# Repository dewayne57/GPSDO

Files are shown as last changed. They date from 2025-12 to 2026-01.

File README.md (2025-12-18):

# GPSDO (GPS Disciplined Oscillator)

This repository contains a hardware and firmware design for a GPS-disciplined oscillator (GPSDO). The system uses
a local oven-controlled crystal oscillator (OCXO) disciplined by a GPS reference (1PPS and time) via a digital control
loop implemented on a PIC microcontroller.

Purpose: provide a compact, buildable GPSDO that combines the short-term stability of an OCXO with the long-term
accuracy of GPS. The design favors through-hole assembly and flexible OCXO support so hobbyists and technicians can
adapt the board to available oscillators.

**Repository layout**
- `Hardware/`: KiCad schematics and PCB files, and OCXO compatibility notes.
- `Software/`: PIC firmware source (`main.c`, `isr.c`, config and peripheral drivers).

**Key features**
- Uses a PIC18F series microcontroller for the digital control loop and measurement counters.
- Supports 5 V and 12 V OCXO modules with jumper-selectable scaling.
- External DAC (12-bit) for fine VCO control; optional use of OCXO internal reference.
- Sine-to-square conversion option for sine-output OCXOs.
- Outputs: 10 MHz (square), 1PPS, and serial time/status (where supported).

Hardware notes
- OCXO compatibility: designed for OCXO modules that expose a VCO (frequency adjust) input. Modules without a VCO
	pin are not supported.
- Recommended OCXO families (examples): Bliley N47/NV47, IsoTemp 141 A/N, Vectron C4550, Oscilloquartz 8663.
- VCO adjustment: typical adjustment ranges are on the order of ±0.4 to ±1.0 ppm. For a 10 MHz OCXO, ±0.4 ppm
	corresponds to about ±4 Hz of pull range.
- Voltage reference: jumpers allow either the OCXO's onboard reference or the microcontroller-supplied reference to be
	used for VCO control circuitry.
- Power: supports 5 V and 12 V OCXO modules. The design omits 3.3 V OCXO variants to keep voltage-scaling circuitry
	simpler.

Firmware and control
- The PIC microcontroller implements the digital disciplining loop: it measures phase/frequency against GPS 1PPS and
	computes corrections applied through the DAC to the OCXO VCO input.
- Communication: firmware includes basic status reporting via serial (see `Software/` source files).

## Theory of Operation

Overview
- The system uses the PIC18F's high-speed signal acquisition timer/counter to measure the OCXO frequency against the GPS
	1PPS reference. The 10 MHz output from the OCXO (after conditioning through comparator or buffering as needed) is fed
	into the controller's counter. Each rising edge of the 1PPS signal triggers a capture of the counter value.

Measurement and error calculation
- The counter measurement produces the number of 10 MHz cycles counted during one 1-second interval. For an ideal
	10 MHz oscillator the measured count is 10,000,000. The firmware computes the frequency error as:

	`error = measured_count - 10,000,000`

- Control action sign: when `measured_count > 10,000,000` (oscillator fast) the firmware decreases the DAC output
	(reducing VCO control voltage) to lower the oscillator frequency. Conversely, when `measured_count < 10,000,000`
	(oscillator slow) the firmware increases the DAC output to raise the frequency.

Resolution and averaging
- A single 1-second count has 1 Hz quantization (one extra or missing cycle = ±1 Hz). Because the OCXO VCO pull range
	is often a few Hz, and long-term stability targets are well below 1 Hz, the firmware uses averaging and filtering
	across multiple 1‑second samples to resolve sub-Hz frequency offsets. Averaging N seconds reduces quantization noise by
	roughly `1/sqrt(N)` for uncorrelated noise and linearly for simple accumulation.

Digital control loop
- The control loop is implemented in firmware and is PID-like: it applies a proportional term (responds to the
	instantaneous frequency error), an integral term (eliminates steady-state offset over time) and optional damping
	(derivative-like or filtered difference) to stabilize transient responses.
- To avoid overshoot and instability, the loop includes:
	- limited update rate and maximum DAC-step per update,
	- anti-windup on the integrator when the DAC saturates,
	- configurable loop bandwidth (slow for best long-term stability, faster during initial acquisition).

Noise and spurious rejection
- Input conditioning: if the OCXO provides a sine output, it is converted to a clean logic edge via the comparator and
	Schmitt trigger chain (comparator `U401`, logic buffers), which reduces timing jitter and false counts.
- Outlier rejection: the firmware detects and ignores single-sample glitches (spikes) using median filters, clamp
	thresholds, or by discarding samples with implausible changes.
- Low-pass filtering: measurement samples are filtered (moving average or IIR) before being fed into the control law to
	reject short-term noise and spurious phase jitter from the GPS receiver or RF pickup.

DAC mapping and VCO sensitivity
- The external DAC (12-bit) produces the control voltage applied to the OCXO VCO pin (optionally scaled by jumper
	networks for 5/12 V OCXOs). The frequency change per DAC LSB depends on the OCXO sensitivity (Hz per volt). The
	firmware maps desired frequency correction to DAC steps and can be configured for the measured sensitivity of a
	particular OCXO.
- Because frequency pull is small (few Hz), the DAC mapping and loop gains are tuned to provide fine, stable control
	without hunting.

Holdover and failure modes
- If GPS is lost, the firmware stops updating the DAC with GPS-derived corrections and enters a holdover mode. During
	holdover the DAC will be left at its last value.
- GPS lock is indicated by a front-panel LED.  If the GPS lock is lost, the operator should take the appropriate 
    actions to reposition or repair the GPS antenna.

Practical notes
- One-count resolution at 10 MHz corresponds to 1 Hz. To achieve sub-Hz apparent resolution the firmware averages and
	filters multiple 1PPS-captured counts before making DAC adjustments.
- Avoid using OCXO modules without an external VCO adjust pin — they cannot be disciplined by this design.
- Proper grounding, shielding, and clean supply rails reduce spurious counts and improve loop stability.

Build and usage
- Hardware: assemble the board following the silkscreen and BOM in `Hardware/`. Populate only the sections required for
	your chosen OCXO (jumper options allow omitting comparator/driver or scaling components).
- Antenna: mount the GPS antenna with a clear sky view; use a low-loss cable and proper grounding/lightning protection.
- Initial setup:
	1. Install firmware from `Software/` using a PIC programmer supporting the PIC18F family.
	2. Connect GPS antenna and power the board.
	3. Wait for GPS lock and allow the disciplining loop to converge (can take minutes to hours depending on configuration).
- Holdover: if GPS signal is lost, the OCXO runs free; holdover performance depends on the OCXO quality.

Testing and calibration
- Verify 1PPS and 10 MHz outputs with a frequency counter or scope.
- Observe DAC control voltage and confirm it stays within expected range while disciplining.
- Perform a holdover test by disconnecting GPS and measuring drift over a chosen interval.

Design considerations and limitations
- GPS vulnerability: system depends on GPS; consider anti-spoofing/jamming mitigation for critical deployments.
- Environmental sensitivity: OCXO performance varies with temperature — good thermal control improves holdover.

Contributing
If you improve the firmware, PCB, or documentation, please open an issue or a pull request. Include a short description
of your changes and validation steps.

License and credits
- This entire repository (software and hardware design files) is licensed under the Apache License, Version 2.0. See
  `LICENSE` at the repository root for the full text.
- If you incorporate third-party components with separate license requirements, include their required notices and
  follow the terms of those licenses.

Files of interest
- `Hardware/GPSDO.kicad_sch`, `Hardware/GPSDO.kicad_pcb`: primary schematic and PCB.
- `Software/main.c`, `Software/isr.c`, `Software/config.h`: firmware entry points and configuration.

Contact
Open issues in this repository or contact the author via the repository metadata for questions and contribution guidance.

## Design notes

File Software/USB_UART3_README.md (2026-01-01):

# UART3 USB Interface Configuration

## Overview
UART3 has been configured for USB serial communication on the PIC18F27Q43.

## Pin Assignments
- **RB2**: USB_TX (UART3 transmit output)
- **RB3**: USB_RX (UART3 receive input)

## Configuration Details
- **Baud Rate**: 115200 (configurable via `usb_reconfigure()`)
- **Data Format**: 8-bit, no parity, 1 stop bit
- **Buffer Size**: 256 bytes circular receive buffer
- **Clock Source**: System Fosc (64 MHz)
- **BRG Value**: 139 (for 115200 baud at 64 MHz)

## PPS (Peripheral Pin Select) Routing
```c
U3RXPPS = 0x0B;  // RB3 (pin 11) -> UART3 RX input
RB2PPS = 0x33;   // UART3 TX -> RB2 output
```

## API Functions (usb.h)
### Initialization
- `void usb_init(void)` - Initialize UART3 at 115200 baud
- `void usb_reconfigure(uint32_t baudrate)` - Change baud rate

### Transmit
- `void usb_send_char(char c)` - Send single character
- `void usb_send_string(const char *str)` - Send null-terminated string

### Receive
- `void usb_buffer_put_char(char c)` - Store received character (called from ISR)
- `char usb_buffer_get_char(void)` - Get character from buffer
- `bool usb_buffer_has_data(void)` - Check if data available
- `uint8_t usb_buffer_count(void)` - Get number of buffered characters

## Interrupt Service Routine
UART3 RX interrupt handler is defined in [isr.c](isr.c):
```c
void __interrupt(irq(U3RX), high_priority) uart3_rx_isr(void)
```

The ISR handles:
- Receive buffer overflow recovery
- Character buffering via circular buffer
- Interrupt flag clearing

## Files Modified/Created
1. **usb.h** - USB/UART3 interface header
2. **usb.c** - USB/UART3 implementation
3. **isr.c** - Added UART3 RX ISR
4. **config.c** - Added `usb_init()` call
5. **nbproject/Makefile-default.mk** - Added usb.c to build

## Current UART Usage Summary
- **UART1**: External serial/bootloader (RB3 TX, RB4 RX) - 115200 baud
- **UART2**: GPS communication (RB5 TX, RB4 RX) - 9600 baud
- **UART3**: USB interface (RB2 TX, RB3 RX) - 115200 baud

## Example Usage
```c
#include "usb.h"

// Send string to USB
usb_send_string("Hello USB!\r\n");

// Check for received data
if (usb_buffer_has_data()) {
    char c = usb_buffer_get_char();
    // Process received character
}

// Change baud rate
usb_reconfigure(9600);
```

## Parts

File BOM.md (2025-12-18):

Bill of Materials (BOM) — GPSDO Project

This file is a human-friendly summary of the key parts used in this GPSDO project. The full, board-level parts list and footprints are available as a CSV exported from the KiCad project:

- Full parts list: `Hardware/GPSDO.csv`

Key components (recommended starting points)

- Microcontroller:
  - Reference: `U311` — PIC18F27Q43 (PIC18F family microcontroller used for the digital control loop)

- DAC / VCO control:
  - Reference: `U301` — DAC8571 (12-bit external DAC recommended)

- GPS receiver:
  - Reference: `U302` — u-blox NEO-M8M (or compatible module); requires SMA antenna connector `J302`

- OCXO (examples supported):
  - `X401` — IsoTemp 131
  - `X402` — Bliley N47 / NV47
  - `X403` — IsoTemp 143N and 143A
  - `X404` — Vectron C4550A
  - `X406` — Oscilloquartz 8663
  - Note: board supports 5 V and 12 V OCXO variants; OCXOs must expose a VCO adjustment pin.

- Analog / amplifier:
  - `U306` — GALI-52 (RF amplifier for 10 MHz / output driver)
  - `U303`, `U304` — OP07 (precision op amps used in analog sections)
  - `U401` — ADCMP600 (comparator for sine-to-square conversion)

- Level translators / logic:
  - `U305` — TXS0108E (8-bit level translator)
  - `U307`, `U308`, `U402` — 74LVC1G17 (single buffer/driver)
  - `U309` — MCP23017 (I/O expander)
  - `U310` — 24AA02 (I2C EEPROM)

- Power / regulators:
  - `U201` — LM7912 (negative regulator)
  - `U202` — LM2574N-3.3 (switching regulator for 3.3 V)
  - `U203`, `U204` — LM2596 (5 V and 12 V switching regulators)

- RF / connectors and passive items:
  - GPS SMA connector: `J302`
  - RF SMA output: `J308` (50 Ω)
  - 1PPS and TTL outputs: `J310` etc.
  - Battery: `BT301` — CR2032 (backup battery for RTC or similar)

- Other notable items:
  - `U307`, `U308` — logic buffers
  - `Q301` — 2N3904 (general transistor)
  - Various axial/toroidal inductors and power transformers listed in `Hardware/GPSDO.csv`

How the CSV maps to the BOM

- `Hardware/GPSDO.csv` contains the full reference designators, quantities, values, footprints, datasheets, and (where available) manufacturer / Mouser part numbers and links. Use that CSV for procurement and PCB assembly.

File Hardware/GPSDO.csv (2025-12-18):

Reference | Qty | Value | DNP | Exclude from BOM | Exclude from Board | Footprint | Datasheet | Manufacturer_Name | Mouser Part Number | Mouser Price/Stock
BT301 | 1 | CR2302 |  |  |  | Battery:Battery_Panasonic_CR2032-HFN_Horizontal_CircularHoles | ~
C201,C202,C203,C204,C205,C206 | 6 | 2200 |  |  |  | SamacSys_Parts:C731U222MSVDBAWL35 | https://search.kemet.com/component-documentation/download/datasheet/C731U222MSVDBAWL35.pdf | KEMET | 80-C731U222MSVDBWL35 | https://www.mouser.co.uk/ProductDetail/KEMET/C731U222MSVDBAWL35?qs=IPgv5n7u5Qbcfu31hG8%252BLA%3D%3D
C207,C208,C209,C210 | 4 | 2000 |  |  |  | Capacitor_THT:CP_Radial_D22.0mm_P10.00mm_SnapIn | ~
C211,C213,C214 | 3 | 330 |  |  |  | Capacitor_THT:CP_Radial_D10.0mm_P5.00mm | ~
C212,C215 | 2 | 220 |  |  |  | Capacitor_THT:CP_Radial_D8.0mm_P5.00mm | ~
C216,C217 | 2 | 180 |  |  |  | Capacitor_THT:CP_Radial_D8.0mm_P5.00mm | ~
C301 | 1 | .5F |  |  |  | Capacitor_THT:DX_5R5VxxxxU_D11.5mm_P5.00mm | ~
C302,C304 | 2 | 100n |  |  |  | Capacitor_THT:C_Axial_L3.8mm_D2.6mm_P15.00mm_Horizontal
C303 | 1 | 47 |  |  |  | Capacitor_THT:CP_Radial_D8.0mm_P5.00mm | ~
C305 | 1 | 0.1 |  |  |  | Capacitor_THT:C_Axial_L3.8mm_D2.6mm_P15.00mm_Horizontal
C306 | 1 | 47 |  |  |  |  | ~
C307 | 1 | 0.1
C401 | 1 | 220p |  |  |  | Capacitor_THT:C_Axial_L3.8mm_D2.6mm_P10.00mm_Horizontal
D201 | 1 | GBU6A |  |  |  | Diode_THT:Diode_Bridge_Vishay_GBU | http://www.vishay.com/docs/88656/gbu6a.pdf
D202,D301,D313,D314 | 4 | 1N5819 |  |  |  | Diode_THT:D_DO-41_SOD81_P10.16mm_Horizontal | http://www.vishay.com/docs/88525/1n5817.pdf
D203,D204 | 2 | 1N5822 |  |  |  | Diode_THT:D_DO-201AD_P15.24mm_Horizontal | http://www.vishay.com/docs/88526/1n5820.pdf
D302,D303,D304,D305 | 4 | SS38 |  |  |  | Diode_SMD:D_SMA | https://www.microdiode.com/uploadfiles//PDF/SS32-THRU-SS3200-SMA.pdf
D306,D307,D308,D309,D310,D311,D312 | 7 | LED |  |  |  | LED_THT:LED_D3.0mm_Horizontal_O3.81mm_Z2.0mm | ~
D401,D402,D403,D404 | 4 | 1N4148W |  |  |  | Diode_THT:D_DO-15_P10.16mm_Horizontal | https://www.vishay.com/docs/85748/1n4148w.pdf
F301,F302 | 2 | 0805L010 |  |  |  | Resistor_SMD:R_0805_2012Metric_Pad1.20x1.40mm_HandSolder | ~
FB301,FB302 | 2 | Bead |  |  |  | Ferrite_THT:LairdTech_28C0236-0JW-10 | ~
J201 | 1 | Line |  |  |  | DH_Hardware:Amp Faston 250 THT | ~
J202 | 1 | Earth |  |  |  | DH_Hardware:Amp Faston 250 THT | ~
J203 | 1 | Neutral |  |  |  | DH_Hardware:Amp Faston 250 THT | ~
J204 | 1 | 44472-0453 |  |  |  | SamacSys_Parts:44472-04YY | https://componentsearchengine.com/Datasheets/1/44472-0453.pdf | Molex | 538-44472-0453 | https://www.mouser.com/Search/Refine.aspx?Keyword=538-44472-0453
J301 | 1 | Ref Divider |  |  |  | Connector_PinSocket_2.54mm:PinSocket_2x02_P2.54mm_Vertical | ~
J302 | 1 | GPS ANT |  |  |  | Connector_Coaxial:SMA_Amphenol_901-144_Vertical | ~
J303 | 1 | Encoder |  |  |  | Connector_PinSocket_2.54mm:PinSocket_1x06_P2.54mm_Vertical | ~
J304 | 1 | Ref Select |  |  |  | Connector_PinSocket_2.54mm:PinSocket_1x03_P2.54mm_Vertical | ~
J305 | 1 | Ref Range |  |  |  | Connector_PinSocket_2.54mm:PinSocket_1x03_P2.54mm_Vertical | ~
J306 | 1 | GPS Module |  |  |  | Connector_PinSocket_2.54mm:PinSocket_1x05_P2.54mm_Vertical | ~
J307 | 1 | LCD |  |  |  | Connector_PinSocket_2.54mm:PinSocket_1x15_P2.54mm_Vertical | ~
J308 | 1 | RF 50 Ohm |  |  |  | Connector_Coaxial:SMA_Amphenol_901-144_Vertical | ~
J309 | 1 | RF TTL |  |  |  | Connector_Coaxial:SMA_Amphenol_901-144_Vertical | ~
J310 | 1 | 1PPS TTL |  |  |  | Connector_Coaxial:SMA_Amphenol_901-144_Vertical | ~
J311 | 1 | ICSP |  |  |  | Connector_PinSocket_2.54mm:PinSocket_1x05_P2.54mm_Vertical | ~
J401,J402,J405 | 3 | OCXO |  |  |  | Connector_PinHeader_2.54mm:PinHeader_1x06_P2.54mm_Vertical | ~
J403 | 1 | OCXO Signal |  |  |  | Connector_PinHeader_2.54mm:PinHeader_1x03_P2.54mm_Vertical | ~
J404 | 1 | OCXO Voltage |  |  |  | Connector_PinHeader_2.54mm:PinHeader_1x03_P2.54mm_Vertical | ~
JP201 | 1 | Tie |  |  |  |  | ~
L201 | 1 | 330uH |  |  |  | DH_Inductors:Bourns PM5022 | https://www.mouser.com/datasheet/3/40/1/pm5022_series.pdf
L202 | 1 | 47uH |  |  |  | DH_Inductors:Bourns PM5022 | ~
L203 | 1 | 68uH |  |  |  | DH_Inductors:Bourns PM5022 | ~
L204,L205,L206 | 3 | 3.3uH |  |  |  | DH_Inductors:Bourns SDE04030 | https://www.mouser.com/catalog/specsheets/Bourns_9-3-2025_SDE0403AT_Datasheet.pdf,~
L301 | 1 | 1 uH |  |  |  | Inductor_THT:L_Axial_L7.0mm_D3.3mm_P10.16mm_Horizontal_Fastron_MICC | ~
Q301 | 1 | 2N3904 |  |  |  | Package_TO_SOT_THT:TO-92L_HandSolder | https://www.onsemi.com/pub/Collateral/2N3903-D.PDF
R201,R202 | 2 | 4.7K |  |  |  | Resistor_THT:R_Axial_DIN0204_L3.6mm_D1.6mm_P7.62mm_Horizontal | ~
R203,R309 | 2 | 2.2K |  |  |  | Resistor_THT:R_Axial_DIN0204_L3.6mm_D1.6mm_P7.62mm_Horizontal | ~
R204,R205,R206 | 3 | 1 |  |  |  | Resistor_THT:R_Axial_DIN0204_L3.6mm_D1.6mm_P7.62mm_Horizontal | ~
R207 | 1 | 10K |  |  |  | Resistor_THT:R_Axial_DIN0204_L3.6mm_D1.6mm_P7.62mm_Horizontal | ~
R208 | 1 | 22K |  |  |  | Resistor_THT:R_Axial_DIN0204_L3.6mm_D1.6mm_P7.62mm_Horizontal | ~
R209 | 1 | 47K |  |  |  | Resistor_THT:R_Axial_DIN0204_L3.6mm_D1.6mm_P7.62mm_Horizontal | ~
R301 | 1 | 3.3 |  |  |  | Resistor_THT:R_Axial_DIN0204_L3.6mm_D1.6mm_P7.62mm_Horizontal | ~
R302,R303,R304,R305 | 4 | 51.1K |  |  |  | Resistor_THT:R_Axial_DIN0204_L3.6mm_D1.6mm_P7.62mm_Horizontal | ~
R306 | 1 | 4.7K |  |  |  | Resistor_THT:R_Axial_DIN0207_L6.3mm_D2.5mm_P10.16mm_Horizontal | ~
R307,R315,R316,R317,R318,R319,R320,R321 | 8 | 330 |  |  |  | Resistor_THT:R_Axial_DIN0204_L3.6mm_D1.6mm_P7.62mm_Horizontal | ~
R308,R312,R313 | 3 | 150 |  |  |  | Resistor_THT:R_Axial_DIN0204_L3.6mm_D1.6mm_P7.62mm_Horizontal | ~
R310,R314 | 2 | 8.55 |  |  |  | Resistor_THT:R_Axial_DIN0204_L3.6mm_D1.6mm_P7.62mm_Horizontal | ~
R311 | 1 | 142 |  |  |  | Resistor_THT:R_Axial_DIN0204_L3.6mm_D1.6mm_P7.62mm_Horizontal | ~
R401 | 1 | 470 |  |  |  |  | ~
R402,R403,R404,R405 | 4 | 100K |  |  |  | Resistor_THT:R_Axial_DIN0207_L6.3mm_D2.5mm_P10.16mm_Horizontal | ~
R406 | 1 | 470 |  |  |  | Resistor_THT:R_Axial_DIN0207_L6.3mm_D2.5mm_P10.16mm_Horizontal | ~
RT201,RT202 | 2 | N10SP005M |  |  |  | SamacSys_Parts:N10SP005M | https://www.yageo.com/upload/media/product/productsearch/datasheet/cpc/ntc/SP_1.pdf | YAGEO | 603-N10SP005M | https://www.mouser.co.uk/ProductDetail/YAGEO/N10SP005M?qs=DRkmTr78QARsu2IwnsFFfg%3D%3D
RV201,RV202,RV203 | 3 | 150V |  |  |  | SamacSys_Parts:MOV20D241KKTR | https://www.bourns.com/docs/product-datasheets/mov20d.pdf | Bourns | 652-MOV-20D241KKTR | https://www.mouser.com/ProductDetail/Bourns/MOV-20D241KKTR?qs=ST9lo4GX8V1zjVcH%2FsSYdQ%3D%3D
RV301 | 1 | 1K |  |  |  | Potentiometer_THT:Potentiometer_Bourns_3266W_Vertical | ~
SW201 | 1 | SW_DPST |  |  |  |  | ~
T201 | 1 | B82732R2142 |  |  |  | SamacSys_Parts:B82732R2142B030 | https://product.tdk.com/system/files/dam/doc/product/emc/emc/line-filter/data_sheet/30/db/ind_2008/b82732r_w.pdf
T202 | 1 | 14A-56-28 |  |  |  | Transformers_Signal:14A-56
TP201 | 1 | Gnd |  |  |  | TestPoint:TestPoint_Bridge_Pitch2.54mm_Drill1.0mm | ~
TP202 | 1 | +19.8 |  |  |  | TestPoint:TestPoint_Bridge_Pitch2.54mm_Drill1.0mm | ~
TP203 | 1 | -19.8 |  |  |  | TestPoint:TestPoint_Bridge_Pitch2.54mm_Drill1.0mm | ~
TP204 | 1 | -12 |  |  |  | TestPoint:TestPoint_Bridge_Pitch2.54mm_Drill1.0mm | ~
TP205 | 1 | +3.3 |  |  |  | TestPoint:TestPoint_Bridge_Pitch2.54mm_Drill1.0mm | ~
TP206 | 1 | +5 |  |  |  | TestPoint:TestPoint_Bridge_Pitch2.54mm_Drill1.0mm | ~
TP207 | 1 | +12 |  |  |  | TestPoint:TestPoint_Bridge_Pitch2.54mm_Drill1.0mm | ~
TP301 | 1 | Clock |  |  |  | TestPoint:TestPoint_Bridge_Pitch2.54mm_Drill1.0mm | ~
TP302 | 1 | VRef |  |  |  | TestPoint:TestPoint_Bridge_Pitch2.54mm_Drill1.0mm | ~
TP303 | 1 | VCO |  |  |  | TestPoint:TestPoint_Bridge_Pitch2.54mm_Drill1.0mm | ~
TP304 | 1 | 1PPS |  |  |  | TestPoint:TestPoint_Bridge_Pitch2.54mm_Drill1.0mm | ~
TP305 | 1 | RF |  |  |  | TestPoint:TestPoint_Bridge_Pitch2.54mm_Drill1.0mm | ~
U201 | 1 | LM7912 |  |  |  | Package_TO_SOT_THT:TO-220-3_Vertical | hhttps://www.onsemi.com/pub/Collateral/MC7900-D.PDF
U202 | 1 | LM2574N-3.3 |  |  |  | Package_DIP:DIP-8_W7.62mm | http://www.national.com/ds/LM/LM2574.pdf
U203 | 1 | LM2596T-5 |  |  |  | Package_TO_SOT_THT:TO-220-5_P3.4x3.7mm_StaggerOdd_Lead3.8mm_Vertical | http://www.ti.com/lit/ds/symlink/lm2596.pdf
U204 | 1 | LM2596T-12 |  |  |  | Package_TO_SOT_THT:TO-220-5_P3.4x3.7mm_StaggerOdd_Lead3.8mm_Vertical | http://www.ti.com/lit/ds/symlink/lm2596.pdf
U301 | 1 | DAC8571IDGK |  |  |  | Package_SO:MSOP-8_3x3mm_P0.65mm | https://www.ti.com/lit/ds/symlink/dac8571.pdf
U302 | 1 | NEO-M8M |  |  |  | RF_GPS:ublox_NEO | https://content.u-blox.com/sites/default/files/NEO-M8-FW3_DataSheet_UBX-15031086.pdf
U303,U304 | 2 | OP07 |  |  |  | Package_SO:SOIC-8_3.9x4.9mm_P1.27mm | https://www.analog.com/media/en/technical-documentation/data-sheets/OP07.pdf
U305 | 1 | TXS0108EPW |  |  |  | Package_SO:TSSOP-20_4.4x6.5mm_P0.65mm | www.ti.com/lit/ds/symlink/txs0108e.pdf
U306 | 1 | GALI-52 |  |  |  | Package_TO_SOT_SMD:SOT-89-3 | https://www.minicircuits.com/pdfs/GALI-52+.pdf
U307,U308,U402 | 3 | 74LVC1G17 |  |  |  | Package_TO_SOT_SMD:SOT-353_SC-70-5 | https://www.ti.com/lit/ds/symlink/sn74lvc1g17.pdf
U309 | 1 | MCP23017_SO |  |  |  | Package_SO:SOIC-28W_7.5x17.9mm_P1.27mm | https://ww1.microchip.com/downloads/aemDocuments/documents/APID/ProductDocuments/DataSheets/MCP23017-Data-Sheet-DS20001952.pdf
U310 | 1 | 24AA02-OT |  |  |  | Package_TO_SOT_SMD:SOT-23-5 | http://ww1.microchip.com/downloads/en/DeviceDoc/21709J.pdf
U311 | 1 | PIC18F27Q43 |  |  |  | Package_SO:SOIC-28W_7.5x18.7mm_P1.27mm
U401 | 1 | ADCMP600 |  |  |  | Package_TO_SOT_SMD:SOT-23-5
X401 | 1 | IsoTemp 131 |  |  |  | DH_OCXO:ISOTEMP 131
X402 | 1 | Bliley N47/NV47 |  |  |  | DH_OCXO:Bliley N47
X403 | 1 | IsoTemp 143N |  |  |  | DH_OCXO:ISOTEMP 143N
X404 | 1 | VECTRON C4550A |  |  |  | DH_OCXO:C4550-OCXO
X405 | 1 | IsoTemp 143A |  |  |  | DH_OCXO:ISOTEMP 143A
X406 | 1 | Oscilloquartz 8663 |  |  |  | DH_OCXO:OQ8663

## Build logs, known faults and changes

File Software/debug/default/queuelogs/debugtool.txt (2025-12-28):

330 1766956881826 GEN4_TO_CONTROLLER_LOG:GEN4_CONNECT_INT_LOG_PIC18F27Q43 FirmwareInfo: Values:
330 1766956881826 GEN4_TO_CONTROLLER_LOG:GEN4_CONNECT_INT_LOG_PIC18F27Q43 FirmwareInfo: boot = false, bootVer = 00.00.68, apVer = 02.05.47, fpgaVer = ff.ff.ff, scriptVer = 00.10.08, macAddress = 0504883548174844851484953485250, devID = a1020e01, devID1 = 2, devSN0 = ffffffff, devSN1 = ffffffff, serialNumber = 020026702RYN005992, appCommitID = null, scriptCommitID = f91823efd7, PCB_ID = 2
330 1766956881826 GEN4_TO_CONTROLLER_LOG:GEN4_CONNECT_INT_LOG_PIC18F27Q43 Return End
330 1766956881830 XXXX 1766956881830, Thread 330: XXXX 1766956881830, Entering Thread 330: Commands::runScriptWithUpload with script contents. contents[0] = 0x5e, ...  
330 1766956881832 XXXX 1766956881832, Thread 330: XXXX 1766956881832, Entering Thread 330: ToolCommUsb::readTransfer, sideData is 0xd bytes long, transferDataLength is 0x4 bytes long  
330 1766956881836 XXXX 1766956881836, Thread 330: XXXX 1766956881836, Exiting Thread 330: ToolCommUsb::readTransfer,  cr.status = 0x0  
330 1766956881836 XXXX 1766956881836, Thread 330: XXXX 1766956881836, Exiting Thread 330: Commands::runScriptWithUpload  
330 1766956881836 GEN4_CONNECT_DIAGNOSTICS:ENTERING: com.microchip.mplab.mdbcore.RI4Tool.ConnectionHandler.CheckForFWUpdates()
330 1766956881840 GEN4_CONNECT_DIAGNOSTICS:Created FirmwareUpdateHandler com.microchip.mplab.mdbcore.PK5Tool.PK5FirmwareUpdateHandler@35e3b0c7
330 1766956881840 GEN4_CONNECT_DIAGNOSTICS:ENTERING: com.microchip.mplab.mdbcore.RI4Tool.FirmwareUpdateHandler.GetUpdateInfo()
330 1766956881841 GEN4_CONNECT_DIAGNOSTICS:Parsing file  for firmware updates
330 1766956881841 GEN4_CONNECT_DIAGNOSTICS:ENTERING: com.microchip.mplab.mdbcore.RI4Tool.FirmwareUpdateHandler.ri4ParseSelectedVersionsFromJamFile()
330 1766956881842 GEN4_CONNECT_DIAGNOSTICS:Jame file line = app.hex,020547
330 1766956881842 GEN4_CONNECT_DIAGNOSTICS:Jame file line = boot.hex,000068
330 1766956881842 GEN4_CONNECT_DIAGNOSTICS:Jame file line = scripts.xml,001008
330 1766956881842 GEN4_CONNECT_DIAGNOSTICS:Selected firmware version for Boot = 00.00.68
330 1766956881842 GEN4_CONNECT_DIAGNOSTICS:Selected firmware version for ap = 02.05.47
330 1766956881842 GEN4_CONNECT_DIAGNOSTICS:EXITING: com.microchip.mplab.mdbcore.RI4Tool.FirmwareUpdateHandler.ri4ParseSelectedVersionsFromJamFile()
330 1766956881842 GEN4_CONNECT_DIAGNOSTICS:EXITING: com.microchip.mplab.mdbcore.RI4Tool.FirmwareUpdateHandler.GetUpdateInfo()
330 1766956881842 GEN4_CONNECT_DIAGNOSTICS:ENTERING: com.microchip.mplab.mdbcore.RI4Tool.FirmwareUpdateHandler.updateRI4ToolsFirmware(FirmwareInfo, UpdateMessage)
330 1766956881851 GEN4_CONNECT_DIAGNOSTICS:appNeedsUpdate returned false
330 1766956881851 GEN4_CONNECT_DIAGNOSTICS:EXITING: com.microchip.mplab.mdbcore.RI4Tool.FirmwareUpdateHandler.updateRI4ToolsFirmware(FirmwareInfo, UpdateMessage)
330 1766956881851 GEN4_CONNECT_DIAGNOSTICS:EXITING: com.microchip.mplab.mdbcore.RI4Tool.ConnectionHandler.CheckForFWUpdates()

330 1766956881853 GEN4_TO_CONTROLLER_LOG:GEN4_CONNECT_INT_LOG_PIC18F27Q43 Pre:SetPowerInfo
330 1766956881853 GEN4_TO_CONTROLLER_LOG:GEN4_CONNECT_INT_LOG_PIC18F27Q43 Payload
330 1766956881853 GEN4_TO_CONTROLLER_LOG:GEN4_CONNECT_INT_LOG_PIC18F27Q43 PowerInfo: Values:
330 1766956881853 GEN4_TO_CONTROLLER_LOG:GEN4_CONNECT_INT_LOG_PIC18F27Q43 PowerInfo: shotDownSystem = false, isToolPower = false, voltage = 5.000000, useVppFirst = false, useLowVoltageProgramming = false, useMaintainActivePower = false
330 1766956881853 GEN4_TO_CONTROLLER_LOG:GEN4_CONNECT_INT_LOG_PIC18F27Q43 Payload End
330 1766956881853 XXXX 1766956881853, Thread 330: XXXX 1766956881853, Entering Thread 330: Commands::runScriptBasic with script contents. contents[0] = 0x39, ...  
330 1766956881855 XXXX 1766956881855, Thread 330: XXXX 1766956881855, Exiting Thread 330: Commands::runScriptBasic  
330 1766956881855 XXXX 1766956881855, Thread 330: XXXX 1766956881855, Entering Thread 330: Commands::runScriptBasic with script contents. contents[0] = 0x46, ...  
330 1766956881856 XXXX 1766956881856, Thread 330: XXXX 1766956881856, Exiting Thread 330: Commands::runScriptBasic  
330 1766956881856 XXXX 1766956881856, Thread 330: XXXX 1766956881856, Entering Thread 330: Commands::runScriptBasic with script contents. contents[0] = 0x44, ...  
330 1766956881868 XXXX 1766956881868, Thread 330: XXXX 1766956881868, Exiting Thread 330: Commands::runScriptBasic  
330 1766956881868 XXXX 1766956881868, Thread 330: XXXX 1766956881868, Entering Thread 330: Commands::runScriptBasic with script contents. contents[0] = 0xef, ...  
330 1766956881880 XXXX 1766956881880, Thread 330: XXXX 1766956881880, Exiting Thread 330: Commands::runScriptBasic  
330 1766956881880 XXXX 1766956881880, Thread 330: XXXX 1766956881880, Entering Thread 330: Commands::runScriptBasic with script contents. contents[0] = 0x40, ...  
330 1766956882281 XXXX 1766956882281, Thread 330: XXXX 1766956882281, Exiting Thread 330: Commands::runScriptBasic  
330 1766956882281 XXXX 1766956882281, Thread 330: XXXX 1766956882281, Entering Thread 330: Commands::runScriptBasic with script contents. contents[0] = 0x47, ...  
330 1766956882286 XXXX 1766956882286, Thread 330: XXXX 1766956882286, Exiting Thread 330: Commands::runScriptBasic  
330 1766956882286 GEN4_TO_CONTROLLER_LOG:GEN4_CONNECT_INT_LOG_PIC18F27Q43 Post:SetPowerInfo
330 1766956882286 GEN4_TO_CONTROLLER_LOG:GEN4_CONNECT_INT_LOG_PIC18F27Q43 Return Value
330 1766956882286 GEN4_TO_CONTROLLER_LOG:GEN4_CONNECT_INT_LOG_PIC18F27Q43 none
330 1766956882286 GEN4_TO_CONTROLLER_LOG:GEN4_CONNECT_INT_LOG_PIC18F27Q43 Return End

330 1766956882286 GEN4_TO_CONTROLLER_LOG:GEN4_CONNECT_INT_LOG_PIC18F27Q43 Pre:SetLEDBrightness
330 1766956882286 GEN4_TO_CONTROLLER_LOG:GEN4_CONNECT_INT_LOG_PIC18F27Q43 Payload
330 1766956882286 GEN4_TO_CONTROLLER_LOG:GEN4_CONNECT_INT_LOG_PIC18F27Q43 5
330 1766956882286 GEN4_TO_CONTROLLER_LOG:GEN4_CONNECT_INT_LOG_PIC18F27Q43 Payload End
330 1766956882286 XXXX 1766956882286, Thread 330: XXXX 1766956882286, Entering Thread 330: Commands::runScriptBasic with script contents. contents[0] = 0xcf, ...  
330 1766956882288 XXXX 1766956882288, Thread 330: XXXX 1766956882288, Exiting Thread 330: Commands::runScriptBasic  
330 1766956882288 GEN4_TO_CONTROLLER_LOG:GEN4_CONNECT_INT_LOG_PIC18F27Q43 Post:SetLEDBrightness
330 1766956882288 GEN4_TO_CONTROLLER_LOG:GEN4_CONNECT_INT_LOG_PIC18F27Q43 Return Value
330 1766956882288 GEN4_TO_CONTROLLER_LOG:GEN4_CONNECT_INT_LOG_PIC18F27Q43 none
330 1766956882288 GEN4_TO_CONTROLLER_LOG:GEN4_CONNECT_INT_LOG_PIC18F27Q43 Return End

330 1766956882288 GEN4_TO_CONTROLLER_LOG:GEN4_CONNECT_INT_LOG_PIC18F27Q43 Pre:SetToolInfo
330 1766956882288 GEN4_TO_CONTROLLER_LOG:GEN4_CONNECT_INT_LOG_PIC18F27Q43 Payload
330 1766956882288 GEN4_TO_CONTROLLER_LOG:GEN4_CONNECT_INT_LOG_PIC18F27Q43 ToolInfo: Values:
330 1766956882288 GEN4_TO_CONTROLLER_LOG:GEN4_CONNECT_INT_LOG_PIC18F27Q43 ToolInfo: speedLevel = 1, PGCResistance = 4700, PGDResistance = 4700, PGCPullDir = PullDown, PGDPullDir = PullDown, ICSPSelected = Wire2
330 1766956882288 GEN4_TO_CONTROLLER_LOG:GEN4_CONNECT_INT_LOG_PIC18F27Q43 Payload End
330 1766956882289 XXXX 1766956882289, Thread 330: XXXX 1766956882289, Entering Thread 330: Commands::runScriptBasic with script contents. contents[0] = 0x27, ...  
330 1766956882290 XXXX 1766956882290, Thread 330: XXXX 1766956882290, Exiting Thread 330: Commands::runScriptBasic  
330 1766956882290 XXXX 1766956882290, Thread 330: XXXX 1766956882290, Entering Thread 330: Commands::runScriptBasic, script name = SetSpeedFromDevice, timeOut = -1 ms  
330 1766956882291 XXXX 1766956882291, Thread 330: XXXX 1766956882291, Exiting Thread 330: Commands::runScriptBasic  
330 1766956882291 XXXX 1766956882291, Thread 330: XXXX 1766956882291, Entering Thread 330: Commands::runScriptBasic with script contents. contents[0] = 0xed, ...  
330 1766956882292 XXXX 1766956882292, Thread 330: XXXX 1766956882292, Exiting Thread 330: Commands::runScriptBasic  
330 1766956882292 XXXX 1766956882292, Thread 330: XXXX 1766956882292, Entering Thread 330: Commands::runScriptBasic with script contents. contents[0] = 0xec, ...  
330 1766956882293 XXXX 1766956882293, Thread 330: XXXX 1766956882293, Exiting Thread 330: Commands::runScriptBasic  
330 1766956882293 XXXX 1766956882293, Thread 330: XXXX 1766956882293, Entering Thread 330: Commands::runScriptBasic with script contents. contents[0] = 0xd4, ...  
330 1766956882294 XXXX 1766956882294, Thread 330: XXXX 1766956882294, Exiting Thread 330: Commands::runScriptBasic  
330 1766956882294 XXXX 1766956882294, Thread 330: XXXX 1766956882294, Entering Thread 330: Commands::runScriptBasic with script contents. contents[0] = 0xcd, ...  
330 1766956882295 XXXX 1766956882295, Thread 330: XXXX 1766956882295, Exiting Thread 330: Commands::runScriptBasic  
330 1766956882295 XXXX 1766956882295, Thread 330: XXXX 1766956882295, Entering Thread 330: Commands::runScriptBasic with script contents. contents[0] = 0xce, ...  
330 1766956882296 XXXX 1766956882296, Thread 330: XXXX 1766956882296, Exiting Thread 330: Commands::runScriptBasic  
330 1766956882296 XXXX 1766956882296, Thread 330: XXXX 1766956882296, Entering Thread 330: Commands::runScriptBasic with script contents. contents[0] = 0xcd, ...  
330 1766956882297 XXXX 1766956882297, Thread 330: XXXX 1766956882297, Exiting Thread 330: Commands::runScriptBasic  
330 1766956882297 XXXX 1766956882297, Thread 330: XXXX 1766956882297, Entering Thread 330: Commands::runScriptBasic with script contents. contents[0] = 0xce, ...  
330 1766956882298 XXXX 1766956882298, Thread 330: XXXX 1766956882298, Exiting Thread 330: Commands::runScriptBasic  
330 1766956882298 GEN4_TO_CONTROLLER_LOG:GEN4_CONNECT_INT_LOG_PIC18F27Q43 Post:SetToolInfo
330 1766956882298 GEN4_TO_CONTROLLER_LOG:GEN4_CONNECT_INT_LOG_PIC18F27Q43 Return Value
330 1766956882298 GEN4_TO_CONTROLLER_LOG:GEN4_CONNECT_INT_LOG_PIC18F27Q43 none
330 1766956882298 GEN4_TO_CONTROLLER_LOG:GEN4_CONNECT_INT_LOG_PIC18F27Q43 Return End

330 1766956882302 GEN4_TO_CONTROLLER_LOG:GEN4_PROGRAM_INT_LOG_PIC18F27Q43 Pre:SendOperation
330 1766956882302 GEN4_TO_CONTROLLER_LOG:GEN4_PROGRAM_INT_LOG_PIC18F27Q43 Payload
330 1766956882302 GEN4_TO_CONTROLLER_LOG:GEN4_PROGRAM_INT_LOG_PIC18F27Q43 OperationInfo: Values:
330 1766956882302 GEN4_TO_CONTROLLER_LOG:GEN4_PROGRAM_INT_LOG_PIC18F27Q43 OperationInfo: Type = read, Mask = 00000000, Erase = false, Production Mode = true
330 1766956882302 GEN4_TO_CONTROLLER_LOG:GEN4_PROGRAM_INT_LOG_PIC18F27Q43 TransferInfo: Start = 300003, End = 300003, Buffer Length = 1, Type = Cfg, Mask = 00000000
330 1766956882302 GEN4_TO_CONTROLLER_LOG:GEN4_PROGRAM_INT_LOG_PIC18F27Q43 Payload End
330 1766956882302 XXXX 1766956882302, Thread 330: XXXX 1766956882302, Entering Thread 330: Commands::runScriptBasic, script name = SetSpeedFromDevice, timeOut = -1 ms  
330 1766956882303 XXXX 1766956882303, Thread 330: XXXX 1766956882303, Exiting Thread 330: Commands::runScriptBasic  
330 1766956882303 XXXX 1766956882303, Thread 330: XXXX 1766956882303, Entering Thread 330: Commands::runScriptBasic with script contents. contents[0] = 0xed, ...  
330 1766956882304 XXXX 1766956882304, Thread 330: XXXX 1766956882304, Exiting Thread 330: Commands::runScriptBasic  
330 1766956882304 XXXX 1766956882304, Thread 330: XXXX 1766956882304, Entering Thread 330: Commands::runScriptBasic with script contents. contents[0] = 0xec, ...  
330 1766956882305 XXXX 1766956882305, Thread 330: XXXX 1766956882305, Exiting Thread 330: Commands::runScriptBasic  
330 1766956882305 XXXX 1766956882305, Thread 330: XXXX 1766956882305, Entering Thread 330: Commands::runScriptBasic, script name = EnterTMOD_HV, timeOut = -1 ms  
330 1766956882336 XXXX 1766956882336, Thread 330: XXXX 1766956882336, Exiting Thread 330: Commands::runScriptBasic  
330 1766956882337 XXXX 1766956882337, Thread 330: XXXX 1766956882337, Entering Thread 330: Commands::runScriptBasic, script name = SetSpeedFromDevice, timeOut = -1 ms  
330 1766956882338 XXXX 1766956882338, Thread 330: XXXX 1766956882338, Exiting Thread 330: Commands::runScriptBasic  
330 1766956882338 XXXX 1766956882338, Thread 330: XXXX 1766956882338, Entering Thread 330: Commands::runScriptBasic with script contents. contents[0] = 0xed, ...  
330 1766956882339 XXXX 1766956882339, Thread 330: XXXX 1766956882339, Exiting Thread 330: Commands::runScriptBasic  
330 1766956882339 XXXX 1766956882339, Thread 330: XXXX 1766956882339, Entering Thread 330: Commands::runScriptBasic with script contents. contents[0] = 0xec, ...  
330 1766956882340 XXXX 1766956882340, Thread 330: XXXX 1766956882340, Exiting Thread 330: Commands::runScriptBasic  
330 1766956882340 XXXX 1766956882340, Thread 330: XXXX 1766956882340, Entering Thread 330: Commands::runScriptBasic, script name = EnterTMOD_HV, timeOut = -1 ms  
330 1766956882369 XXXX 1766956882369, Thread 330: XXXX 1766956882369, Exiting Thread 330: Commands::runScriptBasic  
330 1766956882369 XXXX 1766956882369, Thread 330: XXXX 1766956882369, Entering Thread 330: Commands::runScriptWithUpload, script name = ReadConfigmem  
330 1766956882369 XXXX 1766956882369, Thread 330: XXXX 1766956882369, Entering Thread 330: ToolCommUsb::readTransfer, sideData is 0x37 bytes long, transferDataLength is 0x2 bytes long  
330 1766956882419 XXXX 1766956882419, Thread 330: XXXX 1766956882419, Exiting Thread 330: ToolCommUsb::readTransfer,  cr.status = 0x0  
330 1766956882419 XXXX 1766956882419, Thread 330: XXXX 1766956882419, Exiting Thread 330: Commands::runScriptWithUpload  
330 1766956882419 XXXX 1766956882419, Thread 330: XXXX 1766956882419, Entering Thread 330: Commands::runScriptBasic, script name = ExitTMOD, timeOut = -1 ms  
330 1766956882421 XXXX 1766956882421, Thread 330: XXXX 1766956882421, Exiting Thread 330: Commands::runScriptBasic  
330 1766956882421 GEN4_TO_CONTROLLER_LOG:GEN4_PROGRAM_INT_LOG_PIC18F27Q43 Post:SendOperation
330 1766956882421 GEN4_TO_CONTROLLER_LOG:GEN4_PROGRAM_INT_LOG_PIC18F27Q43 Return Value
330 1766956882421 GEN4_TO_CONTROLLER_LOG:GEN4_PROGRAM_INT_LOG_PIC18F27Q43 None
330 1766956882421 GEN4_TO_CONTROLLER_LOG:GEN4_PROGRAM_INT_LOG_PIC18F27Q43 Return End

330 1766956882422 GEN4_TO_CONTROLLER_LOG:GEN4_CONNECT_INT_LOG_PIC18F27Q43 Pre:GetTargetIDInfo
330 1766956882422 GEN4_TO_CONTROLLER_LOG:GEN4_CONNECT_INT_LOG_PIC18F27Q43 Payload
330 1766956882422 GEN4_TO_CONTROLLER_LOG:GEN4_CONNECT_INT_LOG_PIC18F27Q43 null
330 1766956882422 GEN4_TO_CONTROLLER_LOG:GEN4_CONNECT_INT_LOG_PIC18F27Q43 Payload End
330 1766956882424 XXXX 1766956882424, Thread 330: XXXX 1766956882424, Entering Thread 330: Commands::runScriptBasic, script name = SetSpeedFromDevice, timeOut = -1 ms  
330 1766956882425 XXXX 1766956882425, Thread 330: XXXX 1766956882425, Exiting Thread 330: Commands::runScriptBasic  
330 1766956882425 XXXX 1766956882425, Thread 330: XXXX 1766956882425, Entering Thread 330: Commands::runScriptBasic with script contents. contents[0] = 0xed, ...  
330 1766956882426 XXXX 1766956882426, Thread 330: XXXX 1766956882426, Exiting Thread 330: Commands::runScriptBasic  
330 1766956882426 XXXX 1766956882426, Thread 330: XXXX 1766956882426, Entering Thread 330: Commands::runScriptBasic with script contents. contents[0] = 0xec, ...  
330 1766956882427 XXXX 1766956882427, Thread 330: XXXX 1766956882427, Exiting Thread 330: Commands::runScriptBasic  
330 1766956882427 XXXX 1766956882427, Thread 330: XXXX 1766956882427, Entering Thread 330: Commands::runScriptBasic, script name = EnterTMOD_HV, timeOut = -1 ms  
330 1766956882458 XXXX 1766956882458, Thread 330: XXXX 1766956882458, Exiting Thread 330: Commands::runScriptBasic  
330 1766956882458 XXXX 1766956882458, Thread 330: XXXX 1766956882458, Entering Thread 330: Commands::runScriptBasic, script name = GetDeviceID, timeOut = -1 ms  
330 1766956882459 XXXX 1766956882459, Thread 330: XXXX 1766956882459, Exiting Thread 330: Commands::runScriptBasic  
330 1766956882459 XXXX 1766956882459, Thread 330: XXXX 1766956882459, Entering Thread 330: Commands::runScriptBasic, script name = ExitTMOD, timeOut = -1 ms  
330 1766956882461 XXXX 1766956882461, Thread 330: XXXX 1766956882461, Exiting Thread 330: Commands::runScriptBasic  
330 1766956882461 GEN4_TO_CONTROLLER_LOG:GEN4_CONNECT_INT_LOG_PIC18F27Q43 Post:GetTargetIDInfo
330 1766956882461 GEN4_TO_CONTROLLER_LOG:GEN4_CONNECT_INT_LOG_PIC18F27Q43 Return Value
330 1766956882461 GEN4_TO_CONTROLLER_LOG:GEN4_CONNECT_INT_LOG_PIC18F27Q43 TargetIDInfo: Values:
330 1766956882461 GEN4_TO_CONTROLLER_LOG:GEN4_CONNECT_INT_LOG_PIC18F27Q43 TargetIDInfo: DeviceID = ffffffffa0437480
330 1766956882461 GEN4_TO_CONTROLLER_LOG:GEN4_CONNECT_INT_LOG_PIC18F27Q43 Return End

330 1766956882510 GEN4_TO_CONTROLLER_LOG:GEN4_PROGRAM_INT_LOG_PIC18F27Q43 Pre:SendOperation
330 1766956882510 GEN4_TO_CONTROLLER_LOG:GEN4_PROGRAM_INT_LOG_PIC18F27Q43 Payload
330 1766956882510 GEN4_TO_CONTROLLER_LOG:GEN4_PROGRAM_INT_LOG_PIC18F27Q43 OperationInfo: Values:
330 1766956882510 GEN4_TO_CONTROLLER_LOG:GEN4_PROGRAM_INT_LOG_PIC18F27Q43 OperationInfo: Type = erase, Mask = 00000000, Erase = false, Production Mode = true
330 1766956882510 GEN4_TO_CONTROLLER_LOG:GEN4_PROGRAM_INT_LOG_PIC18F27Q43 TransferInfo: Start = 0, End = 1ffff, Buffer Length = 0, Type = Pgm, Mask = 00000000
330 1766956882510 GEN4_TO_CONTROLLER_LOG:GEN4_PROGRAM_INT_LOG_PIC18F27Q43 TransferInfo: Start = 300000, End = 300011, Buffer Length = 0, Type = Cfg, Mask = 00000000
330 1766956882510 GEN4_TO_CONTROLLER_LOG:GEN4_PROGRAM_INT_LOG_PIC18F27Q43 TransferInfo: Start = 380000, End = 3803ff, Buffer Length = 0, Type = EEData, Mask = 00000000
330 1766956882510 GEN4_TO_CONTROLLER_LOG:GEN4_PROGRAM_INT_LOG_PIC18F27Q43 TransferInfo: Start = 200000, End = 20003f, Buffer Length = 0, Type = UserID, Mask = 00000000
330 1766956882510 GEN4_TO_CONTROLLER_LOG:GEN4_PROGRAM_INT_LOG_PIC18F27Q43 Payload End
330 1766956882511 XXXX 1766956882511, Thread 330: XXXX 1766956882511, Entering Thread 330: Commands::runScriptBasic, script name = SetSpeedFromDevice, timeOut = -1 ms  
330 1766956882512 XXXX 1766956882512, Thread 330: XXXX 1766956882512, Exiting Thread 330: Commands::runScriptBasic  
330 1766956882512 XXXX 1766956882512, Thread 330: XXXX 1766956882512, Entering Thread 330: Commands::runScriptBasic with script contents. contents[0] = 0xed, ...  
330 1766956882513 XXXX 1766956882513, Thread 330: XXXX 1766956882513, Exiting Thread 330: Commands::runScriptBasic  
330 1766956882513 XXXX 1766956882513, Thread 330: XXXX 1766956882513, Entering Thread 330: Commands::runScriptBasic with script contents. contents[0] = 0xec, ...  
330 1766956882514 XXXX 1766956882514, Thread 330: XXXX 1766956882514, Exiting Thread 330: Commands::runScriptBasic  
330 1766956882514 XXXX 1766956882514, Thread 330: XXXX 1766956882514, Entering Thread 330: Commands::runScriptBasic, script name = EnterTMOD_HV, timeOut = -1 ms  
330 1766956882543 XXXX 1766956882543, Thread 330: XXXX 1766956882543, Exiting Thread 330: Commands::runScriptBasic  
330 1766956882543 XXXX 1766956882543, Thread 330: XXXX 1766956882543, Entering Thread 330: Commands::runScriptBasic, script name = SetSpeedFromDevice, timeOut = -1 ms  
330 1766956882545 XXXX 1766956882545, Thread 330: XXXX 1766956882545, Exiting Thread 330: Commands::runScriptBasic  
330 1766956882545 XXXX 1766956882545, Thread 330: XXXX 1766956882545, Entering Thread 330: Commands::runScriptBasic with script contents. contents[0] = 0xed, ...  
330 1766956882546 XXXX 1766956882546, Thread 330: XXXX 1766956882546, Exiting Thread 330: Commands::runScriptBasic  
330 1766956882546 XXXX 1766956882546, Thread 330: XXXX 1766956882546, Entering Thread 330: Commands::runScriptBasic with script contents. contents[0] = 0xec, ...  
330 1766956882547 XXXX 1766956882547, Thread 330: XXXX 1766956882547, Exiting Thread 330: Commands::runScriptBasic  
330 1766956882547 XXXX 1766956882547, Thread 330: XXXX 1766956882547, Entering Thread 330: Commands::runScriptBasic, script name = EnterTMOD_HV, timeOut = -1 ms  
330 1766956882578 XXXX 1766956882578, Thread 330: XXXX 1766956882578, Exiting Thread 330: Commands::runScriptBasic  
330 1766956882578 XXXX 1766956882578, Thread 330: XXXX 1766956882578, Entering Thread 330: Commands::runScriptBasic, script name = EraseChip, timeOut = 30000 ms  
330 1766956882591 XXXX 1766956882591, Thread 330: XXXX 1766956882591, Exiting Thread 330: Commands::runScriptBasic  
330 1766956882591 XXXX 1766956882591, Thread 330: XXXX 1766956882591, Entering Thread 330: Commands::runScriptBasic, script name = ExitTMOD, timeOut = -1 ms  
330 1766956882593 XXXX 1766956882593, Thread 330: XXXX 1766956882593, Exiting Thread 330: Commands::runScriptBasic  
330 1766956882593 XXXX 1766956882593, Thread 330: XXXX 1766956882593, Entering Thread 330: Commands::runScriptBasic, script name = SetSpeedFromDevice, timeOut = -1 ms  
330 1766956882594 XXXX 1766956882594, Thread 330: XXXX 1766956882594, Exiting Thread 330: Commands::runScriptBasic  
330 1766956882594 XXXX 1766956882594, Thread 330: XXXX 1766956882594, Entering Thread 330: Commands::runScriptBasic with script contents. contents[0] = 0xed, ...  
330 1766956882595 XXXX 1766956882595, Thread 330: XXXX 1766956882595, Exiting Thread 330: Commands::runScriptBasic  
330 1766956882595 XXXX 1766956882595, Thread 330: XXXX 1766956882595, Entering Thread 330: Commands::runScriptBasic with script contents. contents[0] = 0xec, ...  
330 1766956882596 XXXX 1766956882596, Thread 330: XXXX 1766956882596, Exiting Thread 330: Commands::runScriptBasic  
330 1766956882596 XXXX 1766956882596, Thread 330: XXXX 1766956882596, Entering Thread 330: Commands::runScriptBasic, script name = EnterTMOD_HV, timeOut = -1 ms  
330 1766956882625 XXXX 1766956882625, Thread 330: XXXX 1766956882625, Exiting Thread 330: Commands::runScriptBasic  
330 1766956882625 XXXX 1766956882625, Thread 330: XXXX 1766956882625, Entering Thread 330: Commands::runScriptBasic, script name = EraseDataEEmem, timeOut = 30000 ms  
330 1766956882637 XXXX 1766956882637, Thread 330: XXXX 1766956882637, Exiting Thread 330: Commands::runScriptBasic  
330 1766956882637 XXXX 1766956882637, Thread 330: XXXX 1766956882637, Entering Thread 330: Commands::runScriptBasic, script name = ExitTMOD, timeOut = -1 ms  
330 1766956882639 XXXX 1766956882639, Thread 330: XXXX 1766956882639, Exiting Thread 330: Commands::runScriptBasic  
330 1766956882639 GEN4_TO_CONTROLLER_LOG:GEN4_PROGRAM_INT_LOG_PIC18F27Q43 Post:SendOperation
330 1766956882639 GEN4_TO_CONTROLLER_LOG:GEN4_PROGRAM_INT_LOG_PIC18F27Q43 Return Value
330 1766956882639 GEN4_TO_CONTROLLER_LOG:GEN4_PROGRAM_INT_LOG_PIC18F27Q43 None
330 1766956882639 GEN4_TO_CONTROLLER_LOG:GEN4_PROGRAM_INT_LOG_PIC18F27Q43 Return End

330 1766956882651 GEN4_TO_CONTROLLER_LOG:GEN4_PROGRAM_INT_LOG_PIC18F27Q43 Pre:SendOperation
330 1766956882651 GEN4_TO_CONTROLLER_LOG:GEN4_PROGRAM_INT_LOG_PIC18F27Q43 Payload
330 1766956882651 GEN4_TO_CONTROLLER_LOG:GEN4_PROGRAM_INT_LOG_PIC18F27Q43 OperationInfo: Values:
330 1766956882651 GEN4_TO_CONTROLLER_LOG:GEN4_PROGRAM_INT_LOG_PIC18F27Q43 OperationInfo: Type = write, Mask = 00000000, Erase = false, Production Mode = true
330 1766956882651 GEN4_TO_CONTROLLER_LOG:GEN4_PROGRAM_INT_LOG_PIC18F27Q43 TransferInfo: Start = 0, End = 17f, Buffer Length = 384, Type = Pgm, Mask = 00000000
330 1766956882651 GEN4_TO_CONTROLLER_LOG:GEN4_PROGRAM_INT_LOG_PIC18F27Q43 TransferInfo: Start = fb00, End = 1dcff, Buffer Length = 57856, Type = Pgm, Mask = 00000000
330 1766956882651 GEN4_TO_CONTROLLER_LOG:GEN4_PROGRAM_INT_LOG_PIC18F27Q43 TransferInfo: Start = 300000, End = 300011, Buffer Length = 18, Type = Cfg, Mask = 00000000
330 1766956882651 GEN4_TO_CONTROLLER_LOG:GEN4_PROGRAM_INT_LOG_PIC18F27Q43 TransferInfo: Start = 200000, End = 20003f, Buffer Length = 64, Type = UserID, Mask = 00000000
330 1766956882651 GEN4_TO_CONTROLLER_LOG:GEN4_PROGRAM_INT_LOG_PIC18F27Q43 Payload End
330 1766956882651 XXXX 1766956882651, Thread 330: XXXX 1766956882651, Entering Thread 330: Commands::runScriptBasic, script name = SetSpeedFromDevice, timeOut = -1 ms  
330 1766956882653 XXXX 1766956882653, Thread 330: XXXX 1766956882653, Exiting Thread 330: Commands::runScriptBasic  
330 1766956882653 XXXX 1766956882653, Thread 330: XXXX 1766956882653, Entering Thread 330: Commands::runScriptBasic with script contents. contents[0] = 0xed, ...  
330 1766956882654 XXXX 1766956882654, Thread 330: XXXX 1766956882654, Exiting Thread 330: Commands::runScriptBasic  
330 1766956882654 XXXX 1766956882654, Thread 330: XXXX 1766956882654, Entering Thread 330: Commands::runScriptBasic with script contents. contents[0] = 0xec, ...  
330 1766956882655 XXXX 1766956882655, Thread 330: XXXX 1766956882655, Exiting Thread 330: Commands::runScriptBasic  
330 1766956882655 XXXX 1766956882655, Thread 330: XXXX 1766956882655, Entering Thread 330: Commands::runScriptBasic, script name = EnterTMOD_HV, timeOut = -1 ms  
330 1766956882686 XXXX 1766956882686, Thread 330: XXXX 1766956882686, Exiting Thread 330: Commands::runScriptBasic  
330 1766956882687 XXXX 1766956882687, Thread 330: XXXX 1766956882687, Entering Thread 330: Commands::runScriptBasic, script name = SetSpeedFromDevice, timeOut = -1 ms  
330 1766956882688 XXXX 1766956882688, Thread 330: XXXX 1766956882688, Exiting Thread 330: Commands::runScriptBasic  
330 1766956882688 XXXX 1766956882688, Thread 330: XXXX 1766956882688, Entering Thread 330: Commands::runScriptBasic with script contents. contents[0] = 0xed, ...  
330 1766956882689 XXXX 1766956882689, Thread 330: XXXX 1766956882689, Exiting Thread 330: Commands::runScriptBasic  
330 1766956882689 XXXX 1766956882689, Thread 330: XXXX 1766956882689, Entering Thread 330: Commands::runScriptBasic with script contents. contents[0] = 0xec, ...  
330 1766956882690 XXXX 1766956882690, Thread 330: XXXX 1766956882690, Exiting Thread 330: Commands::runScriptBasic  
330 1766956882690 XXXX 1766956882690, Thread 330: XXXX 1766956882690, Entering Thread 330: Commands::runScriptBasic, script name = EnterTMOD_HV, timeOut = -1 ms  
330 1766956882719 XXXX 1766956882719, Thread 330: XXXX 1766956882719, Exiting Thread 330: Commands::runScriptBasic  
330 1766956882719 XXXX 1766956882719, Thread 330: XXXX 1766956882719, Entering Thread 330: Commands::runScriptWithDownload, script name = WriteProgmem  
330 1766956882745 XXXX 1766956882745, Thread 330: XXXX 1766956882745, Exiting Thread 330: Commands::runScriptWithDownload(WriteProgmem)  
330 1766956882745 XXXX 1766956882745, Thread 330: XXXX 1766956882745, Entering Thread 330: Commands::runScriptBasic, script name = ExitTMOD, timeOut = -1 ms  
330 1766956882747 XXXX 1766956882747, Thread 330: XXXX 1766956882747, Exiting Thread 330: Commands::runScriptBasic  
330 1766956882747 XXXX 1766956882747, Thread 330: XXXX 1766956882747, Entering Thread 330: Commands::runScriptBasic, script name = SetSpeedFromDevice, timeOut = -1 ms  
330 1766956882749 XXXX 1766956882749, Thread 330: XXXX 1766956882749, Exiting Thread 330: Commands::runScriptBasic  
330 1766956882749 XXXX 1766956882749, Thread 330: XXXX 1766956882749, Entering Thread 330: Commands::runScriptBasic with script contents. contents[0] = 0xed, ...  
330 1766956882750 XXXX 1766956882750, Thread 330: XXXX 1766956882750, Exiting Thread 330: Commands::runScriptBasic  
330 1766956882750 XXXX 1766956882750, Thread 330: XXXX 1766956882750, Entering Thread 330: Commands::runScriptBasic with script contents. contents[0] = 0xec, ...  
330 1766956882751 XXXX 1766956882751, Thread 330: XXXX 1766956882751, Exiting Thread 330: Commands::runScriptBasic  
330 1766956882751 XXXX 1766956882751, Thread 330: XXXX 1766956882751, Entering Thread 330: Commands::runScriptBasic, script name = EnterTMOD_HV, timeOut = -1 ms  
330 1766956882782 XXXX 1766956882782, Thread 330: XXXX 1766956882782, Exiting Thread 330: Commands::runScriptBasic  
330 1766956882783 XXXX 1766956882783, Thread 330: XXXX 1766956882782, Entering Thread 330: Commands::runScriptWithUpload, script name = ReadProgmem  
330 1766956882783 XXXX 1766956882783, Thread 330: XXXX 1766956882783, Entering Thread 330: ToolCommUsb::readTransfer, sideData is 0x3b bytes long, transferDataLength is 0x180 bytes long  
330 1766956882793 XXXX 1766956882793, Thread 330: XXXX 1766956882793, Exiting Thread 330: ToolCommUsb::readTransfer,  cr.status = 0x0  
330 1766956882793 XXXX 1766956882793, Thread 330: XXXX 1766956882793, Exiting Thread 330: Commands::runScriptWithUpload  
330 1766956882793 XXXX 1766956882793, Thread 330: XXXX 1766956882793, Entering Thread 330: Commands::runScriptBasic, script name = ExitTMOD, timeOut = -1 ms  
330 1766956882795 XXXX 1766956882795, Thread 330: XXXX 1766956882795, Exiting Thread 330: Commands::runScriptBasic  
330 1766956882795 XXXX 1766956882795, Thread 330: XXXX 1766956882795, Entering Thread 330: Commands::runScriptBasic, script name = SetSpeedFromDevice, timeOut = -1 ms  
330 1766956882797 XXXX 1766956882797, Thread 330: XXXX 1766956882797, Exiting Thread 330: Commands::runScriptBasic  
330 1766956882797 XXXX 1766956882797, Thread 330: XXXX 1766956882797, Entering Thread 330: Commands::runScriptBasic with script contents. contents[0] = 0xed, ...  
330 1766956882798 XXXX 1766956882798, Thread 330: XXXX 1766956882798, Exiting Thread 330: Commands::runScriptBasic  
330 1766956882798 XXXX 1766956882798, Thread 330: XXXX 1766956882798, Entering Thread 330: Commands::runScriptBasic with script contents. contents[0] = 0xec, ...  
330 1766956882799 XXXX 1766956882799, Thread 330: XXXX 1766956882799, Exiting Thread 330: Commands::runScriptBasic  
330 1766956882799 XXXX 1766956882799, Thread 330: XXXX 1766956882799, Entering Thread 330: Commands::runScriptBasic, script name = EnterTMOD_HV, timeOut = -1 ms  
330 1766956882828 XXXX 1766956882828, Thread 330: XXXX 1766956882828, Exiting Thread 330: Commands::runScriptBasic  
330 1766956882828 XXXX 1766956882828, Thread 330: XXXX 1766956882828, Entering Thread 330: Commands::runScriptWithDownload, script name = WriteProgmem  
330 1766956886093 XXXX 1766956886093, Thread 330: XXXX 1766956886093, Exiting Thread 330: Commands::runScriptWithDownload(WriteProgmem)  
330 1766956886093 XXXX 1766956886093, Thread 330: XXXX 1766956886093, Entering Thread 330: Commands::runScriptBasic, script name = ExitTMOD, timeOut = -1 ms  
330 1766956886095 XXXX 1766956886095, Thread 330: XXXX 1766956886095, Exiting Thread 330: Commands::runScriptBasic  
330 1766956886095 XXXX 1766956886095, Thread 330: XXXX 1766956886095, Entering Thread 330: Commands::runScriptBasic, script name = SetSpeedFromDevice, timeOut = -1 ms  
330 1766956886096 XXXX 1766956886096, Thread 330: XXXX 1766956886096, Exiting Thread 330: Commands::runScriptBasic  
330 1766956886096 XXXX 1766956886096, Thread 330: XXXX 1766956886096, Entering Thread 330: Commands::runScriptBasic with script contents. contents[0] = 0xed, ...  
330 1766956886097 XXXX 1766956886097, Thread 330: XXXX 1766956886097, Exiting Thread 330: Commands::runScriptBasic  
330 1766956886097 XXXX 1766956886097, Thread 330: XXXX 1766956886097, Entering Thread 330: Commands::runScriptBasic with script contents. contents[0] = 0xec, ...  
330 1766956886098 XXXX 1766956886098, Thread 330: XXXX 1766956886098, Exiting Thread 330: Commands::runScriptBasic  
330 1766956886098 XXXX 1766956886098, Thread 330: XXXX 1766956886098, Entering Thread 330: Commands::runScriptBasic, script name = EnterTMOD_HV, timeOut = -1 ms  
330 1766956886129 XXXX 1766956886129, Thread 330: XXXX 1766956886129, Exiting Thread 330: Commands::runScriptBasic  
330 1766956886130 XXXX 1766956886130, Thread 330: XXXX 1766956886130, Entering Thread 330: Commands::runScriptWithUpload, script name = ReadProgmem  
330 1766956886130 XXXX 1766956886130, Thread 330: XXXX 1766956886130, Entering Thread 330: ToolCommUsb::readTransfer, sideData is 0x3b bytes long, transferDataLength is 0xe200 bytes long  
330 1766956887244 XXXX 1766956887244, Thread 330: XXXX 1766956887244, Exiting Thread 330: ToolCommUsb::readTransfer,  cr.status = 0x0  
330 1766956887244 XXXX 1766956887244, Thread 330: XXXX 1766956887244, Exiting Thread 330: Commands::runScriptWithUpload  
330 1766956887244 XXXX 1766956887244, Thread 330: XXXX 1766956887244, Entering Thread 330: Commands::runScriptBasic, script name = ExitTMOD, timeOut = -1 ms  
330 1766956887246 XXXX 1766956887246, Thread 330: XXXX 1766956887246, Exiting Thread 330: Commands::runScriptBasic  
330 1766956887246 XXXX 1766956887246, Thread 330: XXXX 1766956887246, Entering Thread 330: Commands::runScriptBasic, script name = SetSpeedFromDevice, timeOut = -1 ms  
330 1766956887247 XXXX 1766956887247, Thread 330: XXXX 1766956887247, Exiting Thread 330: Commands::runScriptBasic  
330 1766956887247 XXXX 1766956887247, Thread 330: XXXX 1766956887247, Entering Thread 330: Commands::runScriptBasic with script contents. contents[0] = 0xed, ...  
330 1766956887248 XXXX 1766956887248, Thread 330: XXXX 1766956887248, Exiting Thread 330: Commands::runScriptBasic  
330 1766956887248 XXXX 1766956887248, Thread 330: XXXX 1766956887248, Entering Thread 330: Commands::runScriptBasic with script contents. contents[0] = 0xec, ...  
330 1766956887249 XXXX 1766956887249, Thread 330: XXXX 1766956887249, Exiting Thread 330: Commands::runScriptBasic  
330 1766956887249 XXXX 1766956887249, Thread 330: XXXX 1766956887249, Entering Thread 330: Commands::runScriptBasic, script name = EnterTMOD_HV, timeOut = -1 ms  
330 1766956887278 XXXX 1766956887278, Thread 330: XXXX 1766956887278, Exiting Thread 330: Commands::runScriptBasic  
330 1766956887278 XXXX 1766956887278, Thread 330: XXXX 1766956887278, Entering Thread 330: Commands::runScriptWithDownload, script name = WriteIDmem  
330 1766956887284 XXXX 1766956887284, Thread 330: XXXX 1766956887284, Exiting Thread 330: Commands::runScriptWithDownload(WriteIDmem)  
330 1766956887284 XXXX 1766956887284, Thread 330: XXXX 1766956887284, Entering Thread 330: Commands::runScriptBasic, script name = ExitTMOD, timeOut = -1 ms  
330 1766956887286 XXXX 1766956887286, Thread 330: XXXX 1766956887286, Exiting Thread 330: Commands::runScriptBasic  
330 1766956887286 XXXX 1766956887286, Thread 330: XXXX 1766956887286, Entering Thread 330: Commands::runScriptBasic, script name = SetSpeedFromDevice, timeOut = -1 ms  
330 1766956887287 XXXX 1766956887287, Thread 330: XXXX 1766956887287, Exiting Thread 330: Commands::runScriptBasic  
330 1766956887287 XXXX 1766956887287, Thread 330: XXXX 1766956887287, Entering Thread 330: Commands::runScriptBasic with script contents. contents[0] = 0xed, ...  
330 1766956887288 XXXX 1766956887288, Thread 330: XXXX 1766956887288, Exiting Thread 330: Commands::runScriptBasic  
330 1766956887288 XXXX 1766956887288, Thread 330: XXXX 1766956887288, Entering Thread 330: Commands::runScriptBasic with script contents. contents[0] = 0xec, ...  
330 1766956887289 XXXX 1766956887289, Thread 330: XXXX 1766956887289, Exiting Thread 330: Commands::runScriptBasic  
330 1766956887289 XXXX 1766956887289, Thread 330: XXXX 1766956887289, Entering Thread 330: Commands::runScriptBasic, script name = EnterTMOD_HV, timeOut = -1 ms  
330 1766956887321 XXXX 1766956887321, Thread 330: XXXX 1766956887321, Exiting Thread 330: Commands::runScriptBasic  
330 1766956887321 XXXX 1766956887321, Thread 330: XXXX 1766956887321, Entering Thread 330: Commands::runScriptWithUpload, script name = ReadIDmem  
330 1766956887321 XXXX 1766956887321, Thread 330: XXXX 1766956887321, Entering Thread 330: ToolCommUsb::readTransfer, sideData is 0x3b bytes long, transferDataLength is 0x40 bytes long  
330 1766956887323 XXXX 1766956887323, Thread 330: XXXX 1766956887323, Exiting Thread 330: ToolCommUsb::readTransfer,  cr.status = 0x0  
330 1766956887323 XXXX 1766956887323, Thread 330: XXXX 1766956887323, Exiting Thread 330: Commands::runScriptWithUpload  
330 1766956887323 XXXX 1766956887323, Thread 330: XXXX 1766956887323, Entering Thread 330: Commands::runScriptBasic, script name = ExitTMOD, timeOut = -1 ms  
330 1766956887325 XXXX 1766956887325, Thread 330: XXXX 1766956887325, Exiting Thread 330: Commands::runScriptBasic  
330 1766956887325 XXXX 1766956887325, Thread 330: XXXX 1766956887325, Entering Thread 330: Commands::runScriptBasic, script name = SetSpeedFromDevice, timeOut = -1 ms  
330 1766956887326 XXXX 1766956887326, Thread 330: XXXX 1766956887326, Exiting Thread 330: Commands::runScriptBasic  
330 1766956887326 XXXX 1766956887326, Thread 330: XXXX 1766956887326, Entering Thread 330: Commands::runScriptBasic with script contents. contents[0] = 0xed, ...  
330 1766956887327 XXXX 1766956887327, Thread 330: XXXX 1766956887327, Exiting Thread 330: Commands::runScriptBasic  
330 1766956887327 XXXX 1766956887327, Thread 330: XXXX 1766956887327, Entering Thread 330: Commands::runScriptBasic with script contents. contents[0] = 0xec, ...  
330 1766956887328 XXXX 1766956887328, Thread 330: XXXX 1766956887328, Exiting Thread 330: Commands::runScriptBasic  
330 1766956887328 XXXX 1766956887328, Thread 330: XXXX 1766956887328, Entering Thread 330: Commands::runScriptBasic, script name = EnterTMOD_HV, timeOut = -1 ms  
330 1766956887357 XXXX 1766956887357, Thread 330: XXXX 1766956887357, Exiting Thread 330: Commands::runScriptBasic  
330 1766956887357 XXXX 1766956887357, Thread 330: XXXX 1766956887357, Entering Thread 330: Commands::runScriptWithDownload, script name = WriteConfigmem  
330 1766956887558 XXXX 1766956887558, Thread 330: XXXX 1766956887558, Exiting Thread 330: Commands::runScriptWithDownload(WriteConfigmem)  
330 1766956887558 XXXX 1766956887558, Thread 330: XXXX 1766956887558, Entering Thread 330: Commands::runScriptBasic, script name = ExitTMOD, timeOut = -1 ms  
330 1766956887560 XXXX 1766956887560, Thread 330: XXXX 1766956887560, Exiting Thread 330: Commands::runScriptBasic  
330 1766956887560 XXXX 1766956887560, Thread 330: XXXX 1766956887560, Entering Thread 330: Commands::runScriptBasic, script name = SetSpeedFromDevice, timeOut = -1 ms  
330 1766956887561 XXXX 1766956887561, Thread 330: XXXX 1766956887561, Exiting Thread 330: Commands::runScriptBasic  
330 1766956887561 XXXX 1766956887561, Thread 330: XXXX 1766956887561, Entering Thread 330: Commands::runScriptBasic with script contents. contents[0] = 0xed, ...  
330 1766956887562 XXXX 1766956887562, Thread 330: XXXX 1766956887562, Exiting Thread 330: Commands::runScriptBasic  
330 1766956887562 XXXX 1766956887562, Thread 330: XXXX 1766956887562, Entering Thread 330: Commands::runScriptBasic with script contents. contents[0] = 0xec, ...  
330 1766956887563 XXXX 1766956887563, Thread 330: XXXX 1766956887563, Exiting Thread 330: Commands::runScriptBasic  
330 1766956887563 XXXX 1766956887563, Thread 330: XXXX 1766956887563, Entering Thread 330: Commands::runScriptBasic, script name = EnterTMOD_HV, timeOut = -1 ms  
330 1766956887595 XXXX 1766956887595, Thread 330: XXXX 1766956887595, Exiting Thread 330: Commands::runScriptBasic  
330 1766956887595 XXXX 1766956887595, Thread 330: XXXX 1766956887595, Entering Thread 330: Commands::runScriptWithUpload, script name = ReadConfigmem  
330 1766956887595 XXXX 1766956887595, Thread 330: XXXX 1766956887595, Entering Thread 330: ToolCommUsb::readTransfer, sideData is 0x37 bytes long, transferDataLength is 0x12 bytes long  
330 1766956887597 XXXX 1766956887597, Thread 330: XXXX 1766956887597, Exiting Thread 330: ToolCommUsb::readTransfer,  cr.status = 0x0  
330 1766956887597 XXXX 1766956887597, Thread 330: XXXX 1766956887597, Exiting Thread 330: Commands::runScriptWithUpload  
330 1766956887597 XXXX 1766956887597, Thread 330: XXXX 1766956887597, Entering Thread 330: Commands::runScriptBasic, script name = ExitTMOD, timeOut = -1 ms  
330 1766956887599 XXXX 1766956887599, Thread 330: XXXX 1766956887599, Exiting Thread 330: Commands::runScriptBasic  
330 1766956887599 GEN4_TO_CONTROLLER_LOG:GEN4_PROGRAM_INT_LOG_PIC18F27Q43 Post:SendOperation
330 1766956887599 GEN4_TO_CONTROLLER_LOG:GEN4_PROGRAM_INT_LOG_PIC18F27Q43 Return Value
330 1766956887599 GEN4_TO_CONTROLLER_LOG:GEN4_PROGRAM_INT_LOG_PIC18F27Q43 None
330 1766956887599 GEN4_TO_CONTROLLER_LOG:GEN4_PROGRAM_INT_LOG_PIC18F27Q43 Return End

330 1766956887599 GEN4_TO_CONTROLLER_LOG:GEN4_PROGRAM_INT_LOG_PIC18F27Q43 Pre:endOfOperations
330 1766956887599 GEN4_TO_CONTROLLER_LOG:GEN4_PROGRAM_INT_LOG_PIC18F27Q43 Payload
330 1766956887599 GEN4_TO_CONTROLLER_LOG:GEN4_PROGRAM_INT_LOG_PIC18F27Q43 null
330 1766956887599 GEN4_TO_CONTROLLER_LOG:GEN4_PROGRAM_INT_LOG_PIC18F27Q43 Payload End
330 1766956887600 XXXX 1766956887599, Thread 330: XXXX 1766956887599, Entering Thread 330: Commands::runScriptBasic, script name = ExitTMOD, timeOut = -1 ms  
330 1766956887601 XXXX 1766956887601, Thread 330: XXXX 1766956887601, Exiting Thread 330: Commands::runScriptBasic  
330 1766956887601 GEN4_TO_CONTROLLER_LOG:GEN4_PROGRAM_INT_LOG_PIC18F27Q43 Post:endOfOperations
330 1766956887601 GEN4_TO_CONTROLLER_LOG:GEN4_PROGRAM_INT_LOG_PIC18F27Q43 Return Value
330 1766956887601 GEN4_TO_CONTROLLER_LOG:GEN4_PROGRAM_INT_LOG_PIC18F27Q43 None
330 1766956887601 GEN4_TO_CONTROLLER_LOG:GEN4_PROGRAM_INT_LOG_PIC18F27Q43 Return End

330 1766956887607 GEN4_TO_CONTROLLER_LOG:GEN4_PROGRAM_INT_LOG_PIC18F27Q43 Pre:SendOperation
330 1766956887607 GEN4_TO_CONTROLLER_LOG:GEN4_PROGRAM_INT_LOG_PIC18F27Q43 Payload
330 1766956887607 GEN4_TO_CONTROLLER_LOG:GEN4_PROGRAM_INT_LOG_PIC18F27Q43 OperationInfo: Values:
330 1766956887607 GEN4_TO_CONTROLLER_LOG:GEN4_PROGRAM_INT_LOG_PIC18F27Q43 OperationInfo: Type = releasefromreset, Mask = 00000000, Erase = false, Production Mode = true
330 1766956887607 GEN4_TO_CONTROLLER_LOG:GEN4_PROGRAM_INT_LOG_PIC18F27Q43 Payload End
330 1766956887607 XXXX 1766956887607, Thread 330: XXXX 1766956887607, Entering Thread 330: Commands::runScriptBasic, script name = ExitTMOD, timeOut = -1 ms  
330 1766956887609 XXXX 1766956887609, Thread 330: XXXX 1766956887609, Exiting Thread 330: Commands::runScriptBasic  
330 1766956887609 XXXX 1766956887609, Thread 330: XXXX 1766956887609, Entering Thread 330: Commands::runScriptBasic with script contents. contents[0] = 0x42, ...  
330 1766956887610 XXXX 1766956887610, Thread 330: XXXX 1766956887610, Exiting Thread 330: Commands::runScriptBasic  
330 1766956887610 XXXX 1766956887610, Thread 330: XXXX 1766956887610, Entering Thread 330: Commands::runScriptBasic with script contents. contents[0] = 0xef, ...  
330 1766956887621 XXXX 1766956887621, Thread 330: XXXX 1766956887621, Exiting Thread 330: Commands::runScriptBasic  
330 1766956887621 GEN4_TO_CONTROLLER_LOG:GEN4_PROGRAM_INT_LOG_PIC18F27Q43 Post:SendOperation
330 1766956887621 GEN4_TO_CONTROLLER_LOG:GEN4_PROGRAM_INT_LOG_PIC18F27Q43 Return Value
330 1766956887621 GEN4_TO_CONTROLLER_LOG:GEN4_PROGRAM_INT_LOG_PIC18F27Q43 None
330 1766956887621 GEN4_TO_CONTROLLER_LOG:GEN4_PROGRAM_INT_LOG_PIC18F27Q43 Return End
330 1766956887623 GEN4_CONNECT_DIAGNOSTICS:MPLABCommTool is null

330 1766956887623 GEN4_TO_CONTROLLER_LOG:GEN4_CONNECT_INT_LOG_PIC18F27Q43 Pre:GetFirmwareInfo
330 1766956887623 GEN4_TO_CONTROLLER_LOG:GEN4_CONNECT_INT_LOG_PIC18F27Q43 Payload
330 1766956887623 GEN4_TO_CONTROLLER_LOG:GEN4_CONNECT_INT_LOG_PIC18F27Q43 null
330 1766956887623 GEN4_TO_CONTROLLER_LOG:GEN4_CONNECT_INT_LOG_PIC18F27Q43 Payload End
330 1766956887631 GEN4_TO_CONTROLLER_LOG:GEN4_CONNECT_INT_LOG_PIC18F27Q43 Post:GetFirmwareInfo
330 1766956887631 GEN4_TO_CONTROLLER_LOG:GEN4_CONNECT_INT_LOG_PIC18F27Q43 Return Value
330 1766956887631 GEN4_TO_CONTROLLER_LOG:GEN4_CONNECT_INT_LOG_PIC18F27Q43 FirmwareInfo: Values:
330 1766956887631 GEN4_TO_CONTROLLER_LOG:GEN4_CONNECT_INT_LOG_PIC18F27Q43 FirmwareInfo: boot = false, bootVer = 00.00.68, apVer = 02.05.47, fpgaVer = ff.ff.ff, scriptVer = 00.10.08, macAddress = 0504883548174844851484953485250, devID = a1020e01, devID1 = 2, devSN0 = ffffffff, devSN1 = ffffffff, serialNumber = 020026702RYN005992, appCommitID = null, scriptCommitID = f91823efd7, PCB_ID = 2
330 1766956887631 GEN4_TO_CONTROLLER_LOG:GEN4_CONNECT_INT_LOG_PIC18F27Q43 Return End

330 1766956887631 GEN4_TO_CONTROLLER_LOG:GEN4_CONNECT_INT_LOG_PIC18F27Q43 Pre:SetPowerInfo
330 1766956887631 GEN4_TO_CONTROLLER_LOG:GEN4_CONNECT_INT_LOG_PIC18F27Q43 Payload
330 1766956887631 GEN4_TO_CONTROLLER_LOG:GEN4_CONNECT_INT_LOG_PIC18F27Q43 PowerInfo: Values:
330 1766956887631 GEN4_TO_CONTROLLER_LOG:GEN4_CONNECT_INT_LOG_PIC18F27Q43 PowerInfo: shotDownSystem = true, isToolPower = false, voltage = 0.000000, useVppFirst = false, useLowVoltageProgramming = false, useMaintainActivePower = false
330 1766956887631 GEN4_TO_CONTROLLER_LOG:GEN4_CONNECT_INT_LOG_PIC18F27Q43 Payload End
330 1766956887632 XXXX 1766956887632, Thread 330: XXXX 1766956887632, Entering Thread 330: Commands::runScriptBasic with script contents. contents[0] = 0x39, ...  
330 1766956887632 XXXX 1766956887632, Thread 330: XXXX 1766956887632, Exiting Thread 330: Commands::runScriptBasic  
330 1766956887632 XXXX 1766956887632, Thread 330: XXXX 1766956887632, Entering Thread 330: Commands::runScriptBasic with script contents. contents[0] = 0x44, ...  
330 1766956887645 XXXX 1766956887645, Thread 330: XXXX 1766956887645, Exiting Thread 330: Commands::runScriptBasic  
330 1766956887645 GEN4_TO_CONTROLLER_LOG:GEN4_CONNECT_INT_LOG_PIC18F27Q43 Post:SetPowerInfo
330 1766956887645 GEN4_TO_CONTROLLER_LOG:GEN4_CONNECT_INT_LOG_PIC18F27Q43 Return Value
330 1766956887645 GEN4_TO_CONTROLLER_LOG:GEN4_CONNECT_INT_LOG_PIC18F27Q43 none
330 1766956887645 GEN4_TO_CONTROLLER_LOG:GEN4_CONNECT_INT_LOG_PIC18F27Q43 Return End
330 1766956887645 GEN4_CONNECT_DIAGNOSTICS:Removing plug and play observer com.microchip.mplab.mdbcore.RI4Tool.RI4ToolBase$RI4PlugNPlayObserver@5a1d6d03
330 1766956887645 GEN4_CONNECT_DIAGNOSTICS:Begin PlugNPlayObservers list dump:
330 1766956887645 GEN4_CONNECT_DIAGNOSTICS:End PlugNPlayObservers list dump:
330 1766956887696 GEN4_CONNECT_DIAGNOSTICS:Calling RIDbgToolCom.Disconnect
330 1766956887696 GEN4_CONNECT_DIAGNOSTICS:Calling MPLABCommTool.Detach to remove tool from plug and play list
330 1766956887697 GEN4_CONNECT_DIAGNOSTICS:Calling RIDbgToolCom.DisconnectFromMPlabComm
330 1766956887697 GEN4_CONNECT_DIAGNOSTICS:Calling MPLABCommTool.Disconnect
354 1766956978459 GEN4_CONNECT_DIAGNOSTICS:MPLABCommTool is NOT null
354 1766956978459 GEN4_CONNECT_DIAGNOSTICS:AttachedToolPID = 9036, AttachedToolVID = 4d8
354 1766956978459 GEN4_CONNECT_DIAGNOSTICS:transport type = USB
354 1766956978459 GEN4_CONNECT_DIAGNOSTICS:AttachedToolPID = 9036, AttachedToolVID = 4d8
354 1766956978464 com.microchip.mplab.mdbcore.RealICETool.RIDbgToolCom
354 1766956978464 GEN4_CONNECT_DIAGNOSTICS:Before MPLABCommTool.Connect()
354 1766956978464 GEN4_CONNECT_DIAGNOSTICS:After MPLABCommTool.Connect()
354 1766956978464 GEN4_CONNECT_DIAGNOSTICS:MPLABCommTool.Connect() returned MPLABCOMM_NO_ERROR
354 1766956978464 GEN4_CONNECT_DIAGNOSTICS:Attaching to MPLABCommTool plugnplay
354 1766956978465 GEN4_CONNECT_DIAGNOSTICS:Adding new plug and play observer com.microchip.mplab.mdbcore.RI4Tool.RI4ToolBase$RI4PlugNPlayObserver@4134ee1
354 1766956978465 GEN4_CONNECT_DIAGNOSTICS:Begin PlugNPlayObservers list dump:
354 1766956978465 GEN4_CONNECT_DIAGNOSTICS:com.microchip.mplab.mdbcore.RI4Tool.RI4ToolBase$RI4PlugNPlayObserver@4134ee1
354 1766956978465 GEN4_CONNECT_DIAGNOSTICS:End PlugNPlayObservers list dump:
354 1766956978465 GEN4_CONNECT_DIAGNOSTICS:Registering for alternate PNP notifications. CommPnPCriteria.cPIDList = [9035], CommPnPCriteria.cSerialNumber = 020026702ryn005992

354 1766956978641 GEN4_TO_CONTROLLER_LOG:GEN4_INIT_INT_LOG_PIC18F27Q43 Pre:init
354 1766956978641 GEN4_TO_CONTROLLER_LOG:GEN4_INIT_INT_LOG_PIC18F27Q43 Payload
354 1766956978641 GEN4_TO_CONTROLLER_LOG:GEN4_INIT_INT_LOG_PIC18F27Q43 DeviceInfo: Values:
354 1766956978642 GEN4_TO_CONTROLLER_LOG:GEN4_INIT_INT_LOG_PIC18F27Q43 DeviceInfo: pcAddress = 000004f9, Vpp = 9.00, useRowEraseIfVoltageIsLow = true, voltageBelowWhichUseRowErase = 2.10, deviceName = PIC18F27Q43, programmerType = PIC18ENH_V2
354 1766956978642 GEN4_TO_CONTROLLER_LOG:GEN4_INIT_INT_LOG_PIC18F27Q43 DeviceInfo: MemInfo values:
354 1766956978642 GEN4_TO_CONTROLLER_LOG:GEN4_INIT_INT_LOG_PIC18F27Q43 DeviceInfo: mask = ffff, exists = true, startAddr = 00000000, endAddr = 0001ffff, rowSize = 0080, rowEraseSize = 0080, addrInc = 0002, widthProgram = 0002
354 1766956978642 GEN4_TO_CONTROLLER_LOG:GEN4_INIT_INT_LOG_PIC18F27Q43 DeviceInfo: mask = 00ff, exists = true, startAddr = 00300000, endAddr = 00300011, rowSize = 0001, rowEraseSize = 0000, addrInc = 0001, widthProgram = 0001
354 1766956978642 GEN4_TO_CONTROLLER_LOG:GEN4_INIT_INT_LOG_PIC18F27Q43 DeviceInfo: mask = 0000, exists = false, startAddr = 00000000, endAddr = 00000000, rowSize = 0000, rowEraseSize = 0080, addrInc = 0000, widthProgram = 0000
354 1766956978642 GEN4_TO_CONTROLLER_LOG:GEN4_INIT_INT_LOG_PIC18F27Q43 DeviceInfo: mask = 00ff, exists = true, startAddr = 00380000, endAddr = 003803ff, rowSize = 0001, rowEraseSize = 0000, addrInc = 0001, widthProgram = 0001
354 1766956978642 GEN4_TO_CONTROLLER_LOG:GEN4_INIT_INT_LOG_PIC18F27Q43 DeviceInfo: mask = ffff, exists = true, startAddr = 00200000, endAddr = 0020003f, rowSize = 0001, rowEraseSize = 0000, addrInc = 0002, widthProgram = 0002
354 1766956978642 GEN4_TO_CONTROLLER_LOG:GEN4_INIT_INT_LOG_PIC18F27Q43 DeviceInfo: mask = ffff, exists = true, startAddr = 00200000, endAddr = 002403ff, rowSize = 0080, rowEraseSize = 0080, addrInc = 0002, widthProgram = 0002
354 1766956978642 GEN4_TO_CONTROLLER_LOG:GEN4_INIT_INT_LOG_PIC18F27Q43 DeviceInfo: mask = 0000, exists = false, startAddr = 00000000, endAddr = 00000000, rowSize = 0000, rowEraseSize = 0000, addrInc = 0001, widthProgram = 0001
354 1766956978642 GEN4_TO_CONTROLLER_LOG:GEN4_INIT_INT_LOG_PIC18F27Q43 DeviceInfo: mask = 0000, exists = false, startAddr = 00000000, endAddr = 00000000, rowSize = 0000, rowEraseSize = 0000, addrInc = 0000, widthProgram = 0000
354 1766956978642 GEN4_TO_CONTROLLER_LOG:GEN4_INIT_INT_LOG_PIC18F27Q43 DeviceInfo: mask = 0000, exists = false, startAddr = 00000000, endAddr = 00000000, rowSize = 0000, rowEraseSize = 0000, addrInc = 0000, widthProgram = 0000
354 1766956978642 GEN4_TO_CONTROLLER_LOG:GEN4_INIT_INT_LOG_PIC18F27Q43 DeviceInfo: mask = 0000, exists = false, startAddr = 00000000, endAddr = 00000000, rowSize = 0000, rowEraseSize = 0000, addrInc = 0000, widthProgram = 0000
354 1766956978642 GEN4_TO_CONTROLLER_LOG:GEN4_INIT_INT_LOG_PIC18F27Q43 DeviceInfo: mask = 0000, exists = false, startAddr = 00000000, endAddr = 00000000, rowSize = 0000, rowEraseSize = 0000, addrInc = 0001, widthProgram = 0001
354 1766956978642 GEN4_TO_CONTROLLER_LOG:GEN4_INIT_INT_LOG_PIC18F27Q43 DeviceInfo: mask = 0000, exists = false, startAddr = 00000000, endAddr = 00000000, rowSize = 0000, rowEraseSize = 0000, addrInc = 0001, widthProgram = 0001
354 1766956978642 GEN4_TO_CONTROLLER_LOG:GEN4_INIT_INT_LOG_PIC18F27Q43 DeviceInfo: mask = 0000, exists = false, startAddr = 00000000, endAddr = 00000000, rowSize = 0000, rowEraseSize = 0000, addrInc = 0000, widthProgram = 0000
354 1766956978642 GEN4_TO_CONTROLLER_LOG:GEN4_INIT_INT_LOG_PIC18F27Q43 DeviceInfo: mask = 0000, exists = false, startAddr = 00000000, endAddr = 00000000, rowSize = 0000, rowEraseSize = 0000, addrInc = 0000, widthProgram = 0000
354 1766956978642 GEN4_TO_CONTROLLER_LOG:GEN4_INIT_INT_LOG_PIC18F27Q43 DeviceInfo: mask = 0000, exists = false, startAddr = 00000000, endAddr = 00000000, rowSize = 0000, rowEraseSize = 0000, addrInc = 0000, widthProgram = 0000
354 1766956978642 GEN4_TO_CONTROLLER_LOG:GEN4_INIT_INT_LOG_PIC18F27Q43 DeviceInfo: mask = 0000, exists = false, startAddr = 00000000, endAddr = 00000000, rowSize = 0000, rowEraseSize = 0000, addrInc = 0000, widthProgram = 0000
354 1766956978642 GEN4_TO_CONTROLLER_LOG:GEN4_INIT_INT_LOG_PIC18F27Q43 DeviceInfo: mask = 7fffffff, exists = true, startAddr = 003ffffe, endAddr = 003fffff, rowSize = 0001, rowEraseSize = 0000, addrInc = 0001, widthProgram = 0001
354 1766956978642 GEN4_TO_CONTROLLER_LOG:GEN4_INIT_INT_LOG_PIC18F27Q43 DeviceInfo: mask = 0000, exists = false, startAddr = 00000000, endAddr = 00000000, rowSize = 0000, rowEraseSize = 0000, addrInc = 0000, widthProgram = 0000
354 1766956978642 GEN4_TO_CONTROLLER_LOG:GEN4_INIT_INT_LOG_PIC18F27Q43 DeviceInfo: mask = ffff, exists = true, startAddr = 003c0000, endAddr = 003c00ff, rowSize = 0080, rowEraseSize = 0000, addrInc = 0002, widthProgram = 0002
354 1766956978642 GEN4_TO_CONTROLLER_LOG:GEN4_INIT_INT_LOG_PIC18F27Q43 DeviceInfo: mask = ffff, exists = true, startAddr = 002c0000, endAddr = 002c00ff, rowSize = 0080, rowEraseSize = 0000, addrInc = 0002, widthProgram = 0002
354 1766956978642 GEN4_TO_CONTROLLER_LOG:GEN4_INIT_INT_LOG_PIC18F27Q43 DeviceInfo: mask = 0000, exists = false, startAddr = 00000000, endAddr = 00000000, rowSize = 0000, rowEraseSize = 0000, addrInc = 0000, widthProgram = 0000
354 1766956978642 GEN4_TO_CONTROLLER_LOG:GEN4_INIT_INT_LOG_PIC18F27Q43 DeviceInfo: mask = 0000, exists = false, startAddr = 00000000, endAddr = 00000000, rowSize = 0000, rowEraseSize = 0000, addrInc = 0000, widthProgram = 0000
354 1766956978642 GEN4_TO_CONTROLLER_LOG:GEN4_INIT_INT_LOG_PIC18F27Q43 DeviceInfo: mask = 0000, exists = false, startAddr = 00000000, endAddr = 00000000, rowSize = 0000, rowEraseSize = 0000, addrInc = 0000, widthProgram = 0000
354 1766956978642 GEN4_TO_CONTROLLER_LOG:GEN4_INIT_INT_LOG_PIC18F27Q43 DeviceInfo: CfgRequiredBitsMask Values:
354 1766956978642 GEN4_TO_CONTROLLER_LOG:GEN4_INIT_INT_LOG_PIC18F27Q43 Address = 00300000, Mask = 00000077
354 1766956978642 GEN4_TO_CONTROLLER_LOG:GEN4_INIT_INT_LOG_PIC18F27Q43 Address = 00300001, Mask = 0000002b
354 1766956978642 GEN4_TO_CONTROLLER_LOG:GEN4_INIT_INT_LOG_PIC18F27Q43 Address = 00300002, Mask = 000000ff
354 1766956978642 GEN4_TO_CONTROLLER_LOG:GEN4_INIT_INT_LOG_PIC18F27Q43 Address = 00300003, Mask = 000000bf
354 1766956978642 GEN4_TO_CONTROLLER_LOG:GEN4_INIT_INT_LOG_PIC18F27Q43 Address = 00300004, Mask = 0000007f
354 1766956978642 GEN4_TO_CONTROLLER_LOG:GEN4_INIT_INT_LOG_PIC18F27Q43 Address = 00300005, Mask = 0000003f
354 1766956978642 GEN4_TO_CONTROLLER_LOG:GEN4_INIT_INT_LOG_PIC18F27Q43 Address = 00300006, Mask = 0000001f
354 1766956978642 GEN4_TO_CONTROLLER_LOG:GEN4_INIT_INT_LOG_PIC18F27Q43 Address = 00300007, Mask = 0000008f
354 1766956978642 GEN4_TO_CONTROLLER_LOG:GEN4_INIT_INT_LOG_PIC18F27Q43 Address = 00300009, Mask = 00000001
354 1766956978642 GEN4_TO_CONTROLLER_LOG:GEN4_INIT_INT_LOG_PIC18F27Q43 BasicInfo: Values:
354 1766956978642 GEN4_TO_CONTROLLER_LOG:GEN4_INIT_INT_LOG_PIC18F27Q43 BasicInfo: InputStream = com.microchip.mplab.libs.toolpacksupport.EquatableFileInputStream@71694141, ToolFlavor = PIC32C
354 1766956978642 GEN4_TO_CONTROLLER_LOG:GEN4_INIT_INT_LOG_PIC18F27Q43 Payload End
354 1766956978644 GEN4_TO_CONTROLLER_LOG:GEN4_INIT_INT_LOG_PIC18F27Q43 Post:init
354 1766956978644 GEN4_TO_CONTROLLER_LOG:GEN4_INIT_INT_LOG_PIC18F27Q43 Return Value
354 1766956978644 GEN4_TO_CONTROLLER_LOG:GEN4_INIT_INT_LOG_PIC18F27Q43 none
354 1766956978644 GEN4_TO_CONTROLLER_LOG:GEN4_INIT_INT_LOG_PIC18F27Q43 Return End

354 1766956978644 GEN4_TO_CONTROLLER_LOG:GEN4_INIT_INT_LOG_PIC18F27Q43 Pre:GetInterfaceProvider
354 1766956978644 GEN4_TO_CONTROLLER_LOG:GEN4_INIT_INT_LOG_PIC18F27Q43 Payload
354 1766956978644 GEN4_TO_CONTROLLER_LOG:GEN4_INIT_INT_LOG_PIC18F27Q43 RI4DebugInterface
354 1766956978644 GEN4_TO_CONTROLLER_LOG:GEN4_INIT_INT_LOG_PIC18F27Q43 Payload End
354 1766956978644 GEN4_TO_CONTROLLER_LOG:GEN4_INIT_INT_LOG_PIC18F27Q43 Post:GetInterfaceProvider
354 1766956978644 GEN4_TO_CONTROLLER_LOG:GEN4_INIT_INT_LOG_PIC18F27Q43 Return Value
354 1766956978644 GEN4_TO_CONTROLLER_LOG:GEN4_INIT_INT_LOG_PIC18F27Q43 com.microchip.mplab.libs.RI4ToolsController.implementations.RI4DebugInterfaceImpl@62b498d1
354 1766956978644 GEN4_TO_CONTROLLER_LOG:GEN4_INIT_INT_LOG_PIC18F27Q43 Return End

354 1766956978645 GEN4_TO_CONTROLLER_LOG:GEN4_INIT_INT_LOG_PIC18F27Q43 Pre:GetInterfaceProvider
354 1766956978645 GEN4_TO_CONTROLLER_LOG:GEN4_INIT_INT_LOG_PIC18F27Q43 Payload
354 1766956978645 GEN4_TO_CONTROLLER_LOG:GEN4_INIT_INT_LOG_PIC18F27Q43 RI4ProgramInterface
354 1766956978645 GEN4_TO_CONTROLLER_LOG:GEN4_INIT_INT_LOG_PIC18F27Q43 Payload End
354 1766956978645 GEN4_TO_CONTROLLER_LOG:GEN4_INIT_INT_LOG_PIC18F27Q43 Post:GetInterfaceProvider
354 1766956978645 GEN4_TO_CONTROLLER_LOG:GEN4_INIT_INT_LOG_PIC18F27Q43 Return Value
354 1766956978645 GEN4_TO_CONTROLLER_LOG:GEN4_INIT_INT_LOG_PIC18F27Q43 com.microchip.mplab.libs.RI4ToolsController.implementations.RI4ProgramInterfaceImpl@4d92f7c9
354 1766956978645 GEN4_TO_CONTROLLER_LOG:GEN4_INIT_INT_LOG_PIC18F27Q43 Return End

354 1766956978646 GEN4_TO_CONTROLLER_LOG:GEN4_INIT_INT_LOG_PIC18F27Q43 Pre:GetInterfaceProvider
354 1766956978646 GEN4_TO_CONTROLLER_LOG:GEN4_INIT_INT_LOG_PIC18F27Q43 Payload
354 1766956978646 GEN4_TO_CONTROLLER_LOG:GEN4_INIT_INT_LOG_PIC18F27Q43 RI4ConnectInterface
354 1766956978646 GEN4_TO_CONTROLLER_LOG:GEN4_INIT_INT_LOG_PIC18F27Q43 Payload End
354 1766956978646 GEN4_TO_CONTROLLER_LOG:GEN4_INIT_INT_LOG_PIC18F27Q43 Post:GetInterfaceProvider
354 1766956978646 GEN4_TO_CONTROLLER_LOG:GEN4_INIT_INT_LOG_PIC18F27Q43 Return Value
354 1766956978646 GEN4_TO_CONTROLLER_LOG:GEN4_INIT_INT_LOG_PIC18F27Q43 com.microchip.mplab.libs.PK4ToolsController.PK4ConnectInterfaceImpl@5368ccdc
354 1766956978646 GEN4_TO_CONTROLLER_LOG:GEN4_INIT_INT_LOG_PIC18F27Q43 Return End

354 1766956978646 GEN4_TO_CONTROLLER_LOG:GEN4_INIT_INT_LOG_PIC18F27Q43 Pre:GetInterfaceProvider
354 1766956978646 GEN4_TO_CONTROLLER_LOG:GEN4_INIT_INT_LOG_PIC18F27Q43 Payload
354 1766956978646 GEN4_TO_CONTROLLER_LOG:GEN4_INIT_INT_LOG_PIC18F27Q43 RI4ControllerDiagnosticsInterface
354 1766956978646 GEN4_TO_CONTROLLER_LOG:GEN4_INIT_INT_LOG_PIC18F27Q43 Payload End
354 1766956978646 GEN4_TO_CONTROLLER_LOG:GEN4_INIT_INT_LOG_PIC18F27Q43 Post:GetInterfaceProvider
354 1766956978646 GEN4_TO_CONTROLLER_LOG:GEN4_INIT_INT_LOG_PIC18F27Q43 Return Value
354 1766956978646 GEN4_TO_CONTROLLER_LOG:GEN4_INIT_INT_LOG_PIC18F27Q43 com.microchip.mplab.libs.RI4ToolsController.implementations.RI4ControllerDiagnosticsInterfaceImpl@1900fbb4
354 1766956978646 GEN4_TO_CONTROLLER_LOG:GEN4_INIT_INT_LOG_PIC18F27Q43 Return End

354 1766956978646 GEN4_TO_CONTROLLER_LOG:GEN4_INIT_INT_LOG_PIC18F27Q43 Pre:GetInterfaceProvider
354 1766956978646 GEN4_TO_CONTROLLER_LOG:GEN4_INIT_INT_LOG_PIC18F27Q43 Payload
354 1766956978646 GEN4_TO_CONTROLLER_LOG:GEN4_INIT_INT_LOG_PIC18F27Q43 ProgrammerToGo
354 1766956978646 GEN4_TO_CONTROLLER_LOG:GEN4_INIT_INT_LOG_PIC18F27Q43 Payload End
354 1766956978646 GEN4_TO_CONTROLLER_LOG:GEN4_INIT_INT_LOG_PIC18F27Q43 Post:GetInterfaceProvider
354 1766956978646 GEN4_TO_CONTROLLER_LOG:GEN4_INIT_INT_LOG_PIC18F27Q43 Return Value
354 1766956978646 GEN4_TO_CONTROLLER_LOG:GEN4_INIT_INT_LOG_PIC18F27Q43 com.microchip.mplab.libs.RI4ToolsController.implementations.ProgrammerToGoImpl@5fb49a55
354 1766956978646 GEN4_TO_CONTROLLER_LOG:GEN4_INIT_INT_LOG_PIC18F27Q43 Return End

354 1766956978646 GEN4_TO_CONTROLLER_LOG:GEN4_INIT_INT_LOG_PIC18F27Q43 Pre:GetInterfaceProvider
354 1766956978646 GEN4_TO_CONTROLLER_LOG:GEN4_INIT_INT_LOG_PIC18F27Q43 Payload
354 1766956978646 GEN4_TO_CONTROLLER_LOG:GEN4_INIT_INT_LOG_PIC18F27Q43 Status
354 1766956978646 GEN4_TO_CONTROLLER_LOG:GEN4_INIT_INT_LOG_PIC18F27Q43 Payload End
354 1766956978646 GEN4_TO_CONTROLLER_LOG:GEN4_INIT_INT_LOG_PIC18F27Q43 Post:GetInterfaceProvider
354 1766956978646 GEN4_TO_CONTROLLER_LOG:GEN4_INIT_INT_LOG_PIC18F27Q43 Return Value
354 1766956978646 GEN4_TO_CONTROLLER_LOG:GEN4_INIT_INT_LOG_PIC18F27Q43 null
354 1766956978646 GEN4_TO_CONTROLLER_LOG:GEN4_INIT_INT_LOG_PIC18F27Q43 Return End

354 1766956978664 GEN4_TO_CONTROLLER_LOG:GEN4_PROGRAM_INT_LOG_PIC18F27Q43 Pre:SetDebugExec
354 1766956978664 GEN4_TO_CONTROLLER_LOG:GEN4_PROGRAM_INT_LOG_PIC18F27Q43 Payload
354 1766956978664 GEN4_TO_CONTROLLER_LOG:GEN4_PROGRAM_INT_LOG_PIC18F27Q43 Test
354 1766956978664 GEN4_TO_CONTROLLER_LOG:GEN4_PROGRAM_INT_LOG_PIC18F27Q43 240000
354 1766956978664 GEN4_TO_CONTROLLER_LOG:GEN4_PROGRAM_INT_LOG_PIC18F27Q43 Length = 870
354 1766956978664 GEN4_TO_CONTROLLER_LOG:GEN4_PROGRAM_INT_LOG_PIC18F27Q43 Payload End
354 1766956978666 GEN4_TO_CONTROLLER_LOG:GEN4_PROGRAM_INT_LOG_PIC18F27Q43 Post:SetDebugExec
354 1766956978666 GEN4_TO_CONTROLLER_LOG:GEN4_PROGRAM_INT_LOG_PIC18F27Q43 Return Value
354 1766956978666 GEN4_TO_CONTROLLER_LOG:GEN4_PROGRAM_INT_LOG_PIC18F27Q43 true
354 1766956978666 GEN4_TO_CONTROLLER_LOG:GEN4_PROGRAM_INT_LOG_PIC18F27Q43 Return End

354 1766956978667 GEN4_TO_CONTROLLER_LOG:GEN4_CONNECT_INT_LOG_PIC18F27Q43 Pre:EstablishCommunincations
354 1766956978667 GEN4_TO_CONTROLLER_LOG:GEN4_CONNECT_INT_LOG_PIC18F27Q43 Payload
354 1766956978667 GEN4_TO_CONTROLLER_LOG:GEN4_CONNECT_INT_LOG_PIC18F27Q43 com.microchip.mplab.mdbcore.PK5Tool.PK5Com@79b0f414
354 1766956978667 GEN4_TO_CONTROLLER_LOG:GEN4_CONNECT_INT_LOG_PIC18F27Q43 Payload End
354 1766956978667 GEN4_TO_CONTROLLER_LOG:GEN4_CONNECT_INT_LOG_PIC18F27Q43 Post:EstablishCommunincations
354 1766956978667 GEN4_TO_CONTROLLER_LOG:GEN4_CONNECT_INT_LOG_PIC18F27Q43 Return Value
354 1766956978667 GEN4_TO_CONTROLLER_LOG:GEN4_CONNECT_INT_LOG_PIC18F27Q43 true
354 1766956978667 GEN4_TO_CONTROLLER_LOG:GEN4_CONNECT_INT_LOG_PIC18F27Q43 Return End

354 1766956978667 GEN4_TO_CONTROLLER_LOG:GEN4_CONNECT_INT_LOG_PIC18F27Q43 Pre:GetFirmwareInfo
354 1766956978667 GEN4_TO_CONTROLLER_LOG:GEN4_CONNECT_INT_LOG_PIC18F27Q43 Payload
354 1766956978667 GEN4_TO_CONTROLLER_LOG:GEN4_CONNECT_INT_LOG_PIC18F27Q43 null
354 1766956978667 GEN4_TO_CONTROLLER_LOG:GEN4_CONNECT_INT_LOG_PIC18F27Q43 Payload End
354 1766956978675 GEN4_TO_CONTROLLER_LOG:GEN4_CONNECT_INT_LOG_PIC18F27Q43 Post:GetFirmwareInfo
354 1766956978675 GEN4_TO_CONTROLLER_LOG:GEN4_CONNECT_INT_LOG_PIC18F27Q43 Return Value
354 1766956978675 GEN4_TO_CONTROLLER_LOG:GEN4_CONNECT_INT_LOG_PIC18F27Q43 FirmwareInfo: Values:
354 1766956978675 GEN4_TO_CONTROLLER_LOG:GEN4_CONNECT_INT_LOG_PIC18F27Q43 FirmwareInfo: boot = false, bootVer = 00.00.68, apVer = 02.05.47, fpgaVer = ff.ff.ff, scriptVer = 00.10.08, macAddress = 0504883548174844851484953485250, devID = a1020e01, devID1 = 2, devSN0 = ffffffff, devSN1 = ffffffff, serialNumber = 020026702RYN005992, appCommitID = null, scriptCommitID = f91823efd7, PCB_ID = 2
354 1766956978675 GEN4_TO_CONTROLLER_LOG:GEN4_CONNECT_INT_LOG_PIC18F27Q43 Return End
354 1766956978676 XXXX 1766956978676, Thread 354: XXXX 1766956978676, Entering Thread 354: Commands::runScriptWithUpload with script contents. contents[0] = 0x5e, ...  
354 1766956978676 XXXX 1766956978676, Thread 354: XXXX 1766956978676, Entering Thread 354: ToolCommUsb::readTransfer, sideData is 0xd bytes long, transferDataLength is 0x4 bytes long  
354 1766956978679 XXXX 1766956978679, Thread 354: XXXX 1766956978679, Exiting Thread 354: ToolCommUsb::readTransfer,  cr.status = 0x0  
354 1766956978679 XXXX 1766956978679, Thread 354: XXXX 1766956978679, Exiting Thread 354: Commands::runScriptWithUpload  
354 1766956978679 GEN4_CONNECT_DIAGNOSTICS:ENTERING: com.microchip.mplab.mdbcore.RI4Tool.ConnectionHandler.CheckForFWUpdates()
354 1766956978679 GEN4_CONNECT_DIAGNOSTICS:Created FirmwareUpdateHandler com.microchip.mplab.mdbcore.PK5Tool.PK5FirmwareUpdateHandler@28e346f2
354 1766956978679 GEN4_CONNECT_DIAGNOSTICS:ENTERING: com.microchip.mplab.mdbcore.RI4Tool.FirmwareUpdateHandler.GetUpdateInfo()
354 1766956978680 GEN4_CONNECT_DIAGNOSTICS:Parsing file  for firmware updates
354 1766956978680 GEN4_CONNECT_DIAGNOSTICS:ENTERING: com.microchip.mplab.mdbcore.RI4Tool.FirmwareUpdateHandler.ri4ParseSelectedVersionsFromJamFile()
354 1766956978680 GEN4_CONNECT_DIAGNOSTICS:Jame file line = app.hex,020547
354 1766956978680 GEN4_CONNECT_DIAGNOSTICS:Jame file line = boot.hex,000068
354 1766956978680 GEN4_CONNECT_DIAGNOSTICS:Jame file line = scripts.xml,001008
354 1766956978680 GEN4_CONNECT_DIAGNOSTICS:Selected firmware version for Boot = 00.00.68
354 1766956978680 GEN4_CONNECT_DIAGNOSTICS:Selected firmware version for ap = 02.05.47
354 1766956978680 GEN4_CONNECT_DIAGNOSTICS:EXITING: com.microchip.mplab.mdbcore.RI4Tool.FirmwareUpdateHandler.ri4ParseSelectedVersionsFromJamFile()
354 1766956978680 GEN4_CONNECT_DIAGNOSTICS:EXITING: com.microchip.mplab.mdbcore.RI4Tool.FirmwareUpdateHandler.GetUpdateInfo()
354 1766956978680 GEN4_CONNECT_DIAGNOSTICS:ENTERING: com.microchip.mplab.mdbcore.RI4Tool.FirmwareUpdateHandler.updateRI4ToolsFirmware(FirmwareInfo, UpdateMessage)
354 1766956978687 GEN4_CONNECT_DIAGNOSTICS:appNeedsUpdate returned false
354 1766956978687 GEN4_CONNECT_DIAGNOSTICS:EXITING: com.microchip.mplab.mdbcore.RI4Tool.FirmwareUpdateHandler.updateRI4ToolsFirmware(FirmwareInfo, UpdateMessage)
354 1766956978687 GEN4_CONNECT_DIAGNOSTICS:EXITING: com.microchip.mplab.mdbcore.RI4Tool.ConnectionHandler.CheckForFWUpdates()

354 1766956978687 GEN4_TO_CONTROLLER_LOG:GEN4_CONNECT_INT_LOG_PIC18F27Q43 Pre:SetPowerInfo
354 1766956978687 GEN4_TO_CONTROLLER_LOG:GEN4_CONNECT_INT_LOG_PIC18F27Q43 Payload
354 1766956978687 GEN4_TO_CONTROLLER_LOG:GEN4_CONNECT_INT_LOG_PIC18F27Q43 PowerInfo: Values:
354 1766956978688 GEN4_TO_CONTROLLER_LOG:GEN4_CONNECT_INT_LOG_PIC18F27Q43 PowerInfo: shotDownSystem = false, isToolPower = false, voltage = 5.000000, useVppFirst = false, useLowVoltageProgramming = false, useMaintainActivePower = false
354 1766956978688 GEN4_TO_CONTROLLER_LOG:GEN4_CONNECT_INT_LOG_PIC18F27Q43 Payload End
354 1766956978688 XXXX 1766956978688, Thread 354: XXXX 1766956978688, Entering Thread 354: Commands::runScriptBasic with script contents. contents[0] = 0x39, ...  
354 1766956978689 XXXX 1766956978689, Thread 354: XXXX 1766956978689, Exiting Thread 354: Commands::runScriptBasic  
354 1766956978689 XXXX 1766956978689, Thread 354: XXXX 1766956978689, Entering Thread 354: Commands::runScriptBasic with script contents. contents[0] = 0x46, ...  
354 1766956978690 XXXX 1766956978690, Thread 354: XXXX 1766956978690, Exiting Thread 354: Commands::runScriptBasic  
354 1766956978690 XXXX 1766956978690, Thread 354: XXXX 1766956978690, Entering Thread 354: Commands::runScriptBasic with script contents. contents[0] = 0x44, ...  
354 1766956978702 XXXX 1766956978702, Thread 354: XXXX 1766956978702, Exiting Thread 354: Commands::runScriptBasic  
354 1766956978702 XXXX 1766956978702, Thread 354: XXXX 1766956978702, Entering Thread 354: Commands::runScriptBasic with script contents. contents[0] = 0xef, ...  
354 1766956978713 XXXX 1766956978713, Thread 354: XXXX 1766956978713, Exiting Thread 354: Commands::runScriptBasic  
354 1766956978713 XXXX 1766956978713, Thread 354: XXXX 1766956978713, Entering Thread 354: Commands::runScriptBasic with script contents. contents[0] = 0x40, ...  
354 1766956979114 XXXX 1766956979114, Thread 354: XXXX 1766956979114, Exiting Thread 354: Commands::runScriptBasic  
354 1766956979114 XXXX 1766956979114, Thread 354: XXXX 1766956979114, Entering Thread 354: Commands::runScriptBasic with script contents. contents[0] = 0x47, ...  
354 1766956979119 XXXX 1766956979119, Thread 354: XXXX 1766956979119, Exiting Thread 354: Commands::runScriptBasic  
354 1766956979119 GEN4_TO_CONTROLLER_LOG:GEN4_CONNECT_INT_LOG_PIC18F27Q43 Post:SetPowerInfo
354 1766956979119 GEN4_TO_CONTROLLER_LOG:GEN4_CONNECT_INT_LOG_PIC18F27Q43 Return Value
354 1766956979119 GEN4_TO_CONTROLLER_LOG:GEN4_CONNECT_INT_LOG_PIC18F27Q43 none
354 1766956979119 GEN4_TO_CONTROLLER_LOG:GEN4_CONNECT_INT_LOG_PIC18F27Q43 Return End

354 1766956979119 GEN4_TO_CONTROLLER_LOG:GEN4_CONNECT_INT_LOG_PIC18F27Q43 Pre:SetLEDBrightness
354 1766956979119 GEN4_TO_CONTROLLER_LOG:GEN4_CONNECT_INT_LOG_PIC18F27Q43 Payload
354 1766956979119 GEN4_TO_CONTROLLER_LOG:GEN4_CONNECT_INT_LOG_PIC18F27Q43 5
354 1766956979119 GEN4_TO_CONTROLLER_LOG:GEN4_CONNECT_INT_LOG_PIC18F27Q43 Payload End
354 1766956979119 XXXX 1766956979119, Thread 354: XXXX 1766956979119, Entering Thread 354: Commands::runScriptBasic with script contents. contents[0] = 0xcf, ...  
354 1766956979120 XXXX 1766956979120, Thread 354: XXXX 1766956979120, Exiting Thread 354: Commands::runScriptBasic  
354 1766956979120 GEN4_TO_CONTROLLER_LOG:GEN4_CONNECT_INT_LOG_PIC18F27Q43 Post:SetLEDBrightness
354 1766956979120 GEN4_TO_CONTROLLER_LOG:GEN4_CONNECT_INT_LOG_PIC18F27Q43 Return Value
354 1766956979120 GEN4_TO_CONTROLLER_LOG:GEN4_CONNECT_INT_LOG_PIC18F27Q43 none
354 1766956979120 GEN4_TO_CONTROLLER_LOG:GEN4_CONNECT_INT_LOG_PIC18F27Q43 Return End

354 1766956979120 GEN4_TO_CONTROLLER_LOG:GEN4_CONNECT_INT_LOG_PIC18F27Q43 Pre:SetToolInfo
354 1766956979120 GEN4_TO_CONTROLLER_LOG:GEN4_CONNECT_INT_LOG_PIC18F27Q43 Payload
354 1766956979120 GEN4_TO_CONTROLLER_LOG:GEN4_CONNECT_INT_LOG_PIC18F27Q43 ToolInfo: Values:
354 1766956979120 GEN4_TO_CONTROLLER_LOG:GEN4_CONNECT_INT_LOG_PIC18F27Q43 ToolInfo: speedLevel = 1, PGCResistance = 4700, PGDResistance = 4700, PGCPullDir = PullDown, PGDPullDir = PullDown, ICSPSelected = Wire2
354 1766956979120 GEN4_TO_CONTROLLER_LOG:GEN4_CONNECT_INT_LOG_PIC18F27Q43 Payload End
354 1766956979120 XXXX 1766956979120, Thread 354: XXXX 1766956979120, Entering Thread 354: Commands::runScriptBasic with script contents. contents[0] = 0x27, ...  
354 1766956979121 XXXX 1766956979121, Thread 354: XXXX 1766956979121, Exiting Thread 354: Commands::runScriptBasic  
354 1766956979121 XXXX 1766956979121, Thread 354: XXXX 1766956979121, Entering Thread 354: Commands::runScriptBasic, script name = SetSpeedFromDevice, timeOut = -1 ms  
354 1766956979122 XXXX 1766956979122, Thread 354: XXXX 1766956979122, Exiting Thread 354: Commands::runScriptBasic  
354 1766956979122 XXXX 1766956979122, Thread 354: XXXX 1766956979122, Entering Thread 354: Commands::runScriptBasic with script contents. contents[0] = 0xed, ...  
354 1766956979123 XXXX 1766956979123, Thread 354: XXXX 1766956979123, Exiting Thread 354: Commands::runScriptBasic  
354 1766956979123 XXXX 1766956979123, Thread 354: XXXX 1766956979123, Entering Thread 354: Commands::runScriptBasic with script contents. contents[0] = 0xec, ...  
354 1766956979124 XXXX 1766956979124, Thread 354: XXXX 1766956979124, Exiting Thread 354: Commands::runScriptBasic  
354 1766956979124 XXXX 1766956979124, Thread 354: XXXX 1766956979124, Entering Thread 354: Commands::runScriptBasic with script contents. contents[0] = 0xd4, ...  
354 1766956979125 XXXX 1766956979125, Thread 354: XXXX 1766956979125, Exiting Thread 354: Commands::runScriptBasic  
354 1766956979125 XXXX 1766956979125, Thread 354: XXXX 1766956979125, Entering Thread 354: Commands::runScriptBasic with script contents. contents[0] = 0xcd, ...  
354 1766956979126 XXXX 1766956979126, Thread 354: XXXX 1766956979126, Exiting Thread 354: Commands::runScriptBasic  
354 1766956979126 XXXX 1766956979126, Thread 354: XXXX 1766956979126, Entering Thread 354: Commands::runScriptBasic with script contents. contents[0] = 0xce, ...  
354 1766956979127 XXXX 1766956979127, Thread 354: XXXX 1766956979127, Exiting Thread 354: Commands::runScriptBasic  
354 1766956979127 XXXX 1766956979127, Thread 354: XXXX 1766956979127, Entering Thread 354: Commands::runScriptBasic with script contents. contents[0] = 0xcd, ...  
354 1766956979128 XXXX 1766956979128, Thread 354: XXXX 1766956979128, Exiting Thread 354: Commands::runScriptBasic  
354 1766956979128 XXXX 1766956979128, Thread 354: XXXX 1766956979128, Entering Thread 354: Commands::runScriptBasic with script contents. contents[0] = 0xce, ...  
354 1766956979129 XXXX 1766956979129, Thread 354: XXXX 1766956979129, Exiting Thread 354: Commands::runScriptBasic  
354 1766956979129 GEN4_TO_CONTROLLER_LOG:GEN4_CONNECT_INT_LOG_PIC18F27Q43 Post:SetToolInfo
354 1766956979129 GEN4_TO_CONTROLLER_LOG:GEN4_CONNECT_INT_LOG_PIC18F27Q43 Return Value
354 1766956979129 GEN4_TO_CONTROLLER_LOG:GEN4_CONNECT_INT_LOG_PIC18F27Q43 none
354 1766956979129 GEN4_TO_CONTROLLER_LOG:GEN4_CONNECT_INT_LOG_PIC18F27Q43 Return End

354 1766956979131 GEN4_TO_CONTROLLER_LOG:GEN4_PROGRAM_INT_LOG_PIC18F27Q43 Pre:SendOperation
354 1766956979131 GEN4_TO_CONTROLLER_LOG:GEN4_PROGRAM_INT_LOG_PIC18F27Q43 Payload
354 1766956979131 GEN4_TO_CONTROLLER_LOG:GEN4_PROGRAM_INT_LOG_PIC18F27Q43 OperationInfo: Values:
354 1766956979131 GEN4_TO_CONTROLLER_LOG:GEN4_PROGRAM_INT_LOG_PIC18F27Q43 OperationInfo: Type = read, Mask = 00000000, Erase = false, Production Mode = true
354 1766956979131 GEN4_TO_CONTROLLER_LOG:GEN4_PROGRAM_INT_LOG_PIC18F27Q43 TransferInfo: Start = 300003, End = 300003, Buffer Length = 1, Type = Cfg, Mask = 00000000
354 1766956979131 GEN4_TO_CONTROLLER_LOG:GEN4_PROGRAM_INT_LOG_PIC18F27Q43 Payload End
354 1766956979131 XXXX 1766956979131, Thread 354: XXXX 1766956979131, Entering Thread 354: Commands::runScriptBasic, script name = SetSpeedFromDevice, timeOut = -1 ms  
354 1766956979132 XXXX 1766956979132, Thread 354: XXXX 1766956979132, Exiting Thread 354: Commands::runScriptBasic  
354 1766956979132 XXXX 1766956979132, Thread 354: XXXX 1766956979132, Entering Thread 354: Commands::runScriptBasic with script contents. contents[0] = 0xed, ...  
354 1766956979133 XXXX 1766956979133, Thread 354: XXXX 1766956979133, Exiting Thread 354: Commands::runScriptBasic  
354 1766956979133 XXXX 1766956979133, Thread 354: XXXX 1766956979133, Entering Thread 354: Commands::runScriptBasic with script contents. contents[0] = 0xec, ...  
354 1766956979134 XXXX 1766956979134, Thread 354: XXXX 1766956979134, Exiting Thread 354: Commands::runScriptBasic  
354 1766956979134 XXXX 1766956979134, Thread 354: XXXX 1766956979134, Entering Thread 354: Commands::runScriptBasic, script name = EnterTMOD_HV, timeOut = -1 ms  
354 1766956979210 XXXX 1766956979210, Thread 354: XXXX 1766956979210, Exiting Thread 354: Commands::runScriptBasic  
354 1766956979210 XXXX 1766956979210, Thread 354: XXXX 1766956979210, Entering Thread 354: Commands::runScriptBasic, script name = SetSpeedFromDevice, timeOut = -1 ms  
354 1766956979212 XXXX 1766956979212, Thread 354: XXXX 1766956979212, Exiting Thread 354: Commands::runScriptBasic  
354 1766956979212 XXXX 1766956979212, Thread 354: XXXX 1766956979212, Entering Thread 354: Commands::runScriptBasic with script contents. contents[0] = 0xed, ...  
354 1766956979213 XXXX 1766956979213, Thread 354: XXXX 1766956979213, Exiting Thread 354: Commands::runScriptBasic  
354 1766956979213 XXXX 1766956979213, Thread 354: XXXX 1766956979213, Entering Thread 354: Commands::runScriptBasic with script contents. contents[0] = 0xec, ...  
354 1766956979214 XXXX 1766956979214, Thread 354: XXXX 1766956979214, Exiting Thread 354: Commands::runScriptBasic  
354 1766956979214 XXXX 1766956979214, Thread 354: XXXX 1766956979214, Entering Thread 354: Commands::runScriptBasic, script name = EnterTMOD_HV, timeOut = -1 ms  
354 1766956979245 XXXX 1766956979245, Thread 354: XXXX 1766956979245, Exiting Thread 354: Commands::runScriptBasic  
354 1766956979245 XXXX 1766956979245, Thread 354: XXXX 1766956979245, Entering Thread 354: Commands::runScriptWithUpload, script name = ReadConfigmem  
354 1766956979245 XXXX 1766956979245, Thread 354: XXXX 1766956979245, Entering Thread 354: ToolCommUsb::readTransfer, sideData is 0x37 bytes long, transferDataLength is 0x2 bytes long  
354 1766956979249 XXXX 1766956979249, Thread 354: XXXX 1766956979249, Exiting Thread 354: ToolCommUsb::readTransfer,  cr.status = 0x0  
354 1766956979249 XXXX 1766956979249, Thread 354: XXXX 1766956979249, Exiting Thread 354: Commands::runScriptWithUpload  
354 1766956979249 XXXX 1766956979249, Thread 354: XXXX 1766956979249, Entering Thread 354: Commands::runScriptBasic, script name = ExitTMOD, timeOut = -1 ms  
354 1766956979251 XXXX 1766956979251, Thread 354: XXXX 1766956979251, Exiting Thread 354: Commands::runScriptBasic  
354 1766956979251 GEN4_TO_CONTROLLER_LOG:GEN4_PROGRAM_INT_LOG_PIC18F27Q43 Post:SendOperation
354 1766956979251 GEN4_TO_CONTROLLER_LOG:GEN4_PROGRAM_INT_LOG_PIC18F27Q43 Return Value
354 1766956979251 GEN4_TO_CONTROLLER_LOG:GEN4_PROGRAM_INT_LOG_PIC18F27Q43 None
354 1766956979251 GEN4_TO_CONTROLLER_LOG:GEN4_PROGRAM_INT_LOG_PIC18F27Q43 Return End

354 1766956979251 GEN4_TO_CONTROLLER_LOG:GEN4_CONNECT_INT_LOG_PIC18F27Q43 Pre:GetTargetIDInfo
354 1766956979251 GEN4_TO_CONTROLLER_LOG:GEN4_CONNECT_INT_LOG_PIC18F27Q43 Payload
354 1766956979251 GEN4_TO_CONTROLLER_LOG:GEN4_CONNECT_INT_LOG_PIC18F27Q43 null
354 1766956979251 GEN4_TO_CONTROLLER_LOG:GEN4_CONNECT_INT_LOG_PIC18F27Q43 Payload End
354 1766956979253 XXXX 1766956979253, Thread 354: XXXX 1766956979253, Entering Thread 354: Commands::runScriptBasic, script name = SetSpeedFromDevice, timeOut = -1 ms  
354 1766956979254 XXXX 1766956979254, Thread 354: XXXX 1766956979254, Exiting Thread 354: Commands::runScriptBasic  
354 1766956979254 XXXX 1766956979254, Thread 354: XXXX 1766956979254, Entering Thread 354: Commands::runScriptBasic with script contents. contents[0] = 0xed, ...  
354 1766956979255 XXXX 1766956979255, Thread 354: XXXX 1766956979255, Exiting Thread 354: Commands::runScriptBasic  
354 1766956979255 XXXX 1766956979255, Thread 354: XXXX 1766956979255, Entering Thread 354: Commands::runScriptBasic with script contents. contents[0] = 0xec, ...  
354 1766956979256 XXXX 1766956979256, Thread 354: XXXX 1766956979256, Exiting Thread 354: Commands::runScriptBasic  
354 1766956979256 XXXX 1766956979256, Thread 354: XXXX 1766956979256, Entering Thread 354: Commands::runScriptBasic, script name = EnterTMOD_HV, timeOut = -1 ms  
354 1766956979285 XXXX 1766956979285, Thread 354: XXXX 1766956979285, Exiting Thread 354: Commands::runScriptBasic  
354 1766956979285 XXXX 1766956979285, Thread 354: XXXX 1766956979285, Entering Thread 354: Commands::runScriptBasic, script name = GetDeviceID, timeOut = -1 ms  
354 1766956979286 XXXX 1766956979286, Thread 354: XXXX 1766956979286, Exiting Thread 354: Commands::runScriptBasic  
354 1766956979286 XXXX 1766956979286, Thread 354: XXXX 1766956979286, Entering Thread 354: Commands::runScriptBasic, script name = ExitTMOD, timeOut = -1 ms  
354 1766956979288 XXXX 1766956979288, Thread 354: XXXX 1766956979288, Exiting Thread 354: Commands::runScriptBasic  
354 1766956979288 GEN4_TO_CONTROLLER_LOG:GEN4_CONNECT_INT_LOG_PIC18F27Q43 Post:GetTargetIDInfo
354 1766956979288 GEN4_TO_CONTROLLER_LOG:GEN4_CONNECT_INT_LOG_PIC18F27Q43 Return Value
354 1766956979288 GEN4_TO_CONTROLLER_LOG:GEN4_CONNECT_INT_LOG_PIC18F27Q43 TargetIDInfo: Values:
354 1766956979288 GEN4_TO_CONTROLLER_LOG:GEN4_CONNECT_INT_LOG_PIC18F27Q43 TargetIDInfo: DeviceID = ffffffffa0437480
354 1766956979288 GEN4_TO_CONTROLLER_LOG:GEN4_CONNECT_INT_LOG_PIC18F27Q43 Return End

354 1766956979315 GEN4_TO_CONTROLLER_LOG:GEN4_PROGRAM_INT_LOG_PIC18F27Q43 Pre:SendOperation
354 1766956979315 GEN4_TO_CONTROLLER_LOG:GEN4_PROGRAM_INT_LOG_PIC18F27Q43 Payload
354 1766956979315 GEN4_TO_CONTROLLER_LOG:GEN4_PROGRAM_INT_LOG_PIC18F27Q43 OperationInfo: Values:
354 1766956979315 GEN4_TO_CONTROLLER_LOG:GEN4_PROGRAM_INT_LOG_PIC18F27Q43 OperationInfo: Type = erase, Mask = 00000000, Erase = false, Production Mode = false
354 1766956979315 GEN4_TO_CONTROLLER_LOG:GEN4_PROGRAM_INT_LOG_PIC18F27Q43 TransferInfo: Start = 0, End = 1ffff, Buffer Length = 0, Type = Pgm, Mask = 00000000
354 1766956979315 GEN4_TO_CONTROLLER_LOG:GEN4_PROGRAM_INT_LOG_PIC18F27Q43 TransferInfo: Start = 300000, End = 300011, Buffer Length = 0, Type = Cfg, Mask = 00000000
354 1766956979315 GEN4_TO_CONTROLLER_LOG:GEN4_PROGRAM_INT_LOG_PIC18F27Q43 TransferInfo: Start = 380000, End = 3803ff, Buffer Length = 0, Type = EEData, Mask = 00000000
354 1766956979315 GEN4_TO_CONTROLLER_LOG:GEN4_PROGRAM_INT_LOG_PIC18F27Q43 TransferInfo: Start = 200000, End = 20003f, Buffer Length = 0, Type = UserID, Mask = 00000000
354 1766956979315 GEN4_TO_CONTROLLER_LOG:GEN4_PROGRAM_INT_LOG_PIC18F27Q43 Payload End
354 1766956979315 XXXX 1766956979315, Thread 354: XXXX 1766956979315, Entering Thread 354: Commands::runScriptBasic, script name = SetSpeedFromDevice, timeOut = -1 ms  
354 1766956979316 XXXX 1766956979316, Thread 354: XXXX 1766956979316, Exiting Thread 354: Commands::runScriptBasic  
354 1766956979316 XXXX 1766956979316, Thread 354: XXXX 1766956979316, Entering Thread 354: Commands::runScriptBasic with script contents. contents[0] = 0xed, ...  
354 1766956979317 XXXX 1766956979317, Thread 354: XXXX 1766956979317, Exiting Thread 354: Commands::runScriptBasic  
354 1766956979317 XXXX 1766956979317, Thread 354: XXXX 1766956979317, Entering Thread 354: Commands::runScriptBasic with script contents. contents[0] = 0xec, ...  
354 1766956979318 XXXX 1766956979318, Thread 354: XXXX 1766956979318, Exiting Thread 354: Commands::runScriptBasic  
354 1766956979318 XXXX 1766956979318, Thread 354: XXXX 1766956979318, Entering Thread 354: Commands::runScriptBasic, script name = EnterTMOD_HV, timeOut = -1 ms  
354 1766956979372 XXXX 1766956979372, Thread 354: XXXX 1766956979372, Exiting Thread 354: Commands::runScriptBasic  
354 1766956979372 XXXX 1766956979372, Thread 354: XXXX 1766956979372, Entering Thread 354: Commands::runScriptBasic, script name = SetSpeedFromDevice, timeOut = -1 ms  
354 1766956979373 XXXX 1766956979373, Thread 354: XXXX 1766956979373, Exiting Thread 354: Commands::runScriptBasic  
354 1766956979373 XXXX 1766956979373, Thread 354: XXXX 1766956979373, Entering Thread 354: Commands::runScriptBasic with script contents. contents[0] = 0xed, ...  
354 1766956979374 XXXX 1766956979374, Thread 354: XXXX 1766956979374, Exiting Thread 354: Commands::runScriptBasic  
354 1766956979374 XXXX 1766956979374, Thread 354: XXXX 1766956979374, Entering Thread 354: Commands::runScriptBasic with script contents. contents[0] = 0xec, ...  
354 1766956979375 XXXX 1766956979375, Thread 354: XXXX 1766956979375, Exiting Thread 354: Commands::runScriptBasic  
354 1766956979375 XXXX 1766956979375, Thread 354: XXXX 1766956979375, Entering Thread 354: Commands::runScriptBasic, script name = EnterTMOD_HV, timeOut = -1 ms  
354 1766956979404 XXXX 1766956979404, Thread 354: XXXX 1766956979404, Exiting Thread 354: Commands::runScriptBasic  
354 1766956979404 XXXX 1766956979404, Thread 354: XXXX 1766956979404, Entering Thread 354: Commands::runScriptBasic, script name = EraseChip, timeOut = 30000 ms  
354 1766956979416 XXXX 1766956979416, Thread 354: XXXX 1766956979416, Exiting Thread 354: Commands::runScriptBasic  
354 1766956979416 XXXX 1766956979416, Thread 354: XXXX 1766956979416, Entering Thread 354: Commands::runScriptBasic, script name = ExitTMOD, timeOut = -1 ms  
354 1766956979418 XXXX 1766956979418, Thread 354: XXXX 1766956979418, Exiting Thread 354: Commands::runScriptBasic  
354 1766956979418 XXXX 1766956979418, Thread 354: XXXX 1766956979418, Entering Thread 354: Commands::runScriptBasic, script name = SetSpeedFromDevice, timeOut = -1 ms  
354 1766956979419 XXXX 1766956979419, Thread 354: XXXX 1766956979419, Exiting Thread 354: Commands::runScriptBasic  
354 1766956979419 XXXX 1766956979419, Thread 354: XXXX 1766956979419, Entering Thread 354: Commands::runScriptBasic with script contents. contents[0] = 0xed, ...  
354 1766956979420 XXXX 1766956979420, Thread 354: XXXX 1766956979420, Exiting Thread 354: Commands::runScriptBasic  
354 1766956979420 XXXX 1766956979420, Thread 354: XXXX 1766956979420, Entering Thread 354: Commands::runScriptBasic with script contents. contents[0] = 0xec, ...  
354 1766956979421 XXXX 1766956979421, Thread 354: XXXX 1766956979421, Exiting Thread 354: Commands::runScriptBasic  
354 1766956979421 XXXX 1766956979421, Thread 354: XXXX 1766956979421, Entering Thread 354: Commands::runScriptBasic, script name = EnterTMOD_HV, timeOut = -1 ms  
354 1766956979452 XXXX 1766956979452, Thread 354: XXXX 1766956979452, Exiting Thread 354: Commands::runScriptBasic  
354 1766956979452 XXXX 1766956979452, Thread 354: XXXX 1766956979452, Entering Thread 354: Commands::runScriptBasic, script name = EraseDataEEmem, timeOut = 30000 ms  
354 1766956979464 XXXX 1766956979464, Thread 354: XXXX 1766956979464, Exiting Thread 354: Commands::runScriptBasic  
354 1766956979464 XXXX 1766956979464, Thread 354: XXXX 1766956979464, Entering Thread 354: Commands::runScriptBasic, script name = ExitTMOD, timeOut = -1 ms  
354 1766956979466 XXXX 1766956979466, Thread 354: XXXX 1766956979466, Exiting Thread 354: Commands::runScriptBasic  
354 1766956979466 GEN4_TO_CONTROLLER_LOG:GEN4_PROGRAM_INT_LOG_PIC18F27Q43 Post:SendOperation
354 1766956979466 GEN4_TO_CONTROLLER_LOG:GEN4_PROGRAM_INT_LOG_PIC18F27Q43 Return Value
354 1766956979466 GEN4_TO_CONTROLLER_LOG:GEN4_PROGRAM_INT_LOG_PIC18F27Q43 None
354 1766956979466 GEN4_TO_CONTROLLER_LOG:GEN4_PROGRAM_INT_LOG_PIC18F27Q43 Return End
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

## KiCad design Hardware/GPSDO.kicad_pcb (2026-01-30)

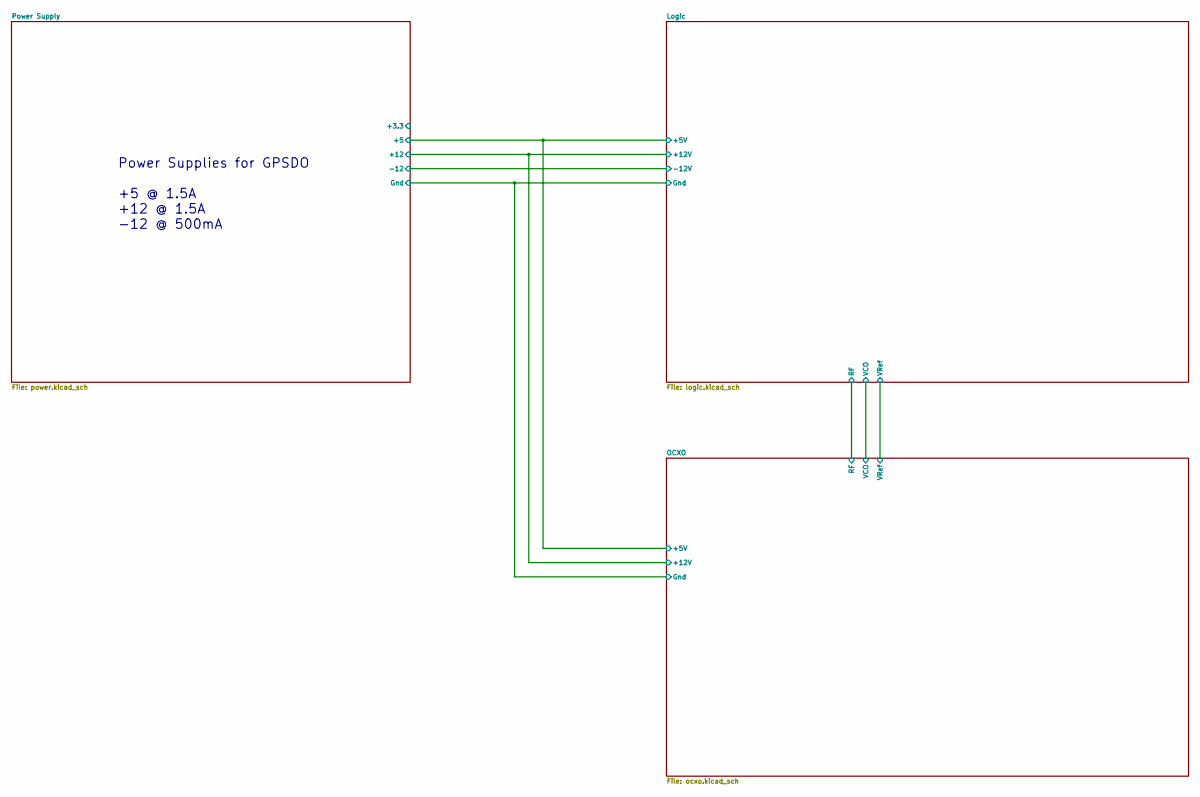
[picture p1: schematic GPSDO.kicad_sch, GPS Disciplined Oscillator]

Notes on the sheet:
Power Supplies for GPSDO +5 @ 1.5A +12 @ 1.5A -12 @ 500mA

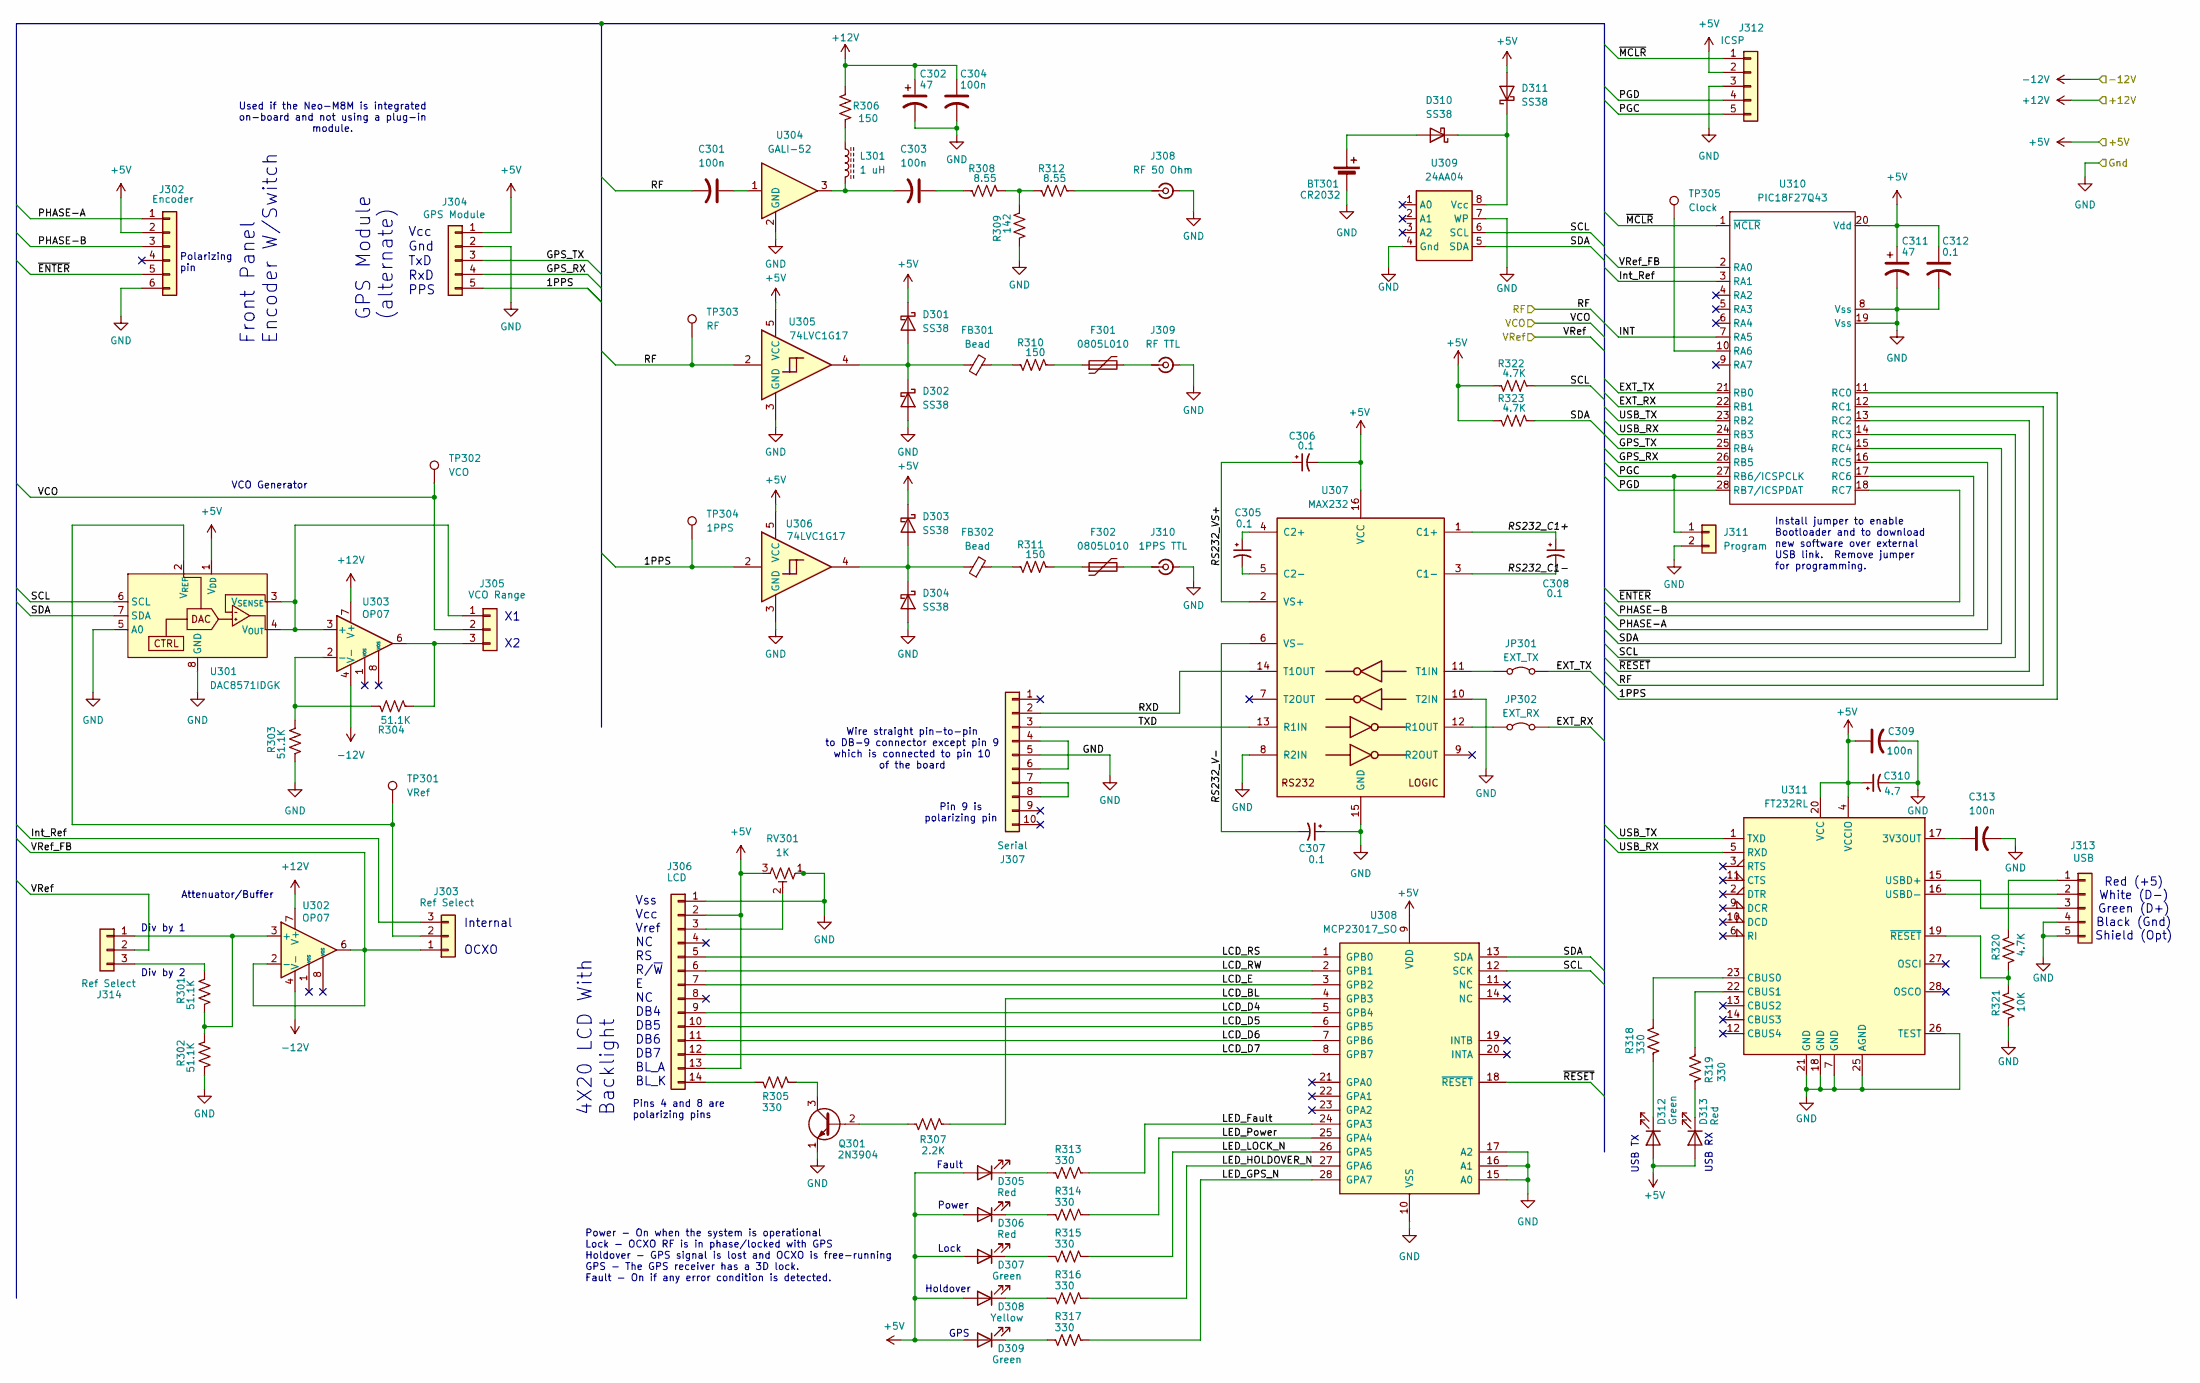
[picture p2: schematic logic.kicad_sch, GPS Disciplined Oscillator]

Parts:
BT301: CR2032; Battery_Panasonic_CR2032-HFN_Horizontal_CircularHoles
C301, C303, C304, C309, C313: 100n; C_0603_1608Metric_Pad1.08x0.95mm_HandSolder
C302, C311: 47; CP_Elec_8x6.9
C305, C306, C307, C308: 0.1; CP_Elec_4x5.4
C310: 4.7; CP_Elec_6.3x5.4
C312: 0.1; C_0603_1608Metric_Pad1.08x0.95mm_HandSolder
D301, D302, D303, D304, D310, D311: SS38; D_SMB_Handsoldering
D305, D306, D313: Red; LED_D3.0mm_Horizontal_O3.81mm_Z2.0mm
D307, D309, D312: Green; LED_D3.0mm_Horizontal_O3.81mm_Z2.0mm
D308: Yellow; LED_D3.0mm_Horizontal_O3.81mm_Z2.0mm
F301, F302: 0805L010; R_0805_2012Metric_Pad1.20x1.40mm_HandSolder
FB301, FB302: Bead; L_0805_2012Metric_Pad1.15x1.40mm_HandSolder
J302: Encoder; PinHeader_1x06_P2.54mm_Vertical
J303, J314: Ref Select; PinHeader_1x03_P2.54mm_Vertical
J304: GPS Module; PinHeader_1x05_P2.54mm_Vertical
J305: VCO Range; PinHeader_1x03_P2.54mm_Vertical
J306: LCD; PinHeader_1x14_P2.54mm_Vertical
J307: Serial; PinHeader_1x10_P2.54mm_Vertical
J308: RF 50 Ohm; SMA_Amphenol_901-144_Vertical
J309: RF TTL; SMA_Amphenol_901-144_Vertical
J310: 1PPS TTL; SMA_Amphenol_901-144_Vertical
J311: Program; PinHeader_1x02_P2.54mm_Vertical
J312: ICSP; PinHeader_1x05_P2.54mm_Vertical
J313: USB; PinSocket_1x05_P2.54mm_Vertical
JP301: EXT_TX; R_Box_L26.0mm_W5.0mm_P20.00mm
JP302: EXT_RX; R_Box_L26.0mm_W5.0mm_P20.00mm
L301: 1 uH; L_1206_3216Metric_Pad1.42x1.75mm_HandSolder
Q301: 2N3904; TO-92L_HandSolder
R301, R302, R303, R304: 51.1K; R_0805_2012Metric_Pad1.20x1.40mm_HandSolder
R305, R313, R314, R315, R316, R317, R318, R319: 330; R_0805_2012Metric_Pad1.20x1.40mm_HandSolder
R306, R310, R311: 150; R_0805_2012Metric_Pad1.20x1.40mm_HandSolder
R307: 2.2K; R_0805_2012Metric_Pad1.20x1.40mm_HandSolder
R308, R312: 8.55; R_0805_2012Metric_Pad1.20x1.40mm_HandSolder
R309: 142; R_0805_2012Metric_Pad1.20x1.40mm_HandSolder
R320, R322, R323: 4.7K; R_0805_2012Metric_Pad1.20x1.40mm_HandSolder
R321: 10K; R_0805_2012Metric_Pad1.20x1.40mm_HandSolder
RV301: 1K; Potentiometer_Bourns_3266W_Vertical
TP301: VRef; TestPoint_Bridge_Pitch2.54mm_Drill1.0mm
TP302: VCO; TestPoint_Bridge_Pitch2.54mm_Drill1.0mm
TP303: RF; TestPoint_Bridge_Pitch2.54mm_Drill1.0mm
TP304: 1PPS; TestPoint_Bridge_Pitch2.54mm_Drill1.0mm
TP305: Clock; TestPoint_Bridge_Pitch2.54mm_Drill1.0mm
U301: DAC8571IDGK; MSOP-8_3x3mm_P0.65mm
U302, U303: OP07; SOIC-8_3.9x4.9mm_P1.27mm
U304: GALI-52; SOT-89-3
U305, U306: 74LVC1G17; SOT-353_SC-70-5
U307: MAX232; DIP-16_W7.62mm_LongPads
U308: MCP23017_SO; SOIC-28W_7.5x17.9mm_P1.27mm
U309: 24AA04; SOIC-8_5.3x6.2mm_P1.27mm
U310: PIC18F27Q43; SOIC-28W_7.5x18.7mm_P1.27mm
U311: FT232RL; SSOP-28_5.3x10.2mm_P0.65mm

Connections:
+5V: C306.2, C309.1, C310.1, C311.1, C312.1, D301.1 (K), D303.1 (K), D305.2 (A), D306.2 (A), D307.2 (A), D308.2 (A), D309.2 (A), D311.2 (A), D312.2 (A), D313.2 (A), J302.2, J304.1, J306.2, J306.13, J312.2, R322.1, R323.1, RV301.3, U301.1 (V_{DD}), U305.5 (VCC), U306.5 (VCC), U307.16 (VCC), U308.9 (VDD), U310.20 (Vdd), U311.4 (VCCIO), U311.20 (VCC); also elsewhere on the board
+12V: C302.1, C304.1, R306.1, U302.7 (V+), U303.7 (V+); also elsewhere on the board
-12V: U302.4 (V-), U303.4 (V-); also elsewhere on the board
/Logic/1PPS: J304.5, TP304.1, U306.2, U310.11 (RC0)
/Logic/EXT_RX: JP302.2 (B), U310.22 (RB1)
/Logic/EXT_TX: JP301.2 (B), U310.21 (RB0)
/Logic/GPS_RX: J304.4, U310.26 (RB5)
/Logic/GPS_TX: J304.3, U310.25 (RB4)
/Logic/INT: U310.7 (RA5)
/Logic/Int_Ref: J303.3, U310.3 (RA1)
/Logic/LCD_BL: R307.2, U308.4 (GPB3)
/Logic/LCD_D4: J306.9, U308.5 (GPB4)
/Logic/LCD_D5: J306.10, U308.6 (GPB5)
/Logic/LCD_D6: J306.11, U308.7 (GPB6)
/Logic/LCD_D7: J306.12, U308.8 (GPB7)
/Logic/LCD_E: J306.7, U308.3 (GPB2)
/Logic/LCD_RS: J306.5, U308.1 (GPB0)
/Logic/LCD_RW: J306.6, U308.2 (GPB1)
/Logic/LED_Fault: R313.2, U308.24 (GPA3)
/Logic/LED_GPS_N: R317.2, U308.28 (GPA7)
/Logic/LED_HOLDOVER_N: R316.2, U308.27 (GPA6)
/Logic/LED_LOCK_N: R315.2, U308.26 (GPA5)
/Logic/LED_Power: R314.2, U308.25 (GPA4)
/Logic/PGC: J311.1, J312.5, U310.27 (RB6/ICSPCLK)
/Logic/PGD: J312.4, U310.28 (RB7/ICSPDAT)
/Logic/PHASE-A: J302.1, U310.16 (RC5)
/Logic/PHASE-B: J302.3, U310.17 (RC6)
/Logic/RF: C301.2, TP303.1, U305.2, U310.12 (RC1); also elsewhere on the board
/Logic/RS232_C1+: C308.1, U307.1 (C1+)
/Logic/RS232_C1-: C308.2, U307.3 (C1-)
/Logic/RS232_V-: C307.2, U307.6 (VS-)
/Logic/RS232_VS+: C306.1, U307.2 (VS+)
/Logic/RXD: J307.2, U307.14 (T1OUT)
/Logic/SCL: R322.2, U301.6 (SCL), U308.12 (SCK), U309.6 (SCL), U310.14 (RC3)
/Logic/SDA: R323.2, U301.7 (SDA), U308.13 (SDA), U309.5 (SDA), U310.15 (RC4)
/Logic/TXD: J307.3, U307.13 (R1IN)
/Logic/USB_RX: U310.24 (RB3), U311.5 (RXD)
/Logic/USB_TX: U310.23 (RB2), U311.1 (TXD)
/Logic/VCO: J305.2, TP302.1; also elsewhere on the board
/Logic/VRef: J314.2; also elsewhere on the board
/Logic/VRef_FB: J303.1, U302.2 (-), U302.6, U310.2 (RA0)
/Logic/~ENTER: J302.5, U310.18 (RC7)
/Logic/~MCLR: J312.1, U310.1 (~MCLR)
/Logic/~RESET: U308.18 (~RESET), U310.13 (RC2)
GND: BT301.2 (-), C302.2, C304.2, C307.1, C309.2, C310.2, C311.2, C312.2, C313.2, D302.2 (A), D304.2 (A), J302.6, J304.2, J306.1, J307.5, J308.2 (Ext), J309.2 (Ext), J310.2 (Ext), J311.2, J312.3, J313.4, J313.5, Q301.1 (E), R302.1, R303.1, R309.1, R321.2, RV301.1, U301.5 (A0), U301.8 (GND), U304.2 (GND), U305.3 (GND), U306.3 (GND), U307.8 (R2IN), U307.10 (T2IN), U307.15 (GND), U308.10 (VSS), U308.15 (A0), U308.16 (A1), U308.17 (A2), U309.4 (Gnd), U309.7 (WP), U310.8 (Vss), U310.19 (Vss), U311.7 (GND), U311.18 (GND), U311.21 (GND), U311.25 (AGND), U311.26 (TEST); also elsewhere on the board
unnamed: BT301.1 (+), D310.2 (A)
unnamed: C301.1, U304.1
unnamed: C303.1, R308.1
unnamed: C303.2, L301.2, U304.3
unnamed: D301.2 (A), D302.1 (K), FB301.1, U305.4
unnamed: D303.2 (A), D304.1 (K), FB302.1, U306.4
unnamed: D305.1 (K), R313.1
unnamed: D306.1 (K), R314.1
unnamed: D307.1 (K), R315.1
unnamed: D308.1 (K), R316.1
unnamed: D309.1 (K), R317.1
unnamed: D310.1 (K), D311.1 (K), U309.8 (Vcc)
unnamed: D312.1 (K), R318.1
unnamed: D313.1 (K), R319.1
unnamed: F301.1, R310.2
unnamed: F302.1, R311.2
unnamed: FB301.2, R310.1
unnamed: FB302.2, R311.1
unnamed: J303.2, TP301.1, U301.2 (V_{REF})
unnamed: J305.1, U301.3 (V_{SENSE}), U301.4 (V_{OUT}), U303.3 (+)
unnamed: J305.3, R304.1, U303.6
unnamed: J306.3, RV301.2
unnamed: J306.14, R305.1
unnamed: J307.4, J307.6
unnamed: J307.7, J307.8
unnamed: J308.1 (In), R312.2
unnamed: F301.2, J309.1 (In)
unnamed: F302.2, J310.1 (In)
unnamed: J313.1, R320.1
unnamed: J313.2, U311.16 (USBD-)
unnamed: J313.3, U311.15 (USBD+)
unnamed: J314.1, R301.1, R302.2, U302.3 (+)
unnamed: J314.3, R301.2
unnamed: JP301.1 (A), U307.11 (T1IN)
unnamed: JP302.1 (A), U307.12 (R1OUT)
unnamed: L301.1, R306.2
unnamed: Q301.2 (B), R307.1
unnamed: Q301.3 (C), R305.2
unnamed: R308.2, R309.2, R312.1
unnamed: R303.2, R304.2, U303.2 (-)
unnamed: C305.1, U307.4 (C2+)
unnamed: C305.2, U307.5 (C2-)
unnamed: TP305.1, U310.10 (RA6)
unnamed: C313.1, U311.17 (3V3OUT)
unnamed: R318.2, U311.23 (CBUS0)
unnamed: R319.2, U311.22 (CBUS1)
unnamed: R320.2, R321.1, U311.19 (~RESET)

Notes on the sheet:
USB RX
GPS
4X20 LCD With Backlight
Div by 1 Div by 2
Install jumper to enable Bootloader and to download new software over external USB link. Remove jumper for programming.
Vcc Gnd TxD RxD PPS
X1 X2
Internal OCXO
Red (+5) White (D-) Green (D+) Black (Gnd) Shield (Opt)
Lock
Pins 4 and 8 are polarizing pins
Vss Vcc Vref NC RS R/~{W} E NC DB4 DB5 DB6 DB7 BL_A BL_K
Used if the Neo-M8M is integrated on-board and not using a plug-in module.
USB TX
Pin 9 is polarizing pin
Wire straight pin-to-pin to DB-9 connector except pin 9 which is connected to pin 10 of the board
Power
Fault
Front Panel Encoder W/Switch
Power - On when the system is operational Lock - OCXO RF is in phase/locked with GPS Holdover - GPS signal is lost and OCXO is free-running GPS - The GPS receiver has a 3D lock. Fault - On if any error condition is detected.
Attenuator/Buffer
Polarizing pin
VCO Generator
GPS Module (alternate)
Holdover

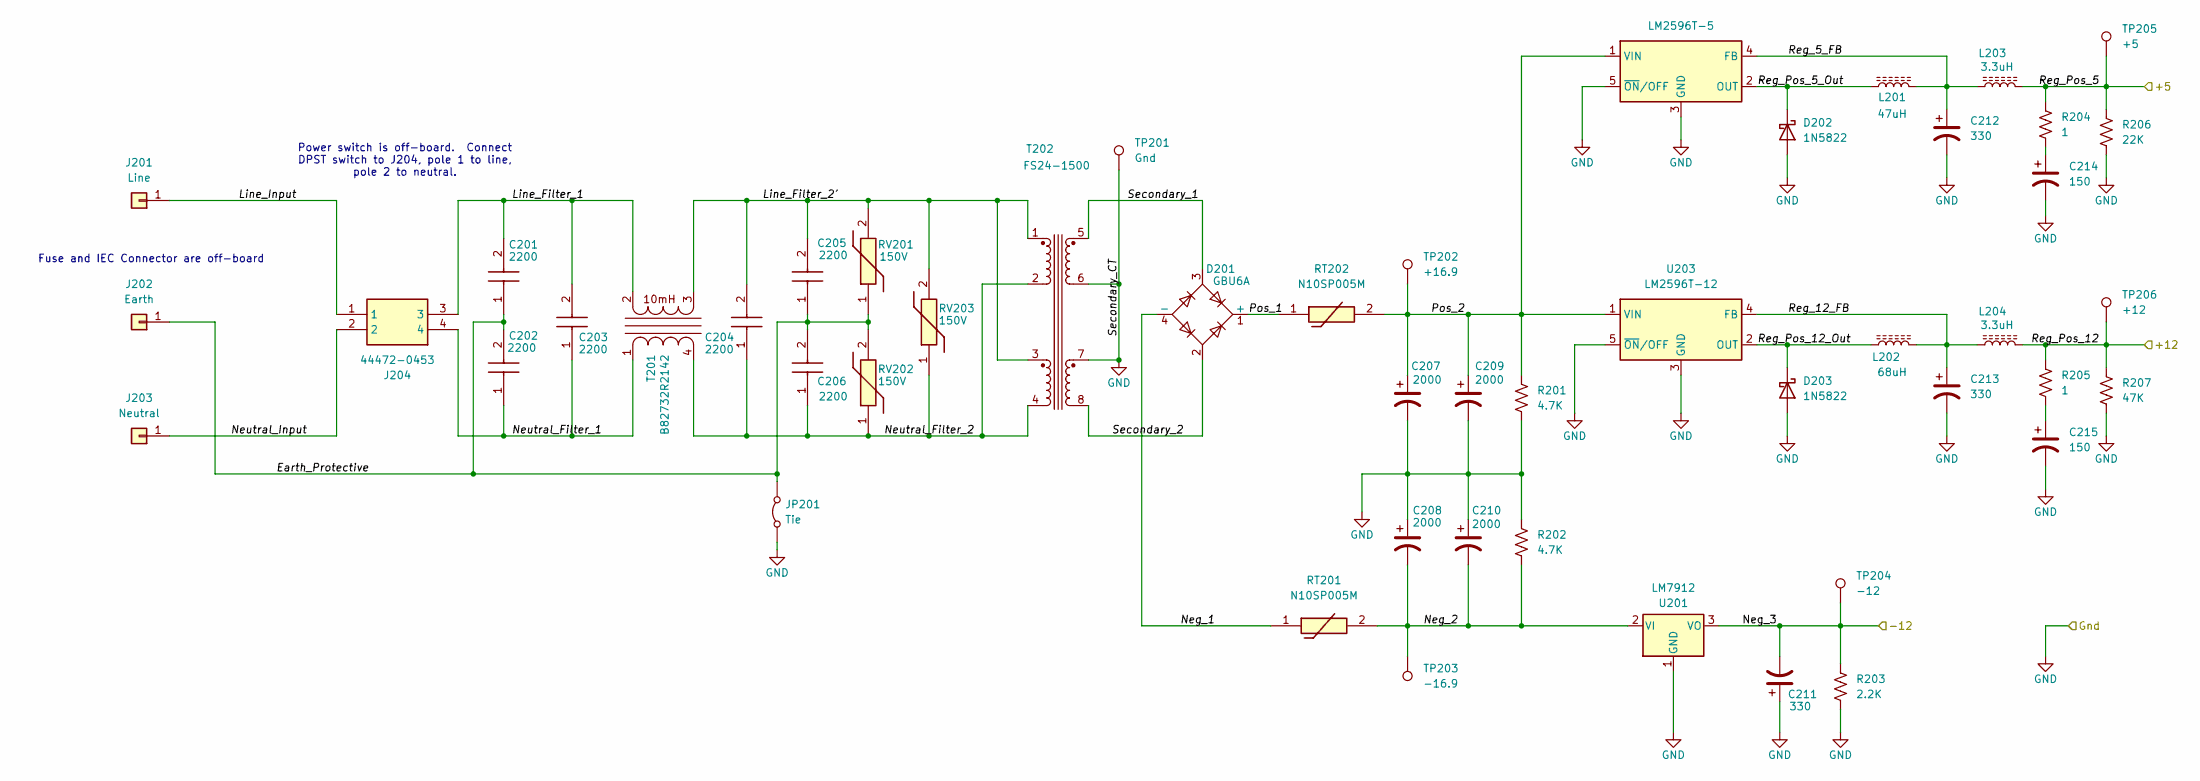
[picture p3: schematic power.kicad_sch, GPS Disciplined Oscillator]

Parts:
C201, C202, C203, C204, C205, C206: 2200; C731U222MSVDBAWL35; Mouser Part Number 80-C731U222MSVDBWL35
C207, C208, C209, C210: 2000; CP_Elec_18x22
C211, C212, C213: 330; CP_Elec_10x10.5
C214, C215: 150; CP_Elec_10x10
D201: GBU6A; Diode_Bridge_Vishay_GBU
D202, D203: 1N5822; D_SOD-128
J201: Line; Amp Faston 250 THT
J202: Earth; Amp Faston 250 THT
J203: Neutral; Amp Faston 250 THT
J204: 44472-0453; 44472-04YY; Mouser Part Number 538-44472-0453
JP201: Tie; SolderJumper-2_P1.3mm_Bridged_RoundedPad1.0x1.5mm
L201: 47uH; Bourns PM5022
L202: 68uH; Bourns PM5022
L203, L204: 3.3uH; Bourns SDE04030
R201, R202: 4.7K; R_0805_2012Metric_Pad1.20x1.40mm_HandSolder
R203: 2.2K; R_0805_2012Metric_Pad1.20x1.40mm_HandSolder
R204, R205: 1; R_0805_2012Metric_Pad1.20x1.40mm_HandSolder
R206: 22K; R_0805_2012Metric_Pad1.20x1.40mm_HandSolder
R207: 47K; R_0805_2012Metric_Pad1.20x1.40mm_HandSolder
RT201, RT202: N10SP005M; Mouser Part Number 603-N10SP005M
RV201, RV202, RV203: 150V; MOV20D241KKTR; Mouser Part Number 652-MOV-20D241KKTR
T201: B82732R2142; TDK B82732R Series
T202: FS24-1500; FS-36VA
TP201: Gnd; TestPoint_Bridge_Pitch2.54mm_Drill1.0mm
TP202: +16.9; TestPoint_Bridge_Pitch2.54mm_Drill1.0mm
TP203: -16.9; TestPoint_Bridge_Pitch2.54mm_Drill1.0mm
TP204: -12; TestPoint_Bridge_Pitch2.54mm_Drill1.0mm
TP205: +5; TestPoint_Bridge_Pitch2.54mm_Drill1.0mm
TP206: +12; TestPoint_Bridge_Pitch2.54mm_Drill1.0mm
U201: LM7912; TO-220-3_Vertical
U202: LM2596T-5; TO-220-5_P3.4x3.7mm_StaggerOdd_Lead3.8mm_Vertical
U203: LM2596T-12; TO-220-5_P3.4x3.7mm_StaggerOdd_Lead3.8mm_Vertical

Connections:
+5V: L203.2, R204.1, R206.1, TP205.1; also elsewhere on the board
+12V: L204.2, R205.1, R207.1, TP206.1; also elsewhere on the board
-12V: C211.2, R203.1, TP204.1, U201.3 (VO); also elsewhere on the board
/Power Supply/Earth_Protective: C201.1, C202.2, C205.1, C206.2, J202.1, JP201.2 (B), RV201.1, RV202.2
/Power Supply/Line_Filter_1: C201.2, C203.2, J204.3, T201.2
/Power Supply/Line_Filter_2': C204.2, C205.2, RV201.2, RV203.2, T201.3, T202.1, T202.3
/Power Supply/Line_Input: J201.1, J204.1
/Power Supply/Neg_1: D201.4 (-), RT201.1
/Power Supply/Neg_2: C208.2, C210.2, R202.2, RT201.2, TP203.1, U201.2 (VI)
/Power Supply/Neutral_Filter_1: C202.1, C203.1, J204.4, T201.1
/Power Supply/Neutral_Filter_2: C204.1, C206.1, RV202.1, RV203.1, T201.4, T202.2, T202.4
/Power Supply/Neutral_Input: J203.1, J204.2
/Power Supply/Pos_1: D201.1 (+), RT202.1
/Power Supply/Pos_2: C207.1, C209.1, R201.1, RT202.2, TP202.1, U202.1 (VIN), U203.1 (VIN)
/Power Supply/Reg_5_FB: C212.1, L201.2, L203.1, U202.4 (FB)
/Power Supply/Reg_12_FB: C213.1, L202.2, L204.1, U203.4 (FB)
/Power Supply/Reg_Pos_5_Out: D202.1 (K), L201.1, U202.2 (OUT)
/Power Supply/Reg_Pos_12_Out: D203.1 (K), L202.1, U203.2 (OUT)
/Power Supply/Secondary_1: D201.3, T202.5
/Power Supply/Secondary_2: D201.2, T202.8
GND: C207.2, C208.1, C209.2, C210.1, C211.1, C212.2, C213.2, C214.2, C215.2, D202.2 (A), D203.2 (A), JP201.1 (A), R201.2, R202.1, R203.2, R206.2, R207.2, T202.6, T202.7, TP201.1, U201.1 (GND), U202.3 (GND), U202.5 (~ON/OFF), U203.3 (GND), U203.5 (~ON/OFF); also elsewhere on the board
unnamed: C214.1, R204.2
unnamed: C215.1, R205.2

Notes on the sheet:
Power switch is off-board. Connect DPST switch to J204, pole 1 to line, pole 2 to neutral.
Fuse and IEC Connector are off-board

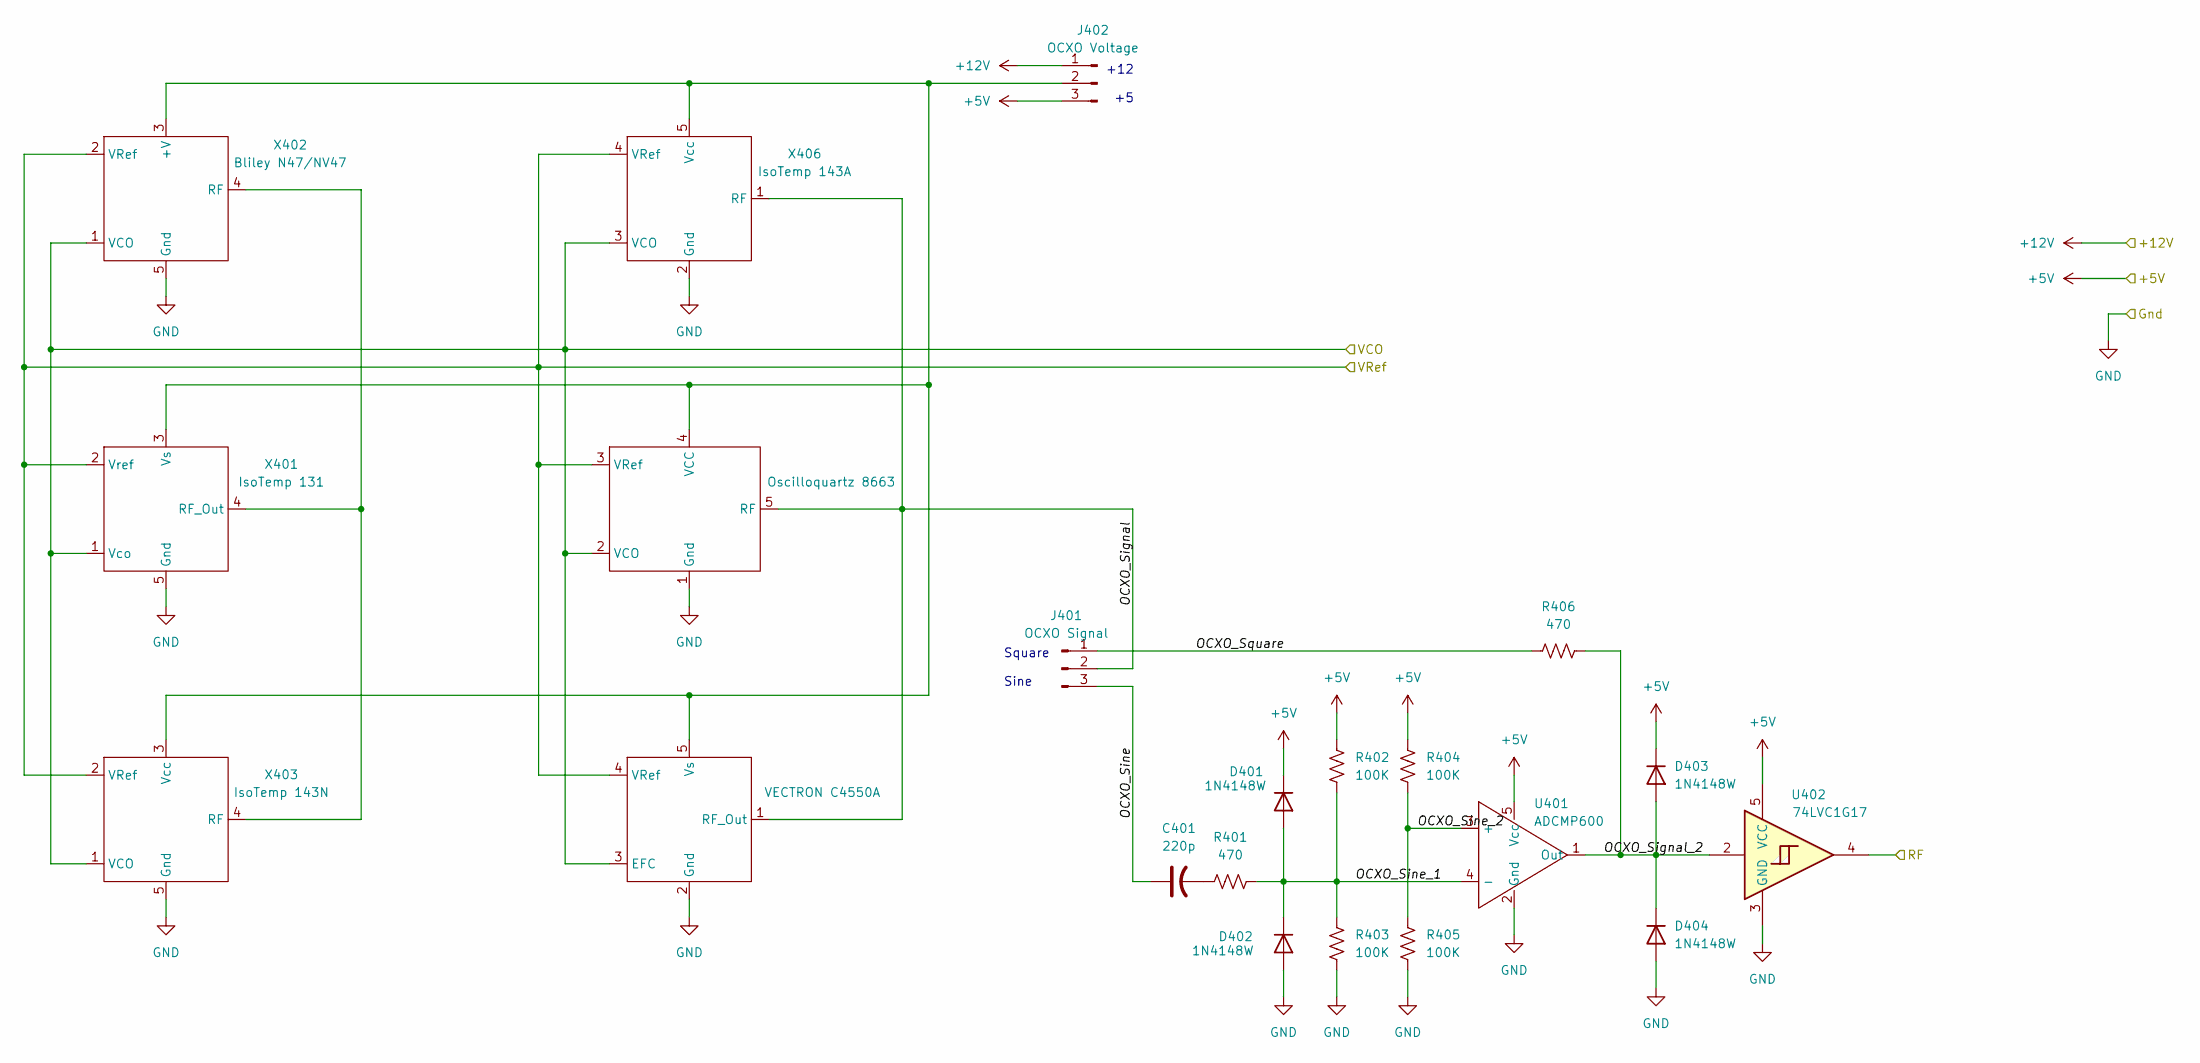
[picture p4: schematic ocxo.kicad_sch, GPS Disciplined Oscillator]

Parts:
C401: 220p; C_0603_1608Metric_Pad1.08x0.95mm_HandSolder
D401, D402, D403, D404: 1N4148W; D_SOD-323_HandSoldering
J401: OCXO Signal; PinHeader_1x03_P2.54mm_Vertical
J402: OCXO Voltage; PinHeader_1x03_P2.54mm_Vertical
R401, R406: 470; R_0805_2012Metric_Pad1.20x1.40mm_HandSolder
R402, R403, R404, R405: 100K; R_0805_2012Metric_Pad1.20x1.40mm_HandSolder
U401: ADCMP600; SOT-23-5
U402: 74LVC1G17; SOT-353_SC-70-5
X401: IsoTemp 131; ISOTEMP 131
X402: Bliley N47/NV47; Bliley N47
X403: IsoTemp 143N; ISOTEMP 143N
X404: VECTRON C4550A; VectronC4550-A
X405: Oscilloquartz 8663; OQ8663
X406: IsoTemp 143A; ISOTEMP 143A

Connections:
+5V: D401.1 (K), D403.1 (K), J402.3, R402.2, R404.2, U401.5 (Vcc), U402.5 (VCC); also elsewhere on the board
+12V: J402.1; also elsewhere on the board
/Logic/RF: U402.4; also elsewhere on the board
/Logic/VCO: X401.1 (Vco), X402.1 (VCO), X403.1 (VCO), X404.3 (EFC), X405.2 (VCO), X406.3 (VCO); also elsewhere on the board
/Logic/VRef: X401.2 (Vref), X402.2 (VRef), X403.2 (VRef), X404.4 (VRef), X405.3 (VRef), X406.4 (VRef); also elsewhere on the board
/OCXO/OCXO_Signal: J401.2, X404.1 (RF_Out), X405.5 (RF), X406.1 (RF)
/OCXO/OCXO_Signal_2: D403.2 (A), D404.1 (K), R406.2, U401.1 (Out), U402.2
/OCXO/OCXO_Sine: C401.1, J401.3
/OCXO/OCXO_Sine_1: D401.2 (A), D402.1 (K), R401.2, R402.1, R403.2, U401.4 (-)
/OCXO/OCXO_Sine_2: R404.1, R405.2, U401.3 (+)
/OCXO/OCXO_Square: J401.1, R406.1
GND: D402.2 (A), D404.2 (A), R403.1, R405.1, U401.2 (Gnd), U402.3 (GND), X401.5 (Gnd), X402.5 (Gnd), X403.5 (Gnd), X404.2 (Gnd), X405.1 (Gnd), X406.2 (Gnd); also elsewhere on the board
unnamed: C401.2, R401.1
unnamed: J402.2, X401.3 (Vs), X402.3 (+V), X403.3 (Vcc), X404.5 (Vs), X405.4 (VCC), X406.5 (Vcc)
unnamed: X401.4 (RF_Out), X402.4 (RF), X403.4 (RF)

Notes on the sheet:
+12 +5
Square Sine

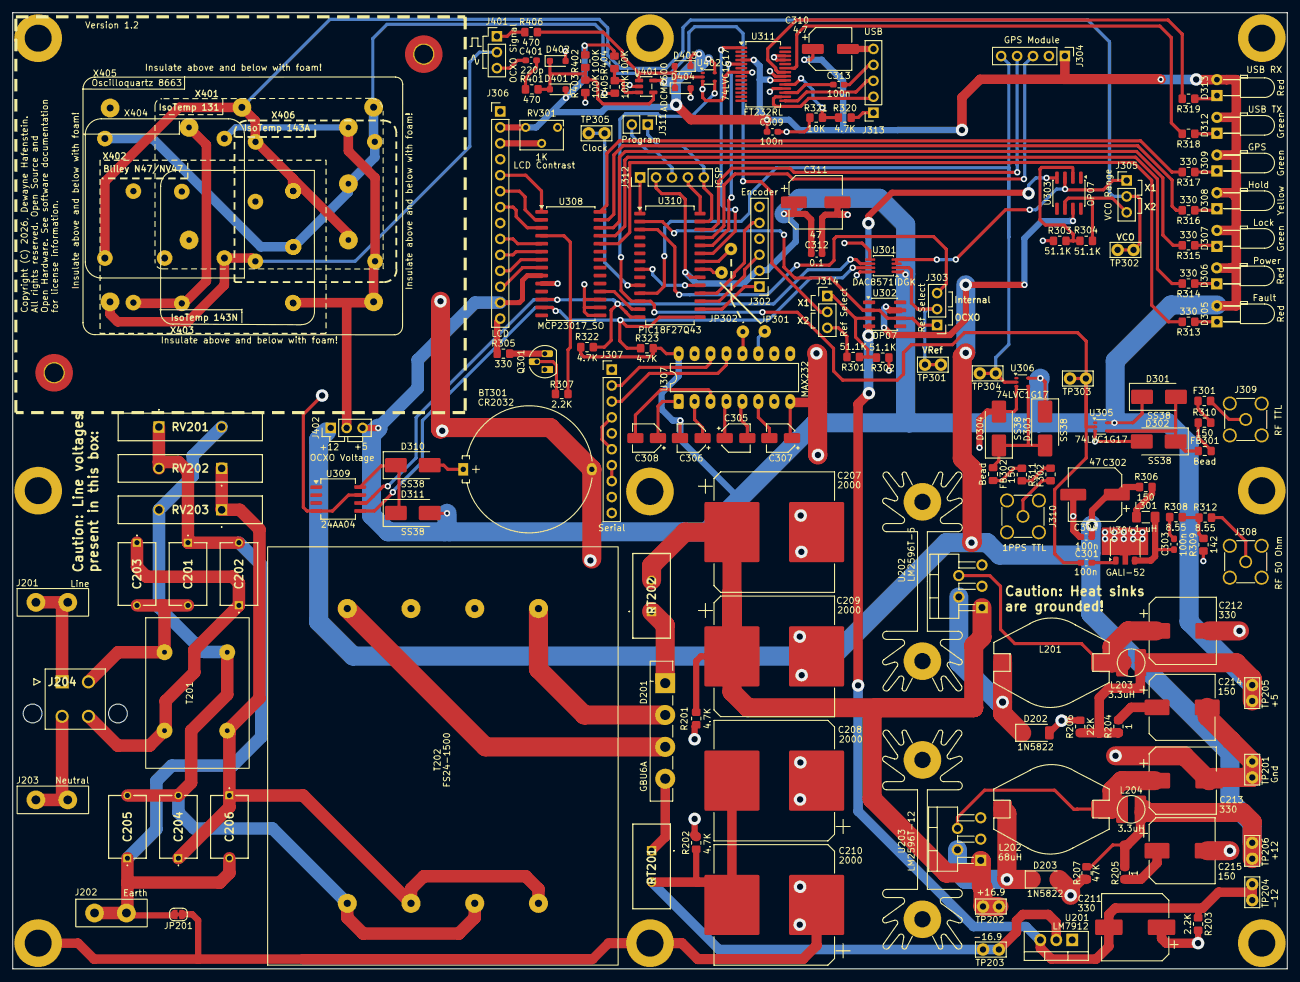
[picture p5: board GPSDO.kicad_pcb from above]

Board: 2 copper layers, 203.2 x 152.4 mm, 157 parts (0 on the bottom side), 115 nets.

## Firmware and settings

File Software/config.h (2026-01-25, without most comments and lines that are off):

#define CONFIG_H
#include "encoder.h"
#include <stdbool.h>
#include <stdint.h>
#include <xc.h>
#define CRITICAL_SECTION_ENTER(gie_saved, giel_saved)                                                                  \
    do {                                                                                                               \
        (gie_saved) = INTCON0bits.GIEH;                                                                                \
        (giel_saved) = INTCON0bits.GIEL;                                                                               \
        INTCON0bits.GIEH = 0;                                                                                          \
        INTCON0bits.GIEL = 0;                                                                                          \
    } while (0)
#define CRITICAL_SECTION_EXIT(gie_saved, giel_saved)                                                                   \
    do {                                                                                                               \
        INTCON0bits.GIEH = (gie_saved);                                                                                \
        INTCON0bits.GIEL = (giel_saved);                                                                               \
    } while (0)
#define _XTAL_FREQ 64000000L
#define MCP23X17_BANKED
#pragma config FEXTOSC = OFF            // Dont use the external oscillator
#pragma config RSTOSC = HFINTOSC_64MHZ  // Use internal 64MHz high frequency osc
#pragma config CSWEN = OFF              // No clock switching allowed
#pragma config FCMEN = OFF              // Fail-safe clock monitor is disabled
#pragma config PR1WAY = 0               // PRLOCKED Set/Cleared repeatedly
#pragma config CLKOUTEN = 0             // Clock out is enabled on RA6
#pragma config BOREN = 3                // Brown-out reset is enabled
#pragma config LPBOREN = OFF            // Low power brown-out reset is disabled
#pragma config IVT1WAY = 0              // IVTLOCK Set/cleared repeatedly
#pragma config MVECEN = 1               // Vectored interrupts enabled
#pragma config PWRTS = 2                // Power up timer at 64mS
#pragma config MCLRE = 1                // Master clear retains that function
#pragma config XINST = OFF              // No extended instruction set
#pragma config LVP = 1                  // Low voltage programming is enabled
#pragma config STVREN = ON              // Stack over/under flow causes reset
#pragma config PPS1WAY = 0              // PPSLOCK set/reset repeatedly
#pragma config ZCD = 1                  // Zero-cross detection is disabled
#pragma config BORV = 0                 // Brown-out voltage is set to 2.85V
#pragma config WDTE = OFF               // No watch dog timer
#pragma config SAFEN = OFF              // Storage area flash is disabled
#pragma config BBEN = OFF               // Boot block is disabled
#pragma config WRTAPP = OFF             // Application block is NOT write protected
#pragma config WRTSAF = OFF             // SAF area is not write protected
#pragma config WRTC = OFF               // Configuration registers are NOT write protected
#pragma config WRTB = OFF               // Boot block is not write protected
#pragma config WRTD = OFF               // Data EEPROM is not write protected
#pragma config CP = OFF                 // Code is not protected
#define MCP23017_ADDRESS 0x20           // I/O Expander address (x'40')
#define EEPROM_ADDRESS 0x50             // EEPROM address (x'A0')
#define DAC8571_ADDRESS 0x4C            // DAC address (x'98')
#define DAC_RESOLUTION 65535            // 16-bit
#define DAC_MIDPOINT (DAC_RESOLUTION / 2)
#define CONFIG_MAGIC 0xA5               // Magic number to identify valid config
#define CONFIG_VERSION 0x02             // Configuration structure version
#define EEPROM_PAGE_SIZE 16             // EEPROM page size for writes
typedef enum {
    VREF_SRC_INTERNAL = 0,              // Internal reference
    VREF_SRC_EXTERNAL = 1               // External reference
} vref_source_t;
typedef enum {
    GPS_PROTOCOL_NMEA = 0,              // NMEA protocol
    GPS_PROTOCOL_UBX = 1,               // UBX protocol
    GPS_PROTOCOL_RTCM = 2               // RTCM protocol
} gps_protocol_t;
typedef enum {
    GPS_INVALID = 0,
    GPS_VALID = 1
} gps_validity_t;
typedef enum {
    GPS_NO_FIX = 0,
    GPS_2D_FIX = 1,
    GPS_3D_FIX = 2
} gps_fix_t;
typedef struct {
    unsigned char year;                         // Years since 2000 (e.g., 25 for 2025)
    unsigned char month;                        // Month 1-12
    unsigned char day;                          // Day 1-31
    unsigned char hour;                         // Hour 0-23 (UTC)
    unsigned char minute;                       // Minute 0-59
    unsigned char second;                       // Second 0-59
    gps_validity_t valid;
} gps_datetime_t;
typedef struct {
    float latitude;                             // Decimal degrees, positive = North
    float longitude;                            // Decimal degrees, positive = East
    float altitude;                             // Meters above sea level
    gps_fix_t fix_type;                         // Fix type (none, 2D, 3D)
    unsigned char satellites;                   // Number of satellites in view
    gps_validity_t valid;                       // Position validity
} gps_position_t;
typedef enum {
    TZ_MODE_UTC = 0,                            // UTC timezone mode
    TZ_MODE_LOCAL = 1                           // Local timezone mode
} tz_mode_t;
typedef enum {
    PARITY_NONE = 0,                            // No parity
    PARITY_EVEN = 1,                            // Even parity
    PARITY_ODD = 2,                             // Odd parity
    PARITY_MARK = 3,                            // Mark parity
    PARITY_SPACE = 4                            // Space parity
} parity_t;
typedef enum {
    STOPBITS_1 = 0,                             // 1 stop bit
    STOPBITS_1_5 = 1,                           // 1.5 stop bits
    STOPBITS_2 = 2                              // 2 stop bits
} stopbits_t;
typedef struct {
    unsigned char magic;                        // should be CONFIG_MAGIC
    unsigned char version;                      // should be CONFIG_VERSION
    vref_source_t vref_source;                  // The VRef source selection
    long gps_baud;                              // GPS baud rate
    stopbits_t gps_stop_bits;                   // 0, 1.5, or 2
    parity_t gps_parity;                        // GPS Parity
    gps_protocol_t gps_protocol;                // gps_protocol_t
    unsigned int vco_dac;                       // stored VCO DAC raw value (0..4095)
    long ext_baud;                              // ext Baud rate
    stopbits_t ext_stop_bits;                   // ext stop bits 0, 1.5, or 2
    parity_t ext_parity;                        // ext parity
    tz_mode_t tz_mode;                          // Timezone mode
    int tz_offset_min;                          // signed minutes offset from UTC (e.g., -300 = UTC-05:00)
    unsigned char reserved[6];                  // padding to make structure 32 bytes (multiple of EEPROM_PAGE_SIZE)
    unsigned int crc;                           // CRC-16 of all preceding bytes
} system_config_t;
extern system_config_t system_config;
#define VREF_FB 1                               // RA0: VREF feedback pin
#define INT_REF 2                               // RA1: Internal reference output pin
#define CLOCK_OUT 64                            // RA6: Clock output pin
#define EXT_TX 1                                // RB0: External TX output
#define EXT_RX 2                                // RB1: External RX input
#define USB_TX 4                                // RB2: USB interface transmit pin
#define USB_RX 8                                // RB3: USB interface receive pin
#define GPS_TX 16                               // RB4: GPS Transmit pin
#define GPS_RX 32                               // RB5: GPS Receive pin
#define PROGRAM_N 64                            // RB6: Program mode select (active LOW)
#define PPS 1                                   // RC0: 1PPS signal from GPS module
#define RF 2                                    // RC1: RF From OCXO
#define RESET_N 4                               // RC2: Active low reset for io expander
#define SCL 8                                   // RC3: I2C Clock
#define SDA 16                                  // RC4: I2C Data
#define PHASE_A 32                              // RC5: Phase A input from encoder
#define PHASE_B 64                              // RC6: Phase B input from encoder
#define ENTER_N 128                             // RC7: Active low enter button
typedef union {
    struct {
        unsigned char LCD_RS : 1;               // LCD Register Select pin
        unsigned char LCD_RW : 1;               // LCD Read/Write pin
        unsigned char LCD_E : 1;                // LCD Enable pin
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

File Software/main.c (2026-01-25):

/*
 * Copyright (c) 2026, Dewayne L. Hafenstein.  All rights reserved.
 *
 * Main program loop for the GPSDO (GPS Disciplined Oscillator) project.
 * The program initializes the system, performs a self-check by cycling the
 * LEDs connected to the I/O expander, and then enters an infinite loop
 * where it continually processes inputs from either the rotary encoder
 * (to set or view system configuration or properties), or from the GPS module
 * (to discipline the local oscillator). The program uses I2C communication
 * to interface with the I/O expander for front panel controls and indicators.
 * The program uses the LCD display to show system status and configuration,
 * the DAC to control the VCO (Voltage Controlled Oscillator) to control the
 * frequency of the local oscillator, the SMT (Synchronous Modulation Tracking)
 * algorithm to discipline the local oscillator to the GPS signal.
 *
 * System configuration and properties are managed through the LCD display
 * and the rotary encoder, and persisted in the EEPROM.
 *
 * The system uses several LED indicators on the front panel.  These include:
 * - POWER_N: Power on LED (active low)
 * - GPS_N: Indicates GPS signal lock (active low)
 * - HOLDOVER_N: Indicates holdover status (active low) (meaning the GPS signal is not available
 * - LOCK_N: Lock status LED (active low).  Indicates that the OCXO is locked to the GPS signal.
 *
 * Licensed under the Apache License, Version 2.0 (the "License");
 * you may not use this file except in compliance with the License.
 * You may obtain a copy of the License at
 *
 *    http://www.apache.org/licenses/LICENSE-2.0
 *
 * Unless required by applicable law or agreed to in writing, software
 * distributed under the License is distributed on an "AS IS" BASIS,
 * WITHOUT WARRANTIES OR CONDITIONS OF ANY KIND, either express or implied.
 * See the License for the specific language governing permissions and
 * limitations under the License.
 *
 */

#include "config.h"
#include "control.h"
#include "dac.h"
#include "date.h"
#include "encoder.h"
#include "gps.h"
#include "i2c.h"
#include "isr.h"
#include "lcd.h"
#include "led.h"
#include "mcp23x17.h"
#include "menu.h"
#include "serial.h"
#include "smt.h"
#include <stdbool.h>
#include <stdio.h>
#include <xc.h>

/*
 * Function prototypes
 */
void selfCheck(void);
void updateDisplay(void);

/*
 * Global variables and data areas.
 */
extern system_config_t system_config;
extern shadowA_t shadowA;
extern unsigned char buffer[128];
extern volatile encoder_state_t encoder_state;
extern bool system_initialized;
extern volatile bool gps_sentence_available;

/************************************************************************
 * Main program loop
 *
 * This is the main program code for the GPSDO (GPS Disciplined Oscillator)
 * project. It initializes the system, performs a self-check by cycling the
 * LEDs connected to the I/O expander, and then enters an infinite processing
 * loop.
 *
 * This processing loop continuously polls the rotary encoder, processes menu inputs,
 * and updates LCD display. This is to make sure that the user interface remains
 * responsive under all conditions.
 *
 * The SMT (Signal Measurement Timer) processing is only performed when a new
 * capture is available, ensuring that the frequency discipline logic is executed
 * in a timely manner without blocking the UI updates.  This capture occurs each
 * time the SMT module window event triggers, indicating a new frequency
 * measurement is available.  This is triggered by the 1PPS signal from the GPS
 * module.
 *
 * During the SMT capture processing, the program updates the DAC to adjust the VCO
 * frequency based on the measured error from the GPS signal. It also updates the
 * LCD display with the latest frequency measurement and manages the LOCK LED status.
 * If the system is locked to the GPS signal, it persists the current DAC setting
 * to EEPROM to maintain the frequency control across power cycles IF the setting
 * has changed.
 *
 * Also during the SMT capture processing, the program transmits the latest GPS data
 * over the serial interface for external monitoring or logging (about once per second).
 * This information includes the current date, time, and position as reported by the
 * GPS module.  The date and time are also displayed on the LCD.
 *
 * The user has the option to display the date/time in UTC or local time based on
 * their configuration settings.
 *
 ************************************************************************/
void main(int argc, char** argv) {

    // Initialize the system
    initialize();
    updateDisplay();

    /**
     * Main processing loop.
     */
    while (1) {
        menu_process();

        // Only process GPS data when complete sentences are available
        if (gps_sentence_available) {
            gps_parse_sentence();
        }

        /*
         * Only perform SMT-based control processing when a new capture has
         * been recorded by the SMT ISR. Clear the capture flag after handling.
         */
        if (smt_capture_available()) {
            unsigned long c = smt_get_last_count();
            long err = smt_get_last_error();
            control_update(err);

            // Send debug data over serial
            printf("[PRINTF] Count: %lu, Error: %ld, DAC: %d\r\n", (unsigned long)c, (long)err, (int)dac_get_raw());

            // Format and set frequency line using printf-style formatting
            lcdBufferPrintf(3, "Freq:%lu", (unsigned long)c);

            // Update LOCK LED if error is within +/-1 (active low)
            int locked = (err >= -1 && err <= 1) ? 1 : 0;

            /*
             * If locked, persist the current DAC setting to EEPROM (only if it differs)
             * We avoid repeated writes by checking the stored config value first.
             */
            if (locked) {
                lockLED_On();
                unsigned int cur = dac_get_raw();
                if (system_config.vco_dac != cur) {
                    system_config.vco_dac = cur;
                    config_save((const system_config_t*)&system_config);
                }
            } else {
                lockLED_Off();
            }

            /* Mark this capture as handled */
            smt_clear_capture();
        } else {
            /* If no new capture, indicate waiting on line 3 */
            lcdBufferSetLine(3, "Freq: waiting...");
        }
        updateDisplay();
    }

    return;
}

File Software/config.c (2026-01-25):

/*
 * Copyright (c) 2026, Dewayne L. Hafenstein.  All rights reserved.
 *
 * This module contains the system initialization code for the GPSDO project.
 * It sets up the microcontroller's I/O ports, interrupt system, and peripheral
 * modules required for operation.  It is called once at system startup from
 * main().
 *
 * Licensed under the Apache License, Version 2.0 (the "License");
 *
 * you may not use this file except in compliance with the License.
 * You may obtain a copy of the License at
 *   http://www.apache.org/licenses/LICENSE-2.0
 * Unless required by applicable law or agreed to in writing, software
 * distributed under the License is distributed on an "AS IS" BASIS,
 * WITHOUT WARRANTIES OR CONDITIONS OF ANY KIND, either express or implied.
 * See the License for the specific language governing permissions and
 * limitations under the License.
 */
#include "config.h"
#include "control.h"
#include "dac.h"
#include "encoder.h"
#include "faults.h"
#include "gps.h"
#include "i2c.h"
#include "lcd.h"
#include "led.h"
#include "mcp23x17.h"
#include "menu.h"
#include "serial.h"
#include "smt.h"
#include "usb.h"
#include <string.h>
#include <xc.h>

/**
 * Global variables and data areas.
 */
bool system_initialized = false;           // Flag indicating system initialization complete
unsigned char i2c_buffer[I2C_BUFFER_SIZE]; // General-purpose I2C buffer
shadowA_t shadowA = {.all = 0xF8};         // I/O expander Port A state shadow register
shadowB_t shadowB = {.all = 0x00};         // I/O expander Port B state shadow register
system_config_t system_config;             // System configuration data
volatile encoder_state_t encoder_state = {
    .position = 0, .last_state = 0, .button_raw = 1, .button_stable = 0, .debounce_cnt = 0}; // Rotary encoder state
extern volatile gps_data_t gps_data;     // Global GPS data (defined in gps.c)
extern volatile bool gps_data_available; // Flag for new GPS data available (defined in gps.c)

/*
 * forward definitions
 */
static void selfCheck(void);

/****************************************************************************/
/*                                                                          */
/* Initialize the system                                                    */
/*                                                                          */
/****************************************************************************/
void initialize(void) {
    system_initialized = false;

    /*
     * Disable interrupts
     */
    INTCON0bits.GIEH = 0; // Turn off high priority interrupts
    INTCON0bits.GIEL = 0; // And low priority interrupts too

    /*
     * Clear all interrupt enables
     */
    PIE0 = 0x00;
    PIE2 = 0x00;
    PIE3 = 0x00;
    PIE4 = 0x00;
    PIE5 = 0x00;
    PIE6 = 0x00;
    PIE7 = 0x00;
    PIE8 = 0x00;
    PIE9 = 0x00;
    PIE10 = 0x00;
    PIE11 = 0x00;
    PIE12 = 0x00;
    PIE13 = 0x00;
    PIE14 = 0x00;
    PIE15 = 0x00;

    /*
     * Clear all interrupt requests
     */
    PIR0 = 0x00;
    PIR1 = 0x00;
    PIR2 = 0x00;
    PIR3 = 0x00;
    PIR4 = 0x00;
    PIR5 = 0x00;
    PIR6 = 0x00;
    PIR7 = 0x00;
    PIR8 = 0x00;
    PIR9 = 0x00;
    PIR10 = 0x00;
    PIR11 = 0x00;
    PIR12 = 0x00;
    PIR13 = 0x00;
    PIR14 = 0x00;
    PIR15 = 0x00;

    /*
     * Disable all peripheral modules until after PPS mapping and I/O setup is done,
     * then selectively enable the required modules to save power.
     */
    PMD0 = 0xFF;
    PMD1 = 0xFF;
    PMD3 = 0xFF;
    PMD4 = 0xFF;
    PMD5 = 0xFF;
    PMD6 = 0xFF;
    PMD7 = 0xFF;
    PMD8 = 0xFF;

    // Set up port A
    //
    // All port A pins (except RA6) are used as analog inputs and
    // outputs and are used to sample the VRef level and to supply
    // a default VRef if the OCXO does not. RA6 is configured as a
    // digital output and outputs the system clock for diagnostic
    // purposes.
    //
    // RA0 - VRef Feedback
    // RA1 - Internal VRef output
    // RA2 - MFINTOSC output for debugging (500kHz clock)
    // RA3 - Unused
    // RA4 - Unused
    // RA5 - Unused
    // RA6 - Digital clock output
    // RA7 - Unused
    TRISA = 0xFF - VREF_FB - INT_REF - CLOCK_OUT; // RA0,RA1,RA6 as outputs
    ANSELA = 0xFF - VREF_FB - INT_REF;            // RA0,RA1 as analog inputs, RA6 digital
    LATA = 0x00;
    ODCONA = 0x00;
    WPUA = 0x00;
    SLRCONA = 0x00;
    INLVLA = 0x00;
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

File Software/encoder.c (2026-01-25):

/*
 * Copyright (c) 2026, Dewayne L. Hafenstein.  All rights reserved.
 *
 * Simple rotary encoder handler.
 * - RC5 = Phase A
 * - RC6 = Phase B
 * - RC7 = Switch (active low, pulled to ground when closed)
 *
 * This implementation enables weak pull-ups on RC5/6/7, processes the pin changes
 * as part of an interrup-on-change (IOC) service routine, and updates a signed
 * 8-bit position counter. Button debouncing is handled externally.

 * Licensed under the Apache License, Version 2.0 (the "License");
 * you may not use this file except in compliance with the License.
 * You may obtain a copy of the License at
 *  http://www.apache.org/licenses/LICENSE-2.0
 * Unless required by applicable law or agreed to in writing, software
 * distributed under the License is distributed on an "AS IS" BASIS,
 * WITHOUT WARRANTIES OR CONDITIONS OF ANY KIND, either express or implied.
 * See the License for the specific language governing permissions and
 * limitations under the License.
 *
 */
#include "encoder.h"
#include "config.h"
#include <stdint.h>
#include <xc.h>
/* encoder_state is defined centrally in config.c */

/*
 * Initialize the encoder hardware and state.
 */
void encoder_init(void) {
    // Ensure pins are inputs
    TRISC |= PHASE_A + PHASE_B + ENTER_N; // RC5, RC6, RC7

    // Enable weak pull-ups for RC5..RC7 (bits 5,6,7)
    WPUC |= PHASE_A + PHASE_B + ENTER_N;

    // Configure IOC for both edges on RC5/RC6/RC7
    IOCCP |= PHASE_A + PHASE_B + ENTER_N; // positive edge
    IOCCN |= PHASE_A + PHASE_B + ENTER_N; // negative edge

    // Clear any existing IOC flags for port C pins
    IOCCF &= (uint8_t)~(PHASE_A + PHASE_B + ENTER_N);

    // Enable IOC module (power it up) and enable IOC interrupt
    PMD0bits.IOCMD = 0; // enable IOC module
    PIE0bits.IOCIE = 1; // enable IOC interrupt

    // Read initial quadrature state
    unsigned char a = PORTC & PHASE_A ? 1 : 0;
    unsigned char b = PORTC & PHASE_B ? 1 : 0;
    encoder_state.last_state = (uint8_t)((a << 1) | b);

    encoder_state.button_raw = PORTC & ENTER_N ? 1 : 0; // idle high
    encoder_state.button_stable = (encoder_state.button_raw == 0) ? 1 : 0;
    encoder_state.debounce_cnt = 0;
}

/*
 * Get the current encoder position (8-bit, clamped 0..127).
 */
uint8_t encoder_get_position(void) {
    return encoder_state.position;
}

/*
 * Get the current debounced button state. 1 = pressed, 0 = released.
 */
uint8_t encoder_button_state(void) {
    return encoder_state.button_stable;
}

/*
 * Called from ISR when IOC event on RC5/RC6/RC7 detected. Performs a quick
 * sample of the pins and updates position and button raw state. Button
 * debouncing is handled externally. This function is safe to call from ISR
 * context (keeps it short).
 */
void encoder_handle_ioc(void) {
    // Snapshot PORTC once to keep A/B/button sampling coherent during IOC handling
    unsigned char portc = PORTC;

    unsigned char a = (portc & PHASE_A) ? 1U : 0U;
    unsigned char b = (portc & PHASE_B) ? 1U : 0U;
    unsigned char cur = (unsigned char)((a << 1) | b);
    unsigned char last = encoder_state.last_state;
    if (cur != last) {
        if (((last + 1) & 3U) == cur) {
            if (encoder_state.position < 127U) {
                encoder_state.position = (unsigned char)(encoder_state.position + 1U);
            }
        } else if (((last + 3) & 3U) == cur) {
            if (encoder_state.position > 0U) {
                encoder_state.position = (unsigned char)(encoder_state.position - 1U);
            }
        }
        encoder_state.last_state = cur;
    }

    unsigned char braw = (portc & ENTER_N) ? 1U : 0U; // active high when released
    encoder_state.button_raw = braw;
    encoder_state.button_stable = braw; // no internal debounce

    // Clear IOC flags for the handled pins (write 0 to clear)
    IOCCF &= (unsigned char)~(PHASE_A + PHASE_B + ENTER_N);
}

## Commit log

2025-12-18 Initial creation
    [GPSDO.csv, GPSDO.kicad_pcb, GPSDO.kicad_sch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]
2025-12-18 added GPS receive and parse; configuration options; menu options; converted from PID to PI control.
2025-12-21 (lib_symbols (symbol "power:GND" (power) (pin_numbers (hide yes) ) (pin_names (offset 0) (hide yes) ) (exclude_from_sim no) (in_bom yes) (on_board yes) (property "Reference" "#PWR" (at 0 -6.35 0) (ef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
    [logic.kicad_sch]
2025-12-22 updated schematics
    [logic.kicad_sch]
2025-12-23 LCD now working
    [logic.kicad_sch]
2025-12-28 updated gps serial
    [logic.kicad_sch]
2026-01-01 changed uarts and lcd pins
    [logic.kicad_sch]
2026-01-23 Updated PCB
    [GPSDO.kicad_pcb, GPSDO.kicad_sch, logic.kicad_sch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]
2026-01-26 Updated Schematic; Move to SMD
    [GPSDO.kicad_pcb, logic.kicad_sch, ocxo.kicad_sch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]
2026-01-30 Updated PCB; ran DRC; fixing errors
    [GPSDO.kicad_pcb]
2026-01-30 finished pcb drc edits
    [GPSDO.kicad_pcb, logic.kicad_sch]

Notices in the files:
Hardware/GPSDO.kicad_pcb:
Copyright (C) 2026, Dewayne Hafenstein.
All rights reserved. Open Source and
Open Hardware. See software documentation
